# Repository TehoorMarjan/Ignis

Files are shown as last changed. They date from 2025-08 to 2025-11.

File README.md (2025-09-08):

# 🔥 Ignis Project - Ignis Lamp

An autonomous flame-shaped lamp/nightlight controlled by microcontroller with
WS2812B LED ring and **integrated Qi wireless charging**.

<p align="center">
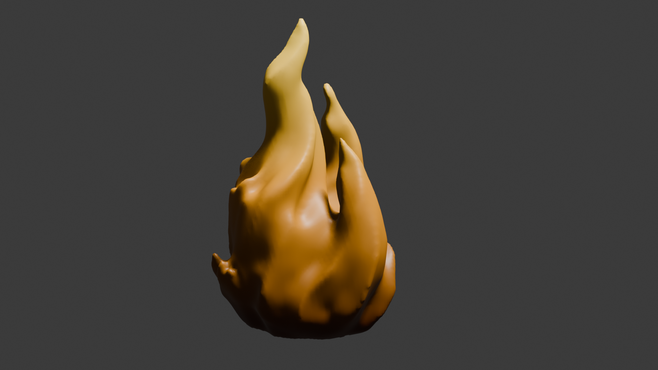
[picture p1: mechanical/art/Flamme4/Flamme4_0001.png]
Flamme4 Preview
  
</p>

**Status** : Hardware validated ✅ - Firmware development in progress  
**Last update** : September 2025

## 🎯 Objectives

- **Autonomy** : 2-3 hours on LiPo battery (320 mAh)
- **LED Patterns** : Heartbeat, chase, fade, realistic flame effects
- **Control** : SW-18030 shock detector for interaction
- **Charging** : **Qi wireless** + automatic power-path management
- **Waterproof** : No USB port, induction charging only

## ⚡ IgnisV2 Electrical Architecture

```mermaid
flowchart TD
  QiCharger["📡 BQ51013B<br/>Qi Charger"] ==> Charger["🔌 BQ24073<br/>Battery Charger"]
  Charger <==> Battery["🔋 LiPo Battery<br/>320mAh"]
  Charger ==> Boost["⚡ FP6277 Boost<br/>3.7V → 5V"]

  subgraph SYS["System"]
    MCU["🖥️ ATtiny212 @ 20MHz"]
    ShockSensor["💥 SW-18030<br/>Shock Sensor"]
    MCU -. "User Interaction" .- ShockSensor
    MCU --> WS2812B["💡 WS2812B<br/>6 LEDs"]
  end

  Boost ==> SYS
  Charger -. "Charge Status" .-> MCU
  QiCharger -. "Coil Status" .-> MCU
```

## 📚 Documentation

This repository contains comprehensive documentation for all aspects of the
Ignis project. Navigate to the relevant sections based on your interests:

### 🎯 Project Management

- [📊 PROJECT_STATUS.md](PROJECT_STATUS.md) - Current project status,
  milestones, and development progress

### 💾 Firmware Development

- [🔧 firmware/README.md](firmware/README.md) - ATtiny212 firmware
  documentation, build instructions, and current implementation

### 🔌 Hardware Design

- [⚡ docs/calculations/electrical_design.md](docs/calculations/electrical_design.md) -
  Complete electrical calculations, component sizing, and power analysis
- [🔗 docs/references/schematics_references.md](docs/references/schematics_references.md) -
  Reference schematics and design patterns
- [📋 docs/datasheets/README.md](docs/datasheets/README.md) - Component
  datasheets and technical specifications

### 🎨 Mechanical Design

- [🖼️ mechanical/art/README.md](mechanical/art/README.md) - 3D artwork and
  Blender models (Flamme4 design)
- [🏗️ mechanical/cad/README.md](mechanical/cad/README.md) - CAD models,
  assemblies, and engineering drawings
- [🖨️ mechanical/stl/README.md](mechanical/stl/README.md) - 3D printable files
  and printing guidelines
- [📏 docs/calculations/filament.md](docs/calculations/filament.md) - 3D
  printing material calculations and optimization

---

**For Contributors**: Start with [PROJECT_STATUS.md](PROJECT_STATUS.md) to
understand current progress, then refer to the relevant documentation sections
above based on your area of contribution.

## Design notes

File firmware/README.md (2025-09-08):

# Ignis Firmware - Ignis Lamp

## Current Project Status

### ✅ Implemented Features

- **WS2812B LED Control** : Implementation with tinyNeoPixel library
- **Light Patterns** : Cycling pattern with 7 colors (Red, Green, Blue, Purple,
  Yellow, Cyan, White)
- **ATtiny212 Configuration** : PlatformIO configured for ATtiny212 (IgnisV2.2)
- **Basic Structure** : Code organized with board.h for hardware abstraction

### 🚧 To Implement

- **Power Management** : Sleep mode management with interrupt wake-up
- **Shock Sensor** : SW18030 integration for shake detection
- **Charge Detection** : Using CHRG_B, PGOOD_B, IND_B pins
- **Advanced Light Patterns** : Heartbeat, fade, realistic flame effects
- **Power Optimizations** : Sleep modes for battery conservation
- **Battery Management** : Charge level monitoring

## Hardware Configuration

- **Microcontroller** : ATtiny212 @ 20MHz (IgnisV2.2 PCB)
- **WS2812B Pin** : PA6 (PIN_LED = PIN_PA6)
- **Shock Sensor Pin** : PA7 (PIN_SSW = PIN_PA7) with RC filter + Schmitt
  trigger
- **Inductor Detection Pin** : PA1 (PIN_IND_B = PIN_PA1) - Low when inductor
  active
- **Battery Charging Pin** : PA2 (PIN_CHRG_B = PIN_PA2) - Low during charging
- **Charge Complete Pin** : PA3 (PIN_PGOOD_B = PIN_PA3) - Low when charging
  complete
- **UPDI Pin** : PA0 (PIN_UPDI = PIN_PA0) for programming
- **LED Count** : 6 WS2812B-2020 LEDs

## Power Management

The firmware aims to implement an optimized power management system:

1. **Active Mode** : WS2812B LED control, sensor monitoring
2. **Inactivity Detection** : Based on SW18030 shock sensor
3. **Sleep Mode** : `SLEEP_MODE_PWR_DOWN` for maximum autonomy
4. **Wake-up** : Interrupt on motion detection or charging
5. **Charge Monitoring** : Using BQ24073 pins for battery status

Test software showed that all 6 LEDs at full brightness consume around

$$
I_{max} = \boxed{380\,\text{mA}} \implies P_{max} = 1.9\,\text{W}
$$

As this is above 1C for the 320mAh battery, power management and brightness
control will be needed to ensure good battery life.

### Power Saving Strategy

- Disable ADC, SPI, timers in sleep mode
- Intelligent PWM for LED brightness control
- Automatic charging station detection (IND_B)
- Adaptive pattern management based on battery level

## Compilation

```bash
# Via VS Code PlatformIO
Ctrl+Shift+P -> "PlatformIO: Build"

# Or via terminal (if pio installed)
cd firmware/
pio run
```

## Upload/Debug

Pymcuprog configuration in `platformio.ini`:

- Programmer : `pymcuprog` via UART
- Device : `attiny212`
- Port : `$UPLOAD_PORT` (defined by PlatformIO)
- Speed : 115200 baud
- UPDI : Programming via PA0

**⚠️ Important** : Generally, the power supplied by the USB-to-serial adapter is
not sufficient to power the board during programming. Attach an external power
supply on the board, if possible by injecting 3.7V (same as battery pack) on the
VSYS drilled pad.

### Pymcuprog Installation

The `scripts/requirements.py` script automatically installs pymcuprog if needed.

```bash
# Manual installation if required
pip install pymcuprog
```

## Next Steps

1. **Hardware Validation** : Test pins and basic functions
2. **Light Patterns** : Implement realistic flame effects
3. **Shock Sensor** : SW18030 integration with interrupts
4. **Power Management** : Sleep modes and intelligent wake-up
5. **Battery Monitoring** : Charge and autonomy management
6. **Autonomy Tests** : Validate 2-3 hour target

## Debug and Development

- Code compiled and tested on IgnisV2.2 PCB
- Using tinyNeoPixel for WS2812B control
- Incremental development for hardware validation
- Power consumption and light pattern testing

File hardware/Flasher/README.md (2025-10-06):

# UPDI Programmer

A simple UPDI programmer for ATtiny and ATmega microcontrollers using a
USB-to-TTL adapter.

<p align="center">
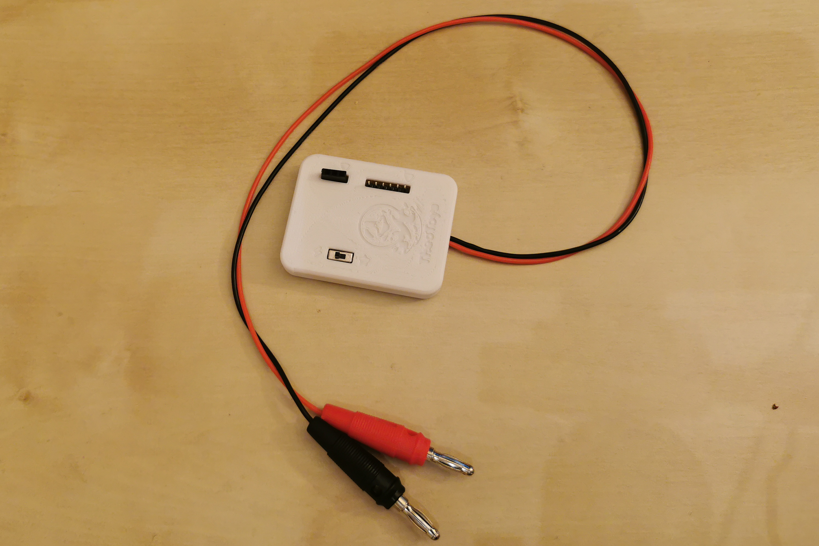
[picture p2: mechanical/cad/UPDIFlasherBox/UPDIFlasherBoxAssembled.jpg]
White 3D-printed UPDI programmer enclosure with black and red banana plug cables resting on a light wooden surface. The enclosure features a visible logo, a power selection switch, and connector ports.
  
</p>

## Overview

This project describes a minimalist UPDI (Unified Program and Debug Interface)
programmer designed for programming Microchip ATtiny and ATmega chips. UPDI is a
simple programming protocol that enables half-duplex communication on a single
wire to the bootloader, allowing reflashing of the device without requiring
complex programming hardware.

## What is UPDI?

UPDI (Unified Program and Debug Interface) is a Microchip-proprietary interface
for external programming and on-chip debugging. It is a successor to the PDI
interface and provides a single-wire, bidirectional half-duplex asynchronous
communication interface. UPDI requires only:

- **Single data wire (UPDI)** for bidirectional half-duplex communication
- **Ground connection (GND)**
- **Power supply (VCC)** - typically 5V for programming
- **Optional RESET line** for high-voltage activation on some devices

This single-wire interface makes it ideal for compact designs and simplified
programming setups compared to traditional 4-wire ISP/ICSP interfaces.

## Hardware Implementation

The implementation is remarkably simple, requiring only:

- A **USB-to-TTL adapter** (such as FTDI FT232RL or similar)
- A **single rectifier diode** between the RX and TX pins
- **Dupont connectors** for easy interfacing
- 2x wires and banana plugs for power connections
- A switch
- A protoboard (e.g., EPLZON)

### Circuit Design

The circuit uses a Schottky diode to combine the TX and RX signals from the UART
interface into a single bidirectional UPDI data line. The diode is connected
with its cathode to TX and its anode to RX, allowing this elegant solution to
enable standard UART hardware to communicate with the half-duplex UPDI protocol
at speeds up to 460800 baud (TURBO mode).

**Key Components:**

- 6-pin male Dupont connector for USB-TTL adapter (FTDI or compatible)
- 3-pin female Dupont connector for target device
- Schottky diode (e.g., CDBM1100-G or BAT85) for TX/RX signal combining
- Power source selection switch (USB-TTL or external power)

**Circuit Schematic:**

```
USB-TTL Adapter          Programmer Circuit          Target Device
                                                      __________________
    TX -------|<|-------,-------------------------- | UPDI
             diode      |                   .------ | GND
    RX -----------------'                   |       | VCC
    VCC --------------------------------------------|__________________
    GND -----------------------------------'
```

### Pinout

**6-Pin Male Connector (USB-TTL Side):** Standard FTDI TTL-232R cable pinout:

- Pin 1: GND (Black wire)
- Pin 2: CTS (Brown wire) - Not used
- Pin 3: VCC/5V (Red wire)
- Pin 4: TX (Orange wire)
- Pin 5: RX (Yellow wire)
- Pin 6: RTS (Green wire) - Not used

**3-Pin Female Connector (Target Device):**

1. **GND** - Ground
2. **Data** - UPDI signal line
3. **VCC** - Power supply (5V)

## Assembly

### Breadboard Prototype

The included Fritzing file (`Flasher.fzz`) provides a breadboard view showing
how components are wired. It is equivalent to how it should be assembled on a
protoboard.

<p align="center">
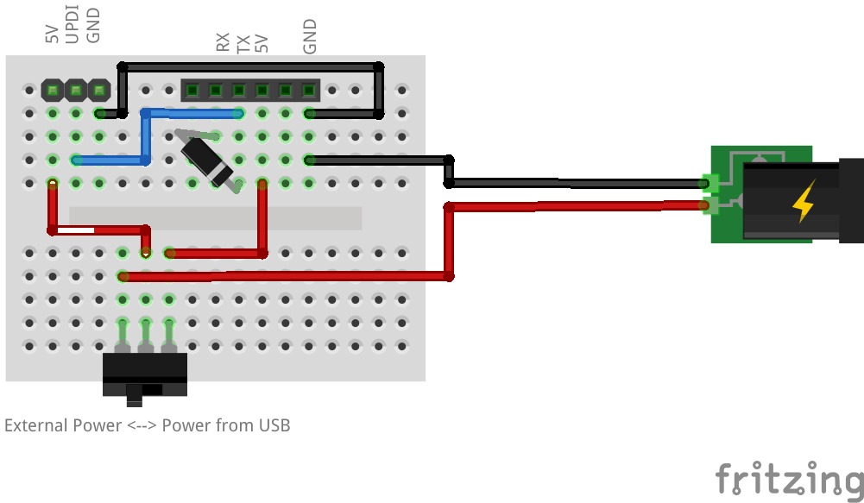
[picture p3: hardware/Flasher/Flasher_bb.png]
Breadboard Layout
  
</p>

## Enclosure

A 3D-printed enclosure is available in
[`/mechanical/cad/UPDIFlasherBox/`](../../mechanical/cad/UPDIFlasherBox/).

<p align="center">
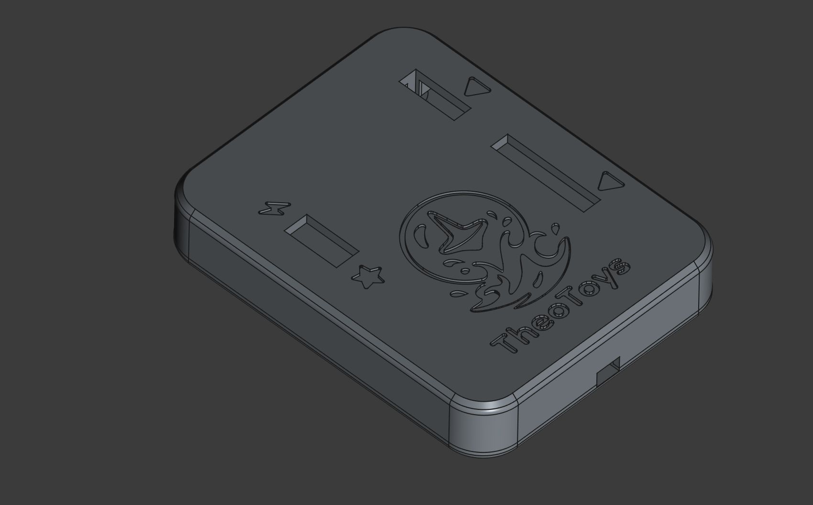
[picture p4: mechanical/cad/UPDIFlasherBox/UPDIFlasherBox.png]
3D render of a compact rectangular enclosure for a UPDI programmer, featuring rounded corners, engraved icons for power and function, a central flame logo, and the text TheoToys on the top surface. The enclosure has cutouts for switches and connectors.
  
</p>

**Features:**

- Custom-fitted for populated EPLZON protoboard
- Screw holes (M2) and slots for threaded inserts (M2xD3xL3)
- Connector access holes (6-pin and 3-pin)
- Switch cutout for power selection
- Side hole for external power cables
- Embossed markings showing:
  - GND pin position on both connectors
  - Power switch icons (USB/External)

**Files:**

- [`UPDIFlasherBox.FCStd`](../../mechanical/cad/UPDIFlasherBox/UPDIFlasherBox.FCStd) - FreeCAD source file
- [`UPDIFlasherBox-Top.stl`](../../mechanical/cad/UPDIFlasherBox/UPDIFlasherBox-Top.stl) - Top cover (ready to print)
- [`UPDIFlasherBox-Bottom.stl`](../../mechanical/cad/UPDIFlasherBox/UPDIFlasherBox-Bottom.stl) - Bottom base (ready to print)

## Additional Resources

### Official Documentation

- [Microchip UPDI Specification](https://onlinedocs.microchip.com/oxy/GUID-19DFE3E8-6314-4CFE-BA69-1357E28C8092-en-US-1/GUID-A2FD739F-A1D8-4C2F-9482-0B8AF9DCF435.html) -
  Official Microchip UPDI interface documentation
- [pymcuprog Tool](https://github.com/microchip-pic-avr-tools/pymcuprog) -
  Microchip's Python programming utility
- [megaTinyCore Library](https://github.com/SpenceKonde/megaTinyCore) - Arduino
  core for modern AVR chips
- [UPDI Protocol Overview](https://github.com/SpenceKonde/AVR-Guidance/blob/master/UPDI/UpdiProgramming.md) -
  Community documentation
- [Teddy Warner's SerialUPDI Guide](https://teddywarner.org/Projects/SerialUPDI/) -
  Excellent detailed tutorial
- [FTDI TTL-232R Cable Datasheet](https://ftdichip.com/wp-content/uploads/2023/07/DS_TTL-232R_CABLES.pdf) -
  Official cable pinout reference
- [EPLZON Protoboards](https://www.amazon.fr/EPLZON-prototypage-Breadboard-électronique-compatibles/dp/B0B4DFTTDR) -
  Recommended protoboard for assembly

## License

MIT License

Copyright (c) 2025 Ignis Project

Permission is hereby granted, free of charge, to any person obtaining a copy of
this software and associated documentation files (the "Software"), to deal in
the Software without restriction, including without limitation the rights to
use, copy, modify, merge, publish, distribute, sublicense, and/or sell copies of
the Software, and to permit persons to whom the Software is furnished to do so,
subject to the following conditions:

The above copyright notice and this permission notice shall be included in all
copies or substantial portions of the Software.

THE SOFTWARE IS PROVIDED "AS IS", WITHOUT WARRANTY OF ANY KIND, EXPRESS OR
IMPLIED, INCLUDING BUT NOT LIMITED TO THE WARRANTIES OF MERCHANTABILITY, FITNESS
FOR A PARTICULAR PURPOSE AND NONINFRINGEMENT. IN NO EVENT SHALL THE AUTHORS OR
COPYRIGHT HOLDERS BE LIABLE FOR ANY CLAIM, DAMAGES OR OTHER LIABILITY, WHETHER
IN AN ACTION OF CONTRACT, TORT OR OTHERWISE, ARISING FROM, OUT OF OR IN
CONNECTION WITH THE SOFTWARE OR THE USE OR OTHER DEALINGS IN THE SOFTWARE.

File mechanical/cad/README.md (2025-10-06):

# 🔧 Mechanical CAD - Projet Ignis

This folder contains all the CAD models and mechanical designs for the Ignis
project, created using **FreeCAD**. These models support the hardware
development, PCB visualization, and testing workflow.

## 🧩 SW18030 Shock Sensor

<p align="center">
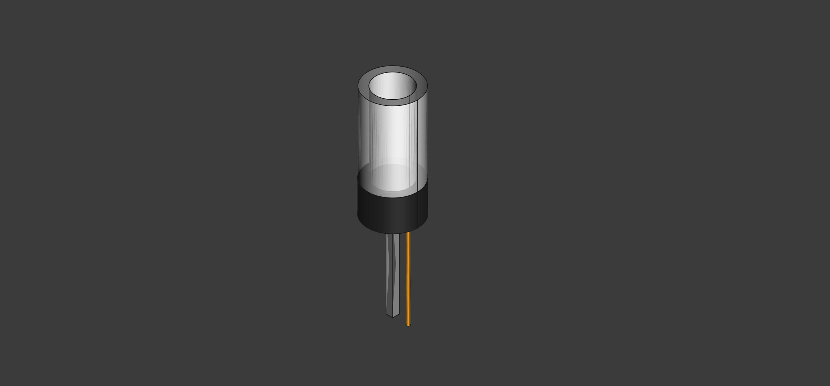
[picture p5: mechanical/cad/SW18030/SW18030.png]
SW18030 3D Model
  
</p>

Custom 3D model of the SW18030 vibration/shock sensor since it's not available
in standard CAD/footprint databases.

- Not fully detailed model - focused on mechanical envelope and mounting points
- Proper dimensions for mechanical clearance checks

## 🧩 Battery Pack Model

<p align="center">
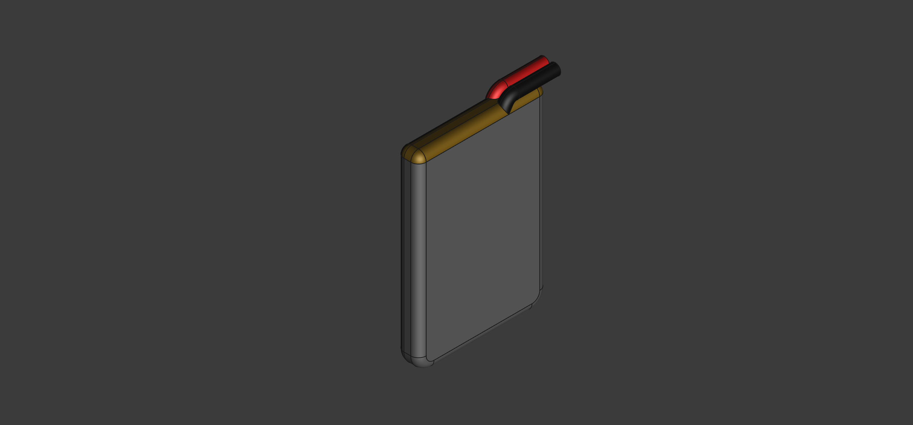
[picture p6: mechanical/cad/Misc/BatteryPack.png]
Battery Pack 3D Model
  
</p>

3D representation of the EEMB LP402535 (320mAh) LiPo battery for integration
visualization.

**Specifications**:

- Dimensions: 35×25×4mm (matches datasheet)
- Wire placement and routing visualization
- Proper dimensions for mechanical clearance checks

## 🧩 Qi Receiver Coil Model

<p align="center">
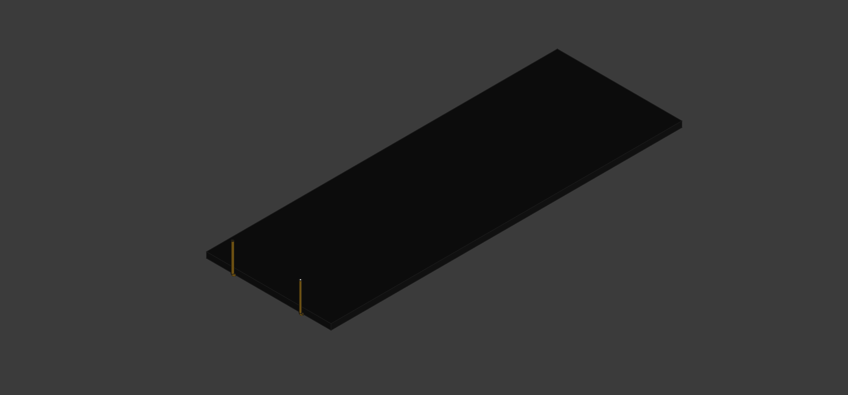
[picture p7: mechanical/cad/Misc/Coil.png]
Qi Coil 3D Model
  
</p>

Quick 3D model of the IWAS3010AZEB130KF1 Qi receiver coil for mechanical
integration.

- Dimensions: 30×10×1mm (rectangular coil)
- Wire routing and connection points
- Simplified geometry focused on mechanical envelope - actual coil winding not
  modeled in detail.

## 🧩 TestStand - PCB Test Fixture

<p align="center">
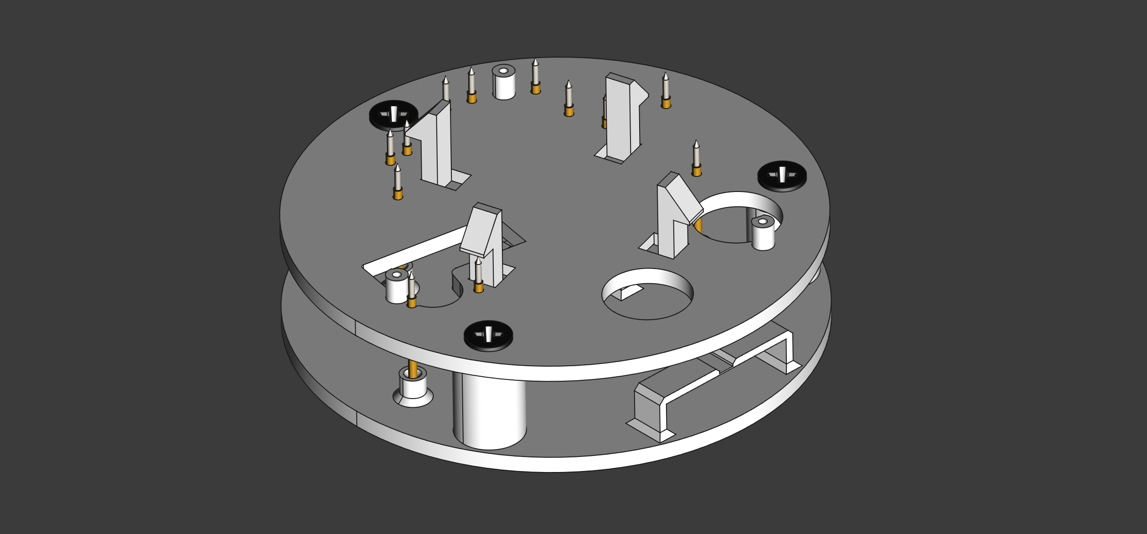
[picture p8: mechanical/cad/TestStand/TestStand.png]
TestStand 3D Model
  
</p>

<p align="center">
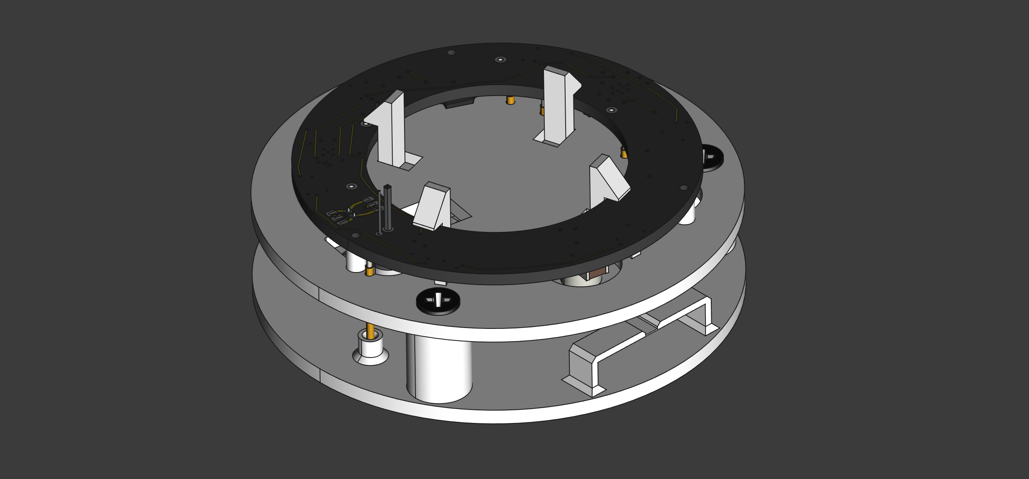
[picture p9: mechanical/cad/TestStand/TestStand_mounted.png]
TestStand Mounted View
  
</p>

<p align="center">
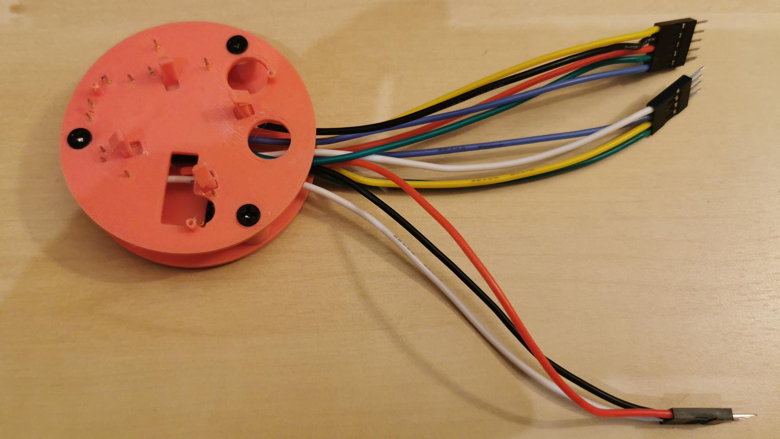
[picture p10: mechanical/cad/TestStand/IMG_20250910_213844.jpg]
TestStand Mounted View
  
</p>

Custom test fixture for IgnisV2.2 PCB programming and validation with pogo pin
connections.

**Files**:

- `TestStand.FCStd` - FreeCAD source file
- `TestStand-Top.stl` - Upper part for 3D printing
- `TestStand-Bottom.stl` - Lower part with pogo pin holders
- `TestStand-Hook.stl` - PCB retention hooks

**Features**:

- Positioned pogo pins to match IgnisV2.2 test pads
- Top and Bottom disks to hold the pogo pins securely
- Hooks hold board under test in position
- Cable management

### ⚠️ Version 1 - Known Issues

1. **Hook attachment**: Difficult to glue hooks on top part - redesign needed
2. **Cable holders**: Too fragile, already broken on printed version
3. **Pogo pins**: Missing pins for drilled pads (pins are too thin)

**Note**: It was expected that the pogo pins would not fit the drilled pads
because it was planned to hook cables. This works great, but finally it is nice
also that the testing stand can access all the pads at the same time. And I
forgot to add specific testing pads for the signals that already had drilled
pads.

**Note**: Next time, I shall pay more attention to the position of the testing
pads with respect to the other components and mounting holes. It is clear from
this test stand that some pads are difficult to reach, specially when a
component needs a clearance in the Top part because it is too tall. Also, I've
read that testing pads are better placed on the rear side of the PCB. I've read
that too late in the design process and now I understand why!

## 🧩 TestStand V2 - PCB Test Fixture

<p align="center">
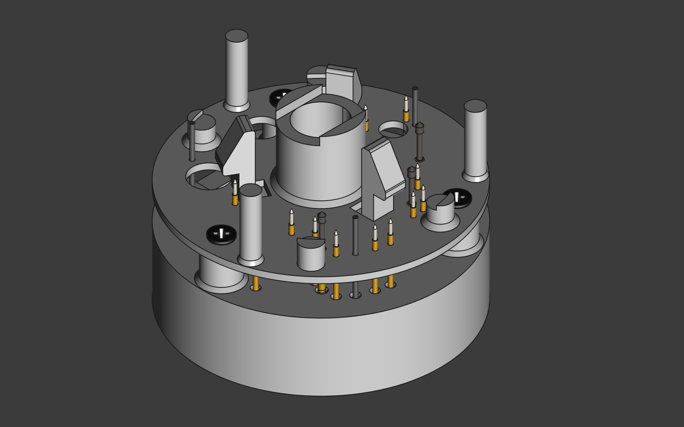
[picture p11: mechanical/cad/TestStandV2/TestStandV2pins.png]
TestStand 3D Model
  
</p>

<p align="center">
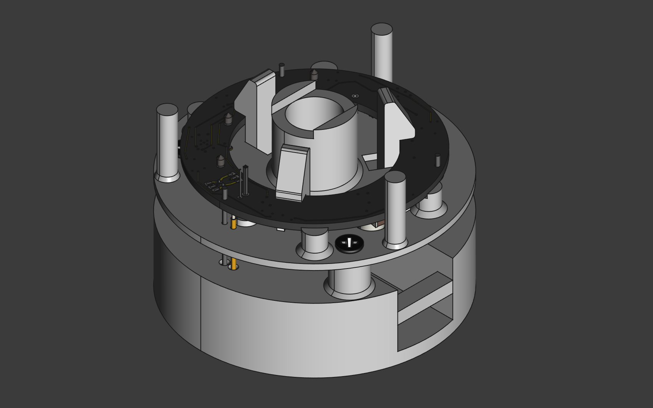
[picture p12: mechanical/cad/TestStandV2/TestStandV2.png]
TestStand Mounted View
  
</p>

<p align="center">
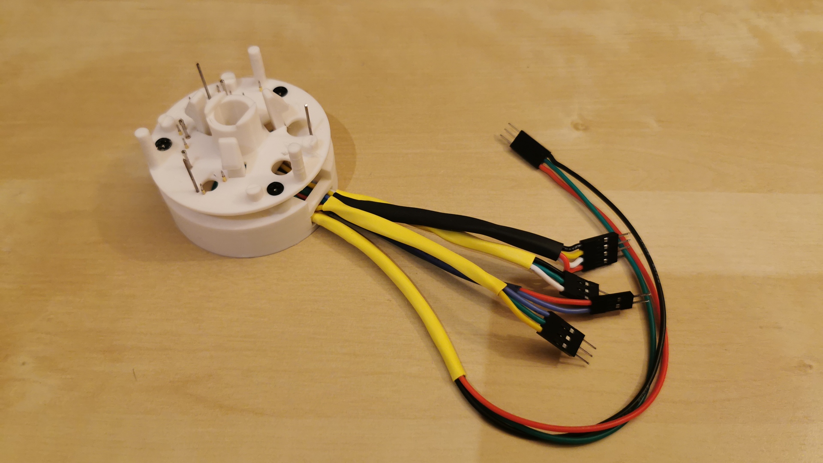
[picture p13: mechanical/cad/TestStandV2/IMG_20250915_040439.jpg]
TestStand Real View
  
</p>

<p align="center">
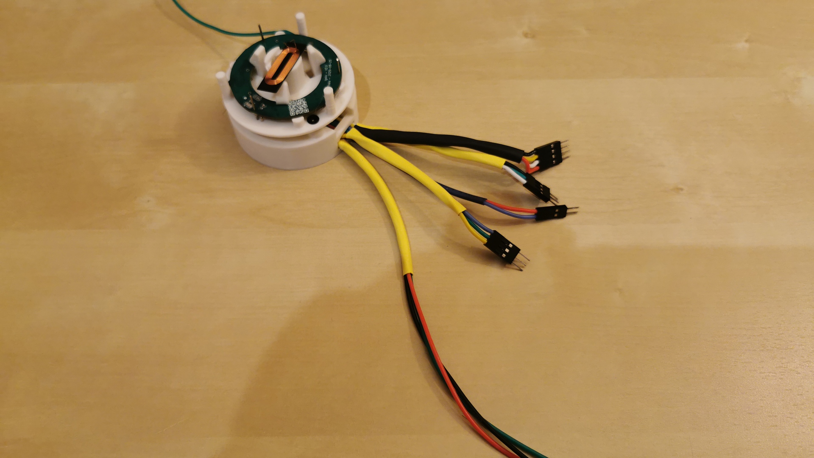
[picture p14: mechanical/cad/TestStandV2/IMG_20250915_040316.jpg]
TestStand Real Mounted View
  
</p>

Custom test fixture for IgnisV2.2 PCB programming and validation with pogo pin
connections.!

**Files**:

- `TestStandV2.FCStd` - FreeCAD source file
- `TestStandV2-Guide.stl` - Upper part for 3D printing
- `TestStandV2-Base.stl` - Lower part with pogo pin holders
- `TestStandV2-Hook.stl` - PCB retention hooks
- `TestStandV2.3mf` - 3D model file for 3D printing (OrcaSlicer)
- `IgnisV2TP.csv` - Test pad assignment to connector, position and cable colors

**Features**:

- Positioned pogo pins to match IgnisV2.2 test pads and drilled holes
- Base and Guide disks to hold the pogo pins securely
- Sticks to guide the PCB through its testing holes
- Hooks hold board under test in position
- Cable management

## 🧩 UPDI Flasher Box

<p align="center">
  UPDI Flasher Box 3D Model
</p>

<p align="center">
  UPDI Flasher Box Real Assembly
</p>

Custom enclosure for the UPDI programmer used to flash the ATtiny212 microcontroller on the Ignis board.

**Files**:

- `UPDIFlasherBox.FCStd` - FreeCAD source file
- `UPDIFlasherBox-Top.stl` - Upper part for 3D printing
- `UPDIFlasherBox-Bottom.stl` - Lower part for 3D printing

**Features**:

- Simple single-wire UPDI protocol implementation using UART (RX/TX)
- Diode-based direction selection for RX/TX communication
- Built on protoboard for easy prototyping and modifications
- Power selection switch between USB power and external PSU
- Two-wire connection for external power supply (standard PSU)
- Compact enclosure protecting the protoboard circuit
- Easy access to programming connections

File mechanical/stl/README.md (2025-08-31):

# 🧊 STL & Exports Imprimables - Projet Ignis

Ce dossier regroupe les fichiers STL prêts pour l'impression 3D, issus des
modèles artistiques du projet Lampe Ignis.

## 📚 Contexte

Les modèles originaux sont créés sous Blender (`art/<model>.blend`), puis
exportés en STL (`art/<model>.stl`). Pour garantir une impression fiable et des
unités correctes, les fichiers STL sont retravaillés sous OrcaSlicer :

- **Import STL Blender**
- **Conversion unités en mm**
- **Simplification et nettoyage du maillage**
- **Export final** : `stl/<model>.stl`

Pour plus d'informations sur le contexte artistique, voir le
[README du dossier art](../art/README.md).

## 🛠️ Workflow d'export

1. **Modélisation** : Blender (`art/<model>.blend`)
2. **Export STL** : Blender (`art/<model>.stl`)
3. **Nettoyage** : OrcaSlicer (`stl/<model>.stl`)
   - Conversion unités
   - Simplification du maillage
   - Vérification de l'intégrité

> Un remaillage avancé sous Blender serait probablement plus puissant, mais
> OrcaSlicer offre une solution rapide et efficace pour préparer les fichiers à
> l'impression.

## 📁 Organisation

- `stl/Flamme1.stl` : Export final du design Flamme1
- `stl/Flamme2.stl` : Export final du design Flamme2
- `stl/Flamme3.stl` : Export final du design Flamme3 (Flamme3_4)

---

**Pour toute information sur les modèles originaux ou le contexte artistique,
consultez le README du dossier art.**

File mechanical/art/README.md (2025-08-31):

# 🖼️ Art & Design - Lampe Ignis

Ce dossier regroupe les modèles artistiques 3D pour la Lampe Ignis, une lampe en
forme de flamme.

## 📚 Contexte

La Lampe Ignis est une veilleuse autonome en forme de flamme, pilotée par
microcontrôleur et LEDs adressables. Sa particularité : le socle contient du
sable, renfermant un élément mystérieux ou précieux, renforçant l'aspect
décoratif et symbolique du projet. Pour plus d'informations sur l'architecture,
l'électronique et le firmware, consultez les README principaux :

- [README général](../../README.md)
- [README firmware](../../firmware/README.md)
- [README datasheets](../../docs/datasheets/README.md)

## 🎨 Versions de Design

### Flamme1

- **Description** : Design simple, représentant uniquement la flamme.
- **Fichiers** :
  - [`Flamme1.blend`](Flamme1/Flamme1.blend) (modèle Blender)
  - [`Flamme1.stl`](Flamme1/Flamme1.stl) (export impression 3D)
  - [`Flamme1_0001.png`](Flamme1/Flamme1_0001.png) (screenshot)

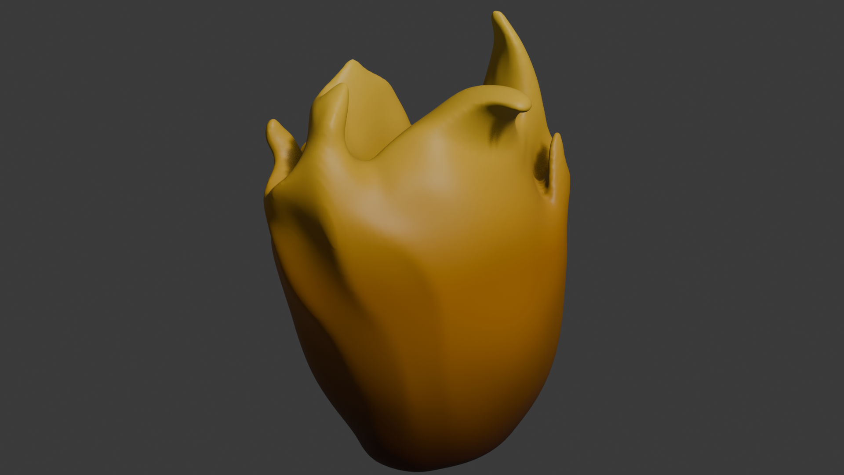
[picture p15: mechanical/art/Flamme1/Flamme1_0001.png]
Screenshot Flamme1


### Flamme2

- **Description** : Variante du design Flamme1, avec un "visage" retravaillé et
  ajout d'yeux.
- **Fichiers** :
  - [`Flamme2.blend`](Flamme2/Flamme2.blend) (modèle Blender)
  - [`Flamme2.stl`](Flamme2/Flamme2.stl) (export impression 3D)
  - [`Flamme2_0000.png`](Flamme2/Flamme2_0000.png) (screenshot)

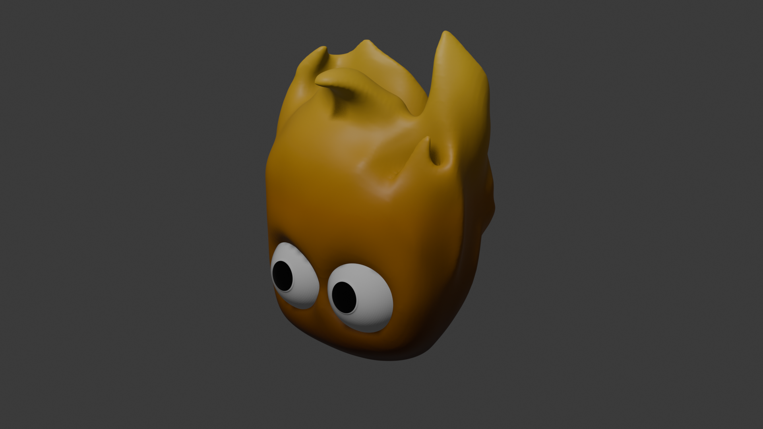
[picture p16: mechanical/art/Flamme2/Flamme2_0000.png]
Screenshot Flamme2


### Flamme1 - Low Poly

- **Description** : Version simplifiée et stylisée de Flamme1, avec un maillage
  réduit pour un rendu low poly sympa. Les dimensions ont également été
  retravaillées (objet plus petit, 75cm de large, même proportions) et le
  fichier STL a les bonnes dimensions.
- **Fichiers** :
  - [`Flamme1_lowpoly.blend`](Flamme1/Flamme1_lowpoly.blend) (modèle Blender)
  - [`Flamme1_lowpoly.stl`](Flamme1/Flamme1_lowpoly.stl) (export impression 3D)
  - [`Flamme1_lowpoly_0001.png`](Flamme1/Flamme1_lowpoly_0001.png) (screenshot)

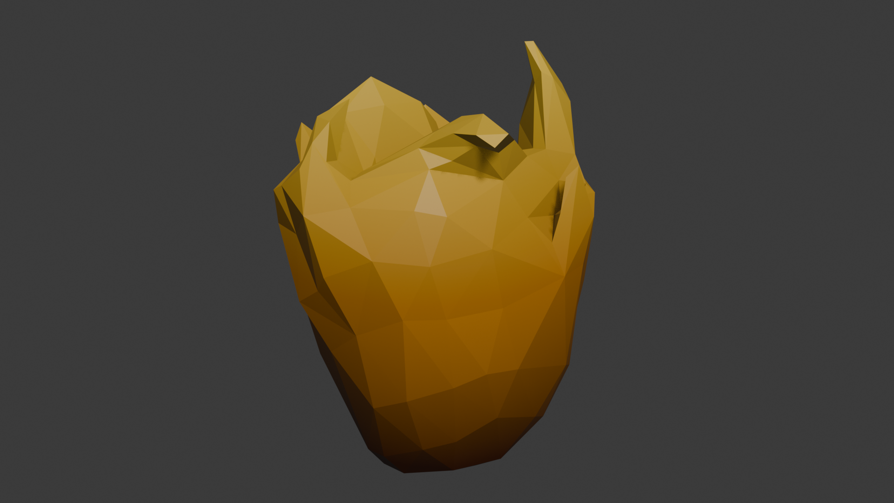
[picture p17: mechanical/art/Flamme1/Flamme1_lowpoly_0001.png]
Screenshot Flamme1 - Low Poly


### Flamme3_1

- **Description** : Premier essai pour designer une flamme à partir d'un mesh
  travaillé et des modifiers subdivision surface et deform (twist).
  **Abandonné**.
- **Fichiers** :
  - [`Flamme3_1.blend`](Flamme3/Flamme3_1.blend) (modèle Blender)
  - [`Flamme3_1_0001.png`](Flamme3/Flamme3_1_0001.png) (screenshot)

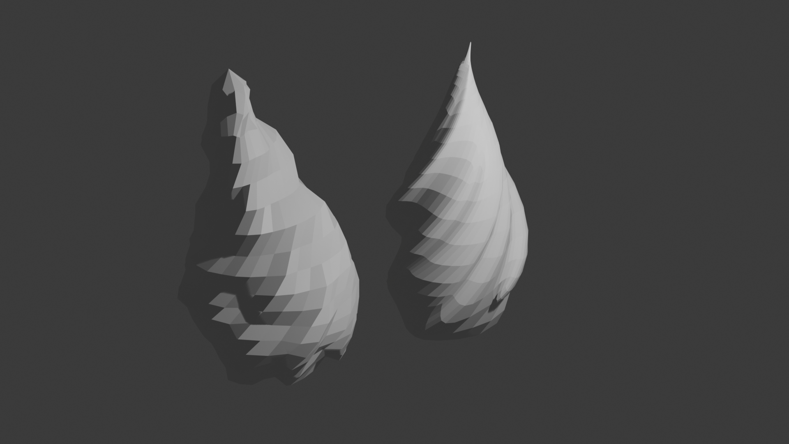
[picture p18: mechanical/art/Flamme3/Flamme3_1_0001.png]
Screenshot Flamme3_1


### Flamme3_2

- **Description** : Flamme créée à partir de meshs sphériques puis des modifiers
  Displace, Deform (Twist), Curve et autres. Sert de base aux versions
  suivantes.
- **Fichiers** :
  - [`Flamme3_2.blend`](Flamme3/Flamme3_2.blend) (modèle Blender)
  - [`Flamme3_2_0001.png`](Flamme3/Flamme3_2_0001.png) (screenshot)

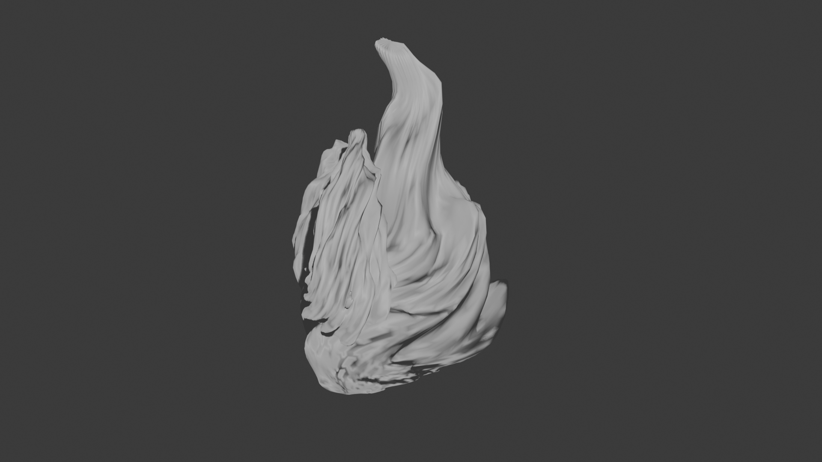
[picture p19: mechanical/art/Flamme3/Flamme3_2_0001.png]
Screenshot Flamme3_2


### Flamme3_3

- **Description** : Mesh de Flamme3_2 combiné et sculpté, mais beaucoup de
  détails perdus pendant la sculpture.
- **Fichiers** :
  - [`Flamme3_3.blend`](Flamme3/Flamme3_3.blend) (modèle Blender)
  - [`Flamme3_3_0001.png`](Flamme3/Flamme3_3_0001.png) (screenshot)

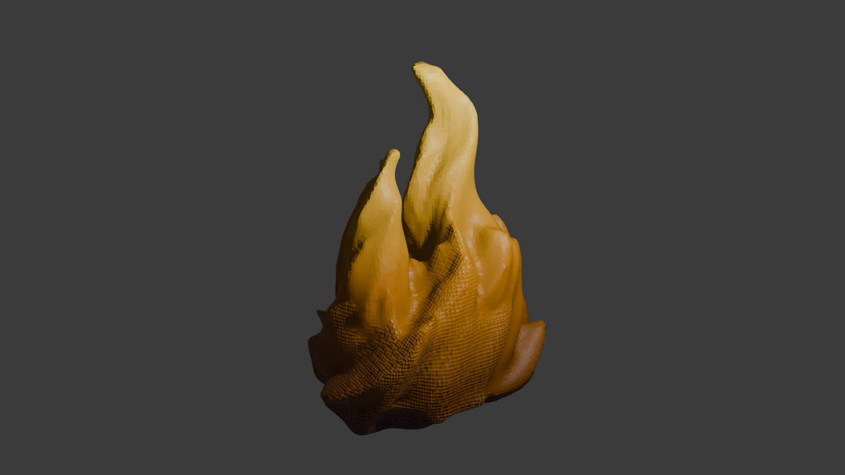
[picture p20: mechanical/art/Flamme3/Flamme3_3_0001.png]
Screenshot Flamme3_3


### Flamme3_4

- **Description** : Mesh de Flamme3_2 repris à zéro et sculpté plus doucement.
- **Fichiers** :
  - [`Flamme3_4.blend`](Flamme3/Flamme3_4.blend) (modèle Blender)
  - [`Flamme3_4.stl`](Flamme3/Flamme3_4.stl) (export impression 3D)
  - [`Flamme3_4_0001.png`](Flamme3/Flamme3_4_0001.png) (screenshot)

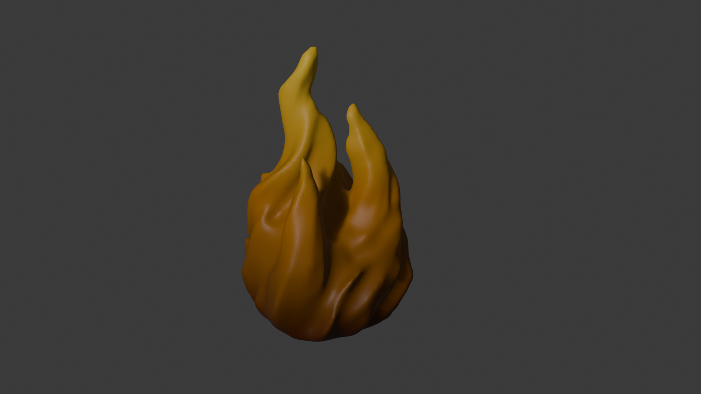
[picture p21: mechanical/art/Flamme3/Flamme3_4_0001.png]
Screenshot Flamme3_4


### Flamme4 ⭐

- **Description** : Mesh de Flamme3_4 repris pour régler les problèmes de
  surplombs et créer une épaisseur, puis sculpté de l'intérieur pour éviter les
  surplombs internes, puisque la forme est désormais creuse.
- Note : Les unités sont mieux paramétrées dans ce fichier, l'export STL est
  propre, mais uniquement si la case "Include Units" n'est _pas_ cochée.
- **Fichiers** :
  - [`Flamme4.blend`](Flamme4/Flamme4.blend) (modèle Blender)
  - [`Flamme4.stl`](Flamme4/Flamme4.stl) (export impression 3D)
  - [`Flamme4_0001.png`](Flamme4/Flamme4_0001.png) (screenshot)

Screenshot Flamme4

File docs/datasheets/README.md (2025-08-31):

# 📋 Datasheets - Projet Ignis

Index des datasheets téléchargées pour le projet Lampe Ignis.

## 🔗 Composants Principaux

| Composant | Fichier | Description |
| --- | --- | --- |
| **ATtiny212** | [`ATtiny212_datasheet.pdf`](ATtiny212_datasheet.pdf) | Microcontrôleur principal, ultra-low-power |
| **WS2812B** | [`WS2812B_datasheet.pdf`](WS2812B_datasheet.pdf) | LEDs adressables RGB, 5V |
| **TP4056** | [`TP4056_datasheet.pdf`](TP4056_datasheet.pdf) | Contrôleur de charge LiPo |
| **FP6277** | [`FP6277_datasheet.pdf`](FP6277_datasheet.pdf) | Boost converter synchrone 5V |
| **DMP1045U** | [`DMP1045U_datasheet.pdf`](DMP1045U_datasheet.pdf) | P-MOSFET pour power-path management |
| **EEMB LP402535** | [`EEMB_LP402535_datasheet.pdf`](EEMB_LP402535_datasheet.pdf) | Batterie LiPo 320mAh |

## 📊 Caractéristiques Clés

### ATtiny212

- **Architecture** : AVR 8-bit RISC
- **Flash** : 2KB
- **RAM** : 128 bytes
- **EEPROM** : 64 bytes
- **Fréquence** : jusqu'à 20 MHz
- **Alimentation** : 1.8V - 5.5V
- **Programmation** : UPDI

### WS2812B

- **Type** : LED RGB intégrée avec driver
- **Alimentation** : 5V ± 0.5V
- **Courant** : ~60mA max par LED
- **Interface** : Signal digital unique
- **Protocole** : PWM temporisé

### TP4056

- **Type** : Contrôleur de charge Li-Ion/LiPo
- **Tension charge** : 4.2V ± 1%
- **Courant** : Programmable via résistance (jusqu'à 1A)
- **Protection** : Surtension, surintensité, thermique
- **Package** : SOP-8

### FP6277

- **Type** : Boost converter synchrone
- **Tension entrée** : 0.9V - 5V
- **Tension sortie** : 5V fixe
- **Courant** : jusqu'à 1.5A
- **Efficacité** : >90%
- **Fréquence commutation** : 1.2MHz

### DMP1045U

- **Type** : P-Channel Enhancement MOSFET
- **VDS max** : -30V
- **ID max** : -4.2A
- **RDS(on)** : 45mΩ @ -4.5V
- **Package** : SOT-23

### EEMB LP402535

- **Capacité nominale** : 320mAh
- **Tension nominale** : 3.7V
- **Courant décharge max** : 2C (640mA)
- **Courant recommandé** : 1C (320mA)
- **Cycles** : >500 cycles
- **Dimensions** : 35×25×4.0mm

## 🔧 Notes de Conception

### Courant Total Estimé

- 8 LEDs × 60mA = 480mA max
- ATtiny212 = ~5mA
- **Total** : ~485mA (1.5C de la batterie)

⚠️ **Attention** : Prévoir limitation logicielle pour rester sous 1C (320mA) en
usage continu

### Efficacité Boost

- Perte boost converter ~10%
- Courant batterie estimé : 485mA / 0.9 ≈ 540mA
- **Autonomie estimée** : 320mAh / 540mA ≈ 35 minutes à pleine puissance

### Recommandations

1. Limiter brightness des LEDs (PWM ~50%)
2. Patterns optimisés (pas toutes LEDs simultanément)
3. Sleep mode agressif quand inactif

## 📁 Organisation

```
docs/datasheets/
├── ATtiny212_datasheet.pdf      # MCU principal
├── WS2812B_datasheet.pdf        # LEDs RGB
├── TP4056_datasheet.pdf         # Chargeur LiPo
├── FP6277_datasheet.pdf         # Boost 5V
├── DMP1045U_datasheet.pdf       # Power-path MOSFET
├── EEMB_LP402535_datasheet.pdf  # Batterie LiPo
└── README.md                    # Ce fichier
```

---

**Dernière mise à jour** : 15 août 2025  
**Status** : Datasheets complètes ✅

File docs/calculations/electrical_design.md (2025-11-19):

# Electrical Calculations - Ignis Project

## Battery and Consumption Calculations

### EEMB LP402535 Battery (320 mAh)

- Nominal capacity: 320 mAh
- Nominal voltage: 3.7 V
- Internal resistance: 160 mΩ
- Charging:
  - Maximum current: 320 mA (1C)
  - Maximum voltage: 4.2 V
  - End-of-charge current: 6.4 mA
- Discharge:
  - Maximum current: 2C = 640 mA
  - Minimum voltage: 2.75 V
- Operating temperature:
  - Discharge: -20 °C to +60 °C
  - Charge: 0 °C to +45 °C

### Current Consumption per Component

| Component | Current (mA) | Notes |
| --- | --- | --- |
| ATtiny212 (active) | 3–5 | @ 20 MHz, 5 V |
| ATtiny212 (sleep)  | 0.1–1 | Power-down mode |
| WS2812B (per LED)  | 0.3–60 | 0.3 mA off, 60 mA full white |
| MCP73871 (standby) | 18 µA | Very low in standby |
| BQ51013B (standby) | 30 µA | Inactive Qi receiver |
| FP6277 (standby) | 50–100 µA | Very low in standby |

### Usage Scenarios

#### Scenario 1: 6 LEDs, 50% brightness

```
LEDs: 6 × 30 mA = 180 mA
MCU: 5 mA
Boost: 2 mA (estimated losses)
TOTAL: ~187 mA

Runtime: 320 mAh / 187 mA = 1.7 hours
```

#### Scenario 2: 8 LEDs, 75% brightness

```
LEDs: 8 × 45 mA = 360 mA
MCU: 5 mA
Boost: 3 mA
TOTAL: ~368 mA

Runtime: 320 mAh / 368 mA = 0.87 hours
⚠️ Exceeds recommended 1C, OK for occasional use
```

#### Scenario 3: Standby mode (patterns off)

```
MCU (sleep): 0.5 mA
LEDs (off): 8 × 0.3 = 2.4 mA
Boost (standby): 0.1 mA
TOTAL: ~3 mA

Runtime: 320 mAh / 3 mA = 106 hours (4.4 days)
```

## Qi Receiver - BQ51013B

### General Characteristics

- **Type**: Qi receiver WPC v1.2 (BPP - Baseline Power Profile)
- **Power**: Up to 5 W
- **Output voltage**: Regulated 5 V
- **Max current**: 1 A
- **Frequency**: 100–250 kHz (WPC band)
- **Communication**: ASK/FSK with transmitter
- **FOD**: Built-in Foreign Object Detection

### Receiver Coil - IWAS3010AZEB130KF1 (Vishay)

**Specifications**:

- Dimensions: 30 mm × 10 mm (rectangular shape)
- Inductance: 12.9 µH @ 100 kHz
- Quality factor Q: 11
- DC resistance: 780 mΩ
- Max power: 3.5 W
- Max current: 800 mA
- Qi compliance: WPC v1.2

### Resonant Capacitor Calculations

The BQ51013B requires two resonant capacitors:

**C1 (series)** – Main resonant capacitor:
$$C_1 = \frac{1}{(2\pi \times f_S)^2 \times L_S^\prime}$$

With $L_S^\prime \approx 15\,\mu H$ in our case (to be confirmed) and
$f_S = 100\,\text{kHz}$ (from the BQ51013B documentation):

$$C_1 \approx 168{,}868\,\text{nF}$$

We can choose $C_1 = 150\,\text{nF}$ or
$C_1 = 150\,\text{nF} + 15\,\text{nF} = 165\,\text{nF}$. At this stage this is
an implementation detail. To some extent, the 2-capacitor version can offer
better tunability, especially since $L_S^\prime$ is not fully known at this
point. The frequency error would then be $\leq 2.7\%$.

**C2 (parallel)** – Fine-tuning capacitor:

With $L_S = 12.9\,\mu H$ (unloaded inductance, from the coil datasheet) and
$f_D = 1\,\text{MHz}$ (from the BQ51013B datasheet):

$$C_2 = \frac{1}{(2\pi \times f_D)^2 \times L_S - \frac{1}{C_1}}$$

which gives $C_2 \approx 1.987\,\text{nF} \text{ to } 1.989\,\text{nF}$
depending on whether $C_1 = 165\,\text{nF}$ or $C_1 = 150\,\text{nF}$ is chosen,
i.e. practically no difference. We can therefore choose $C_2 = 2\,\text{nF}$ or
$C_2 = 1\,\text{nF} + 1\,\text{nF}$.

### R_ILIM Calculation

The current limit of the BQ51013B is set via resistor $R_{ILIM}$ according to:

$$
R_{ILIM} = \frac{K_{ILIM}}{I_{MAX}}
$$

where $K_{ILIM}$ is given in the datasheet ($614\,\Omega\text{A}$), and
$I_{MAX}$ is the desired maximum current.

The datasheet specifies that the actual limit current is:

$$
I_{ILIM} = 1.2 \times I_{MAX} = \frac{K_{ILIM}}{R_{ILIM}}
$$

$R_{ILIM}$ is the sum of two resistors:

$$
R_{ILIM} = R_1 + R_{FOD}
$$

with $R_{FOD}$ by default at $196\,\Omega$.

For $I_{MAX} \geq 600\,\text{mA}$, $I_{ILIM} = 720\,\text{mA}$

$$
R_{ILIM} = \frac{614}{0.72} \approx 436\,\Omega \implies R_1 = 240\,\Omega
$$

In practice, with $R_{FOD} = 196\,\Omega$, we choose $R_1 = 220\,\Omega$
(standard value):

$$
R_{ILIM} = 220 + 196 = 416\,\Omega \implies I_{ILIM} \approx 754\,\text{mA} \implies I_{MAX} \approx 629\,\text{mA}
$$

### BQ51013B Components

- C1a (series): 150 nF, 25 V, X7R
- C1b (series): 15 nF, 25 V, X7R
- C2a (parallel): 1 nF, 25 V, X7R
- C2b (parallel): 1 nF, 25 V, X7R
- C3 (RECT): 10 µF + 10 µF + 0.1 µF, 16 V
- C4 (OUT): 10 µF + 0.1 µF, 16 V
- C5 (BOOT): 10 nF, 25 V
- C6 (CLAMP): 470 nF, 25 V
- C7 (COMM): 47 nF, 25 V
- R1 (ILIM): 220 Ω
- Rfod (FOD): 196 Ω
- Ros (RECT): 20 kΩ

### Pin Configuration

- **AC1/AC2**: Receiver coil connection
- **RECT**: Rectified voltage (~8–10 V)
- **OUT**: Regulated 5 V output
- **AD**: Tied to GND via 1 µF (no dual-power management)
- **EN**: Enable, 10 kΩ pull-up to OUT
- **TS/CTRL**: Configuration, see datasheet

## Battery Charger - BQ24073

The BQ24073 from Texas Instruments is a switching Li-ion/Li-Po charger with
integrated power-path management:

- High-efficiency switching charger (vs linear)
- Automatic power-path management
- Compatible with Qi receiver BQ51013B (same manufacturer)
- Built-in thermal and electrical protection
- Status indication via CHG and PGOOD pins
- Input current management via EN1/EN2

### Charge Programming

The charge current is set via resistor $R_{ISET}$ connected from the ISET pin to
VSS: $$R_{ISET} = \frac{K_{ISET}}{I_{CHARGE}}$$

$$
K_{ISET} = 890\,\Omega\text{A} \implies R_{ISET} = \frac{890}{0.32} \approx 2781\,\Omega \approx \boxed{2.7\,k\Omega}
$$

$$
R_{TMR} = \frac{t_{MAXCHG}}{10 \times K_{TMR}}\,\text{with}\, K_{TMR} = 48 \text{s}/\text{k}\Omega
$$

For a 1 C charge (320 mA), the theoretical duration is 1 h. In practice, the
charge proceeds in two phases:

- **CC phase (constant current)**: 320 mA up to around 4.2 V, i.e. 40 to 50 min
  to reach 70 to 80% of the capacity.
- **CV phase (constant voltage)**: voltage remains at 4.2 V, current gradually
  decreases down to the termination threshold (typically 0.1 C to 0.05 C),
  adding 20 to 50 min.

As a rule of thumb:

- Termination at 0.1 C (32 mA): total duration 1.2 to 1.4 h.
- Termination at 0.05 C (16 mA): total duration 1.4 to 1.8 h.

A pre-charge at low current (0.05–0.1 C) can add 10 to 20 min if the cell is
very discharged.

We therefore take a typical charge time between 1.2 and 1.6 h at 1 C, depending
on termination threshold, temperature, and initial state of the battery.

We choose $t_{MAXCHG}$ as twice the expected duration to cover cases of reduced
current:

$$
t_{MAXCHG} = 2 \times 1.6\,\text{h} = 3.2\,\text{h} = 11\,520\,\text{s} \\
\implies R_{TMR} = \frac{11 520}{10 \times 48} = \boxed{24\,\text{k}\Omega}
$$

### Input Current Limitation

For this project, we use the programmable mode (EN2=1, EN1=0) to adjust the
input limit according to the Qi receiver capability. Compute $R_{ILIM}$ to set
the maximum current to ≤ 629 mA.

$$R_{ILIM} = \frac{K_{ILIM}}{I_{IN\_MAX}}$$

$$
K_{ILIM} = 1550\,\Omega\text{A} \implies R_{ILIM} = \frac{1550}{0.629} \approx 2.46\,k\Omega \approx \boxed{2.4\,k\Omega}
$$

### BQ24073 Components (to be used)

- C_IN: 1 µF, 16 V, X7R
- C_BAT: 4.7 µF, 16 V, X7R
- C_OUT: 4.7 µF, 16 V, X7R
- R_TS: 10 kΩ (fixed, replaces thermistor)
- R_ILIM: 2.4 kΩ
- R_ISET: 2.7 kΩ
- R_TMR: 24 kΩ

## FP6277 Boost Configuration

### Output Voltage Setting (5 V)

The output voltage is defined by the feedback divider:

$$
V_{out} = 0.6\,\text{V} \times \left(1 + \frac{R_1}{R_2}\right)
$$

For $V_{out} = 5\,\text{V}$:

$$
5 = 0.6 \times \left(1 + \frac{R_1}{R_2}\right) \\
\frac{R_1}{R_2} = \frac{5}{0.6} - 1 = 7.33
$$

If $R_2 = 10\,\text{k}\Omega$ then
$R_1 = 73.3\,\text{k}\Omega \approx 75\,\text{k}\Omega$

### Optimal Inductance Calculation

The optimal inductance for the FP6277 is given by:

$$
L = \frac{V_{in(max)} \times (V_{out} - V_{in(max)})}{V_{out} \times (\Delta I_L) \times f_{sw}}
$$

With:

- $V_{in(max)} = 4.2\,V$ (full battery)
- $V_{out} = 5.0\,V$
- $\Delta I_L = 500\,\text{mA} \times 30\% = 0.15\,A$ (30% ripple of average
  current)
- $f_{sw} = 1.4\,\text{MHz}$ (FP6277 frequency)

$$
L = \frac{4.2 \times (5.0 - 4.2)}{5.0 \times 0.15 \times 1.4 \times 10^6} = 3.2\,\mu H
$$

**Recommended inductance**: 3.3 µH (matches the reference design)

### Overcurrent Protection

The current limit of the FP6277 is set via a resistor between the OC pin and
ground:

$$
I_{OCP} = \frac{180\,000}{R_{OC}} + 0.2
$$

To set $I_{OCP} = 0.64\,\text{A}$ (640 mA, battery max):

$$
R_{OC} = \frac{180\,000}{0.44} = 409\,\text{k}\Omega \approx 390\,\text{k}\Omega
$$

**FP6277 Components**:

- L1: 3.3 µH inductor, saturation current > 1 A
- C1 (Vin): 22 µF, 16 V
- C2 (Vout): 22 µF, 16 V
- C3 (Vout): 100 µF, 16 V
- R1: 75 kΩ (feedback high)
- R2: 10 kΩ (feedback low)
- R3: 390 kΩ (OC)

## SW18030 Filter Calculation

The SW18030 is a shock sensor using a spring wound around a metal rod. On impact
or acceleration, the spring briefly touches the rod, generating a very short
contact. To stretch this signal and make it usable, an RC circuit is added to
extend the pulse width. To obtain a clean square signal, compatible with waking
up the ATtiny from sleep mode, a non-inverting Schmitt trigger buffer is placed
after the RC filter.

On impact, the SW18030 closes the contact for ~1 ms. To obtain a usable pulse,
the time constant of the RC filter must be much shorter than this duration.

**RC filter (fast charge):**

- Series resistor: $R_s$
- Capacitance: $C$
- Time constant: $\tau = R_s \times C$

For this project:

- $R_s = 470\,\Omega$
- $C = 22\,\text{nF}$
- $\tau = 470\,\Omega \times 22\,\text{nF} = 10{,}3\,\mu\text{s} \ll 1\,\text{ms}$

The capacitor charges almost instantly, allowing the signal to quickly reach the
upper Schmitt threshold ($V_T^+$).

**Discharge (pulse stretching):**

- Discharge resistor: $R_d$
- Pulse duration: $t = R_d \cdot C \cdot \ln\left(\frac{V_{CC}}{V_T^-}\right)$

For this project:

- Target $t \approx 15\,\text{ms}$
- $R_d = 680\,\text{k}\Omega$ (calculation gives
  $R_d \approx 667\,\text{k}\Omega$)
- $V_{CC} = 5\,\text{V}$
- $V_T^- = 1.8\,\text{V}$ (from datasheet)
- $t = 680\,\text{k}\Omega \times 22\,\text{nF} \times \ln\left(\frac{5}{1.8}\right) \approx 15.3\,\text{ms}$
  => OK

This time guarantees a pulse long enough to wake up the ATtiny in sleep mode,
without bounce-induced glitches.

**SW18030 Components**:

- Rs: 470 Ω
- Cs: 22 nF
- Rd: 680 kΩ
- 74LVC1G17: Schmitt trigger buffer (non-inverting).

## Thermal Budget

### Boost Converter Losses

```
Losses ≈ (Vout - Vin) × Iout / η

Worst case: Vin = 3.0 V, Vout = 5 V, Iout = 400 mA, η = 85%
Losses = (5 - 3) × 0.4 / 0.85 = 0.94 W
```

**Thermal management**:

- Thermal vias under FP6277
- Large ground plane
- Copper area for heat spreading

### BQ24073 Heating

Because the BQ24073 is a switching charger (vs linear), losses are reduced:

```
Losses ≈ 0.1 W @ 320 mA charge (efficiency ~90%)
ΔT ≈ 0.1 W / 8 mW/°C ≈ 12 °C temperature rise
```

### Battery Heating

LiPo internal resistance ≈ 100–200 mΩ

```
Battery losses = I² × Ri = 0.4² × 0.15 = 24 mW
ΔT ≈ 24 mW / 5 mW/°C = 5 °C temperature rise
```

## Protection and Safety

### Protection Thresholds

- **Minimum battery voltage**: 3.0 V (boost cutoff)
- **Max current**: 500 mA (software limit)
- **Max temperature**: 70 °C (monitoring if a sensor is added)
- **Qi FOD**: Automatic foreign object detection

## Brainstorming - Design Decision History

### Initial Issue: Wireless Charger

**Motivations for Qi**:

- Watertight enclosure (no USB port)
- Premium user experience
- Compatibility with commercial chargers

**Identified challenges**:

- Off-the-shelf modules too expensive (> €11)
- Excessive power (15 W vs 1.5–3 W needed)
- Coil footprint/size
- PCB integration complexity

### Receiver IC Choice

**Options evaluated**:

- **BQ51003**: 2.5 W, simpler but limited power
- **BQ51013B**: 5 W, more margin, excellent TI documentation
- **P9025AC (Renesas)**: Less public documentation

**Decision**: BQ51013B for the documentation and availability at LCSC (JLCPCB)

### Power System Evolution

**Version 1 (obsolete)**: TP4056 + DMP1045U

- Pros: Well-known components, many reference schematics
- Cons: DIY power-path, two separate ICs

**Version 2 (obsolete)**: MCP73871

- Pros: Integrated power-path, cleaner, better thermally
- Cons: Availability, cost

**Version 3 (current)**: BQ24073

- Pros: Same manufacturer as BQ51013B (TI), switching efficiency, integrated
  power-path
- Cons: More complex initial configuration

### Coil Choice

**Criteria**:

- Qi WPC v1.2 compliance
- Suitable dimensions (≤ 35 mm)
- Sufficient power rating (3 W+)
- Distributor availability

**Chosen IWAS3010AZEB130KF1**:

- 30 × 10 mm: compact for the flame enclosure
- 3.5 W: margin for consumption peaks
- Q = 11: compromise between efficiency and bandwidth
- Vishay: reliable brand, stock at Mouser/Digikey

### Power-Path Philosophy

**Two levels identified**:

1. **Upstream of the battery**: Source selection (USB/Qi/AC)
   - Not applicable here (single Qi source)
   - BQ51013B AD pin to GND
2. **Downstream of the battery**: System vs battery
   - Critical to avoid discharging the battery during charge
   - MCP73871 handles this automatically

### Trade-offs and Final Decisions

**Backfeed protection**: Not required because there are no multiple charge
sources (Qi only)

**Safety**: Prefer ICs with integrated protections (FOD, thermal shutdown)
versus external discrete circuits

**BOM**: Prefer integration vs cost (MCP73871 vs TP4056+DMP1045)

---

## Obsolete Components (Previous Design)

### MCP73871 - Charger with Integrated Power-Path

**Replaced by BQ24073**

Advantages of MCP73871:

- Li-ion/Li-Po charger with power-path management
- Automatic source selection (VIN/USB)
- Overcharge/overdischarge protection
- Status indication (LEDs)
- Thermal regulation

Power-path configuration:

- **VIN**: Main supply (BQ51013B output, 5 V)
- **VBAT**: Li-Po battery connection
- **VOUT**: System output (to FP6277 boost)
- **Power-path**: Automatic priority VIN > battery

Charge current programming: $$I_{CHARGE} = \frac{1000\text{V}}{R_{PROG}}$$

For 320 mA (optimal 1C): $R_{PROG} = 3.3\,\text{k}\Omega$

USB current limit: $$I_{USB} = \frac{515\text{V}}{R_{USB}}$$

For 500 mA max: $R_{USB} = 1\,\text{k}\Omega$

**MCP73871 Components**:

- RPROG: 3.3 kΩ (303 mA charge)
- RUSB: 1 kΩ (515 mA USB limit)
- C1 (VIN): 4.7 µF, 16 V
- C2 (VBAT): 4.7 µF, 16 V
- C3 (VOUT): 4.7 µF, 16 V

**Reasons for change**: Simpler BQ24073, better integration with Qi receiver
BQ51013B (same manufacturer)

### TP4056 - Linear Li-ion Charger

**Replaced by BQ24073**

Charge current programming via Rprog:
$$R_{PROG} = \frac{1100\,\text{V}}{I_{BAT}}$$

For 320 mA: $R_{PROG} = 3.9\,\text{k}\Omega$

**Drawbacks**:

- Linear charger → thermal dissipation
- No integrated power-path
- Requires external circuit for power switching

### DMP1045U - P-MOSFET Power-Path

**Replaced by BQ24073**

Automatic switchover circuit between USB and battery:

- Gate connected to USB via resistor divider
- Source on battery, drain to boost
- Logic: USB present = MOSFET OFF, absent = MOSFET ON

**Drawbacks**:

- Complex discrete circuit
- Critical tuning
- No integrated protections

---

**Last update**: August 2025  
**Validation status**: 🔧 Final design - Prototyping required

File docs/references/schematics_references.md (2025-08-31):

# Références Schémas - Projet Ignis

## Schémas de Référence

### 1. FP6277 Boost Converter

**Source** :
[LiPo Power Board FP6277 - wagiminator](https://github.com/wagiminator/Power-Boards/blob/master/LiPo_Power_Board_FP6277/LiPo_Power_Board_FP6277_schematic.pdf)

**Modifications pour Ignis** :

- **R6** : Changer de 27kΩ à 225kΩ pour limiter courant à 1A
- **Suppression DW01** : Pas de protection batterie intégrée (gérée par TP4056)
- **Sortie 5V** : R1=75kΩ, R2=10kΩ pour Vout=5V

### 2. TP4056 avec Load Sharing

**Source** :
[LiPo Charger LS TP4056 - wagiminator](https://github.com/wagiminator/Power-Boards/blob/master/LiPo_Charger_LS_TP4056/LiPo_Charger_LS_TP4056_schematic.pdf)

**Adaptations** :

- **Rprog** : 3.9kΩ pour 308mA de charge
- **Power-path** : Via DMP1045U au lieu de circuit intégré
- **Connecteur USB** : USB-C pour charge moderne

## Architecture Power-Path Ignis

```
     USB-C 5V
         │
         ├─── TP4056 (Charge) ─── VBAT (3.7V)
         │                          │
         │                          │
    DMP1045U ──────────────────────┘
      │
      └─── FP6277 (Boost) ─── VSYS (5V)
                                 │
                                 ├─── ATtiny212
                                 └─── WS2812B LEDs
```

## Pinout ATtiny212

```
                    ATtiny212
                  ┌─────────────┐
    VCC (5V) ──── │1  ●    8│ ──── GND
    PA6/UPDI ──── │2       7│ ──── PA3
    PA7      ──── │3       6│ ──── PA2
    PA1      ──── │4       5│ ──── PA0 (LED_DATA)
                  └─────────────┘
```

**Affectation pins** :

- **PA0 (Pin 5)** : DATA WS2812B
- **PA1 (Pin 4)** : BUTTON (avec pull-up)
- **PA2 (Pin 6)** : Réservé (expansion)
- **PA3 (Pin 7)** : Réservé (ADC batterie ?)
- **PA6 (Pin 2)** : UPDI (programmation)
- **PA7 (Pin 3)** : Réservé

## Connecteur Socle

### Pogo Pins (recommandé)

```
Socle → Bloc
[1] GND     ─── GND
[2] VSYS    ─── Alimentation 5V
[3] BUTTON  ─── PA1 (ATtiny212)
[4] UPDI    ─── PA6 (prog optionnelle)
```

### Alternative : Connecteur magnétique

- Utiliser connecteurs magnétiques 4 pins
- Polarité assurée par aimants
- Plus robuste que pogo pins

## Circuit de Détection Socle

```cpp
// Détection présence sur socle
bool isOnDock() {
  // Méthode 1 : Pull-up sur pin bouton
  // Si flottant (pas sur socle) → HIGH permanent
  // Si sur socle → possibilité LOW (bouton pressé)

  pinMode(BUTTON_PIN, INPUT);  // Pas de pull-up
  delay(1);
  bool floating = digitalRead(BUTTON_PIN);
  pinMode(BUTTON_PIN, INPUT_PULLUP);  // Remettre pull-up

  return !floating;  // Si pas flottant = sur socle
}
```

## Schéma Bloc Complet

```
    USB-C           TP4056          DMP1045U         FP6277
 ┌─────────┐    ┌────────────┐   ┌────────────┐   ┌──────────┐
 │  VBUS   ├────┤ VCC    BAT ├───┤ S      D   ├───┤ VIN  OUT ├─── VSYS (5V)
 │  D+     │    │            │   │  \    /    │   │          │
 │  D-     │    │        OUT ├─┐ │   ┘  ┌     │   │          │
 │  GND    ├────┤ GND    GND ├─┼─┤ GND  G     │   │ GND      ├─── GND
 └─────────┘    └────────────┘ │ └─────┬──────┘   └──────────┘
                                │       │ 10kΩ                    │
                           LiPo │       └──────                   │
                      320mAh ──┘              │                   │
                                              GND                 │
                                                                  │
                      ATtiny212                                   │
                 ┌────────────────┐                               │
          PA0 ───┤ LED_DATA   VCC ├───────────────────────────────┘
          PA1 ───┤ BUTTON     GND ├─── GND
          PA6 ───┤ UPDI           │
                 └────────────────┘
                        │
                        │ LED_DATA
                 ┌──────▼──────┐
                 │  WS2812B    │
                 │  Ring 8LEDs │
                 └─────────────┘
```

## Liste des Composants (BOM)

### Actifs

| Ref | Composant | Package | Valeur | Fournisseur | Prix (€) |
| --- | --- | --- | --- | --- | --- |
| U1 | ATtiny212 | SOIC-8  | - | Mouser | 1.20 |
| U2 | TP4056 | SOP-8 | - | LCSC | 0.30 |
| U3 | FP6277 | SOP-8 | - | LCSC | 0.80 |
| Q1 | DMP1045U  | SOT-23  | - | Mouser | 0.60 |
| LED1-8 | WS2812B | 5050 | - | AliExpress  | 1.00 |

### Passifs

| Ref | Composant | Package | Valeur | Notes |
| ----- | --- | --- | --- | --- |
| R1 | Résistance | 0805 | 75kΩ | Feedback boost |
| R2 | Résistance | 0805 | 10kΩ | Feedback boost |
| R3 | Résistance | 0805 | 3.9kΩ  | Rprog TP4056 |
| R4,R5 | Résistance | 0805 | 10kΩ | Diviseur gate  |
| C1 | Condensateur | 0805 | 22µF | Input boost |
| C2 | Condensateur | 0805 | 47µF | Output boost |
| C3,C4 | Condensateur | 0603 | 100nF  | Découplage |
| L1 | Inductance | 4040 | 10µH | Boost, Isat>1A |

### Connectiques

- USB-C femelle pour charge
- Connecteur batterie JST-PH 2 pins
- Pogo pins 4 contacts (socle)

**Coût total estimé** : ~15€ en composants

---

**Prochaines étapes** :

1. Dessiner schéma complet sous KiCad
2. Routage PCB compact (≤ 40x40mm)
3. Génération Gerber et commande PCB
4. Tests de validation électrique

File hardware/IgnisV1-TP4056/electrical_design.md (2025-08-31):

# Calculs Électriques - Projet Ignis

## Calculs Batterie et Consommation

### Batterie EEMB LP402535 (320 mAh)

- Capacité nominale : 320 mAh
- Tension nominale : 3.7V
- Impédance interne : 160 mΩ
- Charge :
  - Courant maximum : 320 mA (1C)
  - Tension maximum : 4.2 V
  - Courant en fin de charge : 6.4 mA
- Décharge :
  - Courant maximum : 2C = 640 mA
  - Tension minimum : 2.75 V
- Température de fonctionnement :
  - En décharge : -20°C à +60°C
  - En charge : 0°C à +45°C

### Consommations par composant

| Composant | Courant (mA) | Notes |
| --- | --- | --- |
| ATtiny212 (actif) | 3-5 | @ 20 MHz, 5V |
| ATtiny212 (sleep) | 0.1-1 | Power-down mode |
| WS2812B (par LED) | 0.3-60 | 0.3mA off, 60mA full white |
| TP4056 (standby)  | 2-3 | Mode veille |
| FP6277 (standby)  | 50-100 µA | Très faible en veille |

### Scénarios d'utilisation

#### Scénario 1 : 6 LEDs, luminosité 50%

```
LEDs : 6 × 30 mA = 180 mA
MCU : 5 mA
Boost : 2 mA (pertes estimation)
TOTAL : ~187 mA

Autonomie : 320 mAh / 187 mA = 1.7 heures
```

#### Scénario 2 : 8 LEDs, luminosité 75%

```
LEDs : 8 × 45 mA = 360 mA
MCU : 5 mA
Boost : 3 mA
TOTAL : ~368 mA

Autonomie : 320 mAh / 368 mA = 0.87 heures
⚠️ Dépasse 1C recommandé, OK pour usage ponctuel
```

#### Scénario 3 : Mode veille (patterns off)

```
MCU (sleep) : 0.5 mA
LEDs (off) : 8 × 0.3 = 2.4 mA
Boost (standby) : 0.1 mA
TOTAL : ~3 mA

Autonomie : 320 mAh / 3 mA = 106 heures (4.4 jours)
```

## Récepteur Qi - BQ51013B

### Caractéristiques générales

- **Type** : Récepteur Qi WPC v1.2 (BPP - Baseline Power Profile)
- **Puissance** : Jusqu'à 5W
- **Tension de sortie** : 5V régulé
- **Courant max** : 1A
- **Fréquence** : 100-250 kHz (bande WPC)
- **Communication** : ASK/FSK avec transmetteur
- **FOD** : Foreign Object Detection intégré

### Bobine réceptrice - IWAS3010AZEB130KF1 (Vishay)

**Spécifications** :

- Dimensions : 30mm × 10mm (forme rectangulaire)
- Inductance : 12.9 µH @ 100 kHz
- Facteur de qualité Q : 11
- Résistance DC : 780 mΩ
- Puissance max : 3.5W
- Courant max : 800 mA
- Compliance Qi : WPC v1.2

### Calcul des condensateurs de résonance

Le BQ51013B nécessite deux condensateurs de résonance :

**C1 (série)** - Condensateur de résonance principale :
$$C_1 = \frac{1}{(2\pi \times f_S)^2 \times L_S^\prime}$$

Avec $L_S^\prime \approx 15\,\mu H$ dans notre cas (à confirmer) et
$f_S = 100\,\text{kHz}$ (donné par la documentation du BQ51013B) :

$$C_1 \approx 168,868\,\text{nF}$$

On peut choisir $C_1 = 150\,\text{nF}$ ou
$C_1 = 150\,\text{nF} + 15\,\text{nF} = 165\,\text{nF}$, à ce stade c'est une
question d'implémentation. Dans une certaine mesure, la version à 2
condensateurs peut offrir une meilleure adaptabilité, surtout que $L_S^\prime$
n'est pas entièrement connue à ce stade. L'erreur en fréquence serait à ce
moment $\leq 2.7\%$.

**C2 (parallèle)** - Condensateur de mise au point :

Avec $L_S = 12.9\,\mu H$ (inductance libre, donné par la datasheet de
l'inductance) et $f_D = 1\,\text{MHz}$ (donné par la datasheet du BQ51013B) :

$$C_2 = \frac{1}{(2\pi \times f_D)^2 \times L_S - \frac{1}{C_1}}$$

soit $C_2 \approx 1,987\,\text{nF} \text{ à } 1,989\,\text{nF}$ selon que l'on
choisisse $C_1 = 165\,\text{nF}$ ou $C_1 = 150\,\text{nF}$, autant dire qu'il
n'y a aucune différence et on peut choisir $C_2 = 2\,\text{nF}$ ou
$C_2 = 1\,\text{nF} + 1\,\text{nF}$.

### Calcul R_ILIM

La limitation de courant du BQ51013B se règle via la résistance $R_{ILIM}$ selon
:

$$
R_{ILIM} = \frac{K_{ILIM}}{I_{MAX}}
$$

où $K_{ILIM}$ est donné par la datasheet ($614\,\Omega\cdot A$), et $I_{MAX}$
est le courant maximal souhaité.

La datasheet précise que le courant de limitation réel est :

$$
I_{ILIM} = 1.2 \times I_{MAX} = \frac{K_{ILIM}}{R_{ILIM}}
$$

$R_{ILIM}$ est la somme de deux résistances :

$$
R_{ILIM} = R_1 + R_{FOD}
$$

avec $R_{FOD}$ par défaut à $196\,\Omega$.

Pour $I_{MAX} \geq 600\,\text{mA}$, $I_{ILIM} = 720\,\text{mA}$

$$
R_{ILIM} = \frac{614}{0.72} \approx 436\,\Omega \implies R_1 = 240\,\Omega
$$

En pratique, avec $R_{FOD} = 196\,\Omega$, on choisit $R_1 = 220\,\Omega$
(valeur standard) :

$$
R_{ILIM} = 220 + 196 = 416\,\Omega \implies I_{ILIM} \approx 754\,\text{mA} \implies I_{MAX} \approx 629\,\text{mA}
$$

### Composants BQ51013B

- C1a (série) : 150 nF, 25V, X7R
- C1b (série) : 15 nF, 25V, X7R
- C2a (parallèle) : 1 nF, 25V, X7R
- C2b (parallèle) : 1 nF, 25V, X7R
- C3 (RECT) : 10 µF + 10µF + 0.1µF, 16V
- C4 (OUT) : 10 µF + 0.1µF, 16V
- C5 (BOOT) : 10 nF, 25V
- C6 (CLAMP) : 470 nF, 25V
- C7 (COMM) : 47 nF, 25V
- R1 (ILIM) : 220 Ω
- Rfod (FOD) : 196 Ω
- Ros (RECT) : 20 kΩ

### Configuration des broches

- **AC1/AC2** : Connexion bobine réceptrice
- **RECT** : Tension rectifiée (~8-10V)
- **OUT** : Sortie régulée 5V
- **AD** : Lié à GND via 1µF (pas de gestion dual-power)
- **EN** : Enable, pullup 10kΩ vers OUT
- **TS/CTRL** : Configuration, voir datasheet

## Chargeur de batterie - TP4056

Le courant de charge se programme via résistance RPROG :
$$I_{CHARGE} = \frac{1000\text{V}}{R_{PROG}}$$

Pour 320 mA (1C optimal) :

$$R_{PROG} = \frac{1100\,\text{V}}{320\,\text{mA}} = 3.4375\,\text{k}\Omega \approx 3.9\,\text{k}\Omega$$

**Composants TP4056** :

- Rprog : 3.9 kΩ (0805, 1%)
- C1 (VBUS) : 100 nF (tant ou céram X7R)
- C2 (BAT) : 10 µF
- LEDs charge : Rouge/Verte avec résistances 1.5 kΩ -> Seront peut-être plutôt
  remplacées par des entrées sur le uC pour utiliser les WS2812B

## Configuration FP6277 Boost

### Réglage tension sortie (5V)

La tension de sortie est définie par le pont diviseur selon :

$$
V_{out} = 0.6\,\text{V} \times \left(1 + \frac{R_1}{R_2}\right)
$$

Pour $V_{out} = 5\,\text{V}$ :

$$
5 = 0.6 \times \left(1 + \frac{R_1}{R_2}\right) \\
\frac{R_1}{R_2} = \frac{5}{0.6} - 1 = 7.33
$$

Si $R_2 = 10\,\text{k}\Omega$ alors
$R_1 = 73.3\,\text{k}\Omega \approx 75\,\text{k}\Omega$

### Calcul inductance optimale

L'inductance optimale pour le FP6277 se calcule avec :

$$
L = \frac{V_{in(max)} \times (V_{out} - V_{in(max)})}{V_{out} \times (\Delta I_L) \times f_{sw}}
$$

Avec :

- $V_{in(max)} = 4.2\,V$ (batterie pleine)
- $V_{out} = 5.0\,V$
- $\Delta I_L = 500\,\text{mA} \times 30\% = 0.15\,A$ (ripple 30% du courant
  moyen)
- $f_{sw} = 1.4\,\text{MHz}$ (fréquence FP6277)

$$
L = \frac{4.2 \times (5.0 - 4.2)}{5.0 \times 0.15 \times 1.4 \times 10^6} = 3.2\,\mu H
$$

**Inductance recommandée** : 3.3 µH (permet de rejoindre le design de référence)

### Protection contre surintensité

La limitation de courant du FP6277 se règle via une résistance entre la broche
OC et la masse :

$$
I_{OCP} = \frac{180\,000}{R_{OC}} + 0.2
$$

Pour programmer $I_{OCP} = 0.64\,\text{A}$ (640 mA, max batterie) :

$$
R_{OC} = \frac{180\,000}{0.44} = 409\,\text{k}\Omega \approx 390\,\text{k}\Omega
$$

**Composants FP6277** :

- L1 : Inductance 3.3 µH, courant sat > 1A
- C1 (Vin) : 22 µF, 16V
- C2 (Vout) : 22 µF, 16V
- C3 (Vout) : 100 µF, 16V
- R1 : 75 kΩ (feedback high)
- R2 : 10 kΩ (feedback low)
- R3 : 390 kΩ (OC)

## Calcul du filtre pour le SW18030

Le SW18030 est un capteur de choc utilisant un ressort enroulé autour d'une tige
métallique. Lors d'un choc ou d'une accélération, le ressort vient brièvement
toucher la tige, générant un contact très court. Pour prolonger ce signal et le
rendre exploitable, on ajoute un circuit RC qui étire la durée de l'impulsion.
Afin d'obtenir un signal carré propre, compatible avec le réveil de l'ATtiny en
mode sommeil, on place ensuite un Bascule de Schmitt non-inverseur à la sortie
du filtre RC.

Lors d'un choc, le SW18030 ferme le contact pendant ~1 ms. Pour obtenir une
impulsion exploitable, la constante de temps du filtre RC doit être bien
inférieure à cette durée.

**Filtre RC (charge rapide) :**

- Résistance série : $R_s$
- Capacité : $C$
- Constante de temps : $\tau = R_s \times C$

Pour ce projet :

- $R_s = 470\,\Omega$
- $C = 22\,\text{nF}$
- $\tau = 470\,\Omega \times 22\,\text{nF} = 10{,}3\,\mu\text{s} \ll 1\,\text{ms}$

Le condensateur se charge quasi-instantanément, permettant au signal d’atteindre
rapidement le seuil haut du Schmitt ($V_T^+$).

**Décharge (étirement du signal) :**

- Résistance de décharge : $R_d$
- Durée d'impulsion :
  $t = R_d \cdot C \cdot \ln\left(\frac{V_{CC}}{V_T^-}\right)$

Pour ce projet :

- On souhaite $t \approx 15\,\text{ms}$
- $R_d = 680\,\text{k}\Omega$ (le calcul donne
  $R_d \approx 667\,\text{k}\Omega$)
- $V_{CC} = 5\,\text{V}$
- $V_T^- = 1.8\,\text{V}$ (donné par la datasheet)
- $t = 680\,\text{k}\Omega \times 22\,\text{nF} \times \ln\left(\frac{5}{1.8}\right) \approx 15.3\,\text{ms}$
  => OK

Ce temps garantit une impulsion suffisamment longue pour réveiller l’ATtiny en
mode sommeil, sans rebonds parasites.

**Composants SW18030** :

- Rs : 470 Ω
- Cs : 22 nF
- R_d : 680 kΩ
- 74LVC1G17 : Bascule de Schmitt avec tampon (non-inverseur).

## Power-Path avec DMP1045U

### Circuit de commutation automatique

Le P-MOSFET DMP1045U permet le basculement automatique entre USB et batterie.

**Principe** :

- Gate relié à USB via diviseur résistif
- Source sur batterie
- Drain vers boost converter
- Quand USB présent : MOSFET OFF, alimentation directe USB
- Quand USB absent : MOSFET ON, alimentation batterie

**Composants** :

- R3, R4 : Diviseur 10kΩ/10kΩ sur gate
- R5 : Pull-up 100kΩ sur gate vers batterie
- C3 : 100nF filtrage gate

## Bilan thermique

### Pertes boost converter

```
Pertes ≈ (Vout - Vin) × Iout / η

Cas critique : Vin = 3.0V, Vout = 5V, Iout = 400mA, η = 85%
Pertes = (5 - 3) × 0.4 / 0.85 = 0.94W
```

**Gestion thermique** :

- Via thermique sous FP6277
- Plan de masse étendu
- Copper pour dissipation

### Échauffement batterie

Résistance interne LiPo ≈ 100-200 mΩ

```
Pertes batterie = I² × Ri = 0.4² × 0.15 = 24mW
ΔT ≈ 24mW / 5mW/°C = 5°C élévation
```

## Protection et sécurité

### Seuils de protection

- **Tension batterie min** : 3.0V (coupure boost)
- **Courant max** : 500mA (limite software)
- **Température max** : 70°C (monitoring si capteur ajouté)
- **FOD Qi** : Détection objets étrangers automatique

## Brainstorming - Historique des choix de design

### Problématique initiale : Chargeur sans fil

**Motivations pour le Qi** :

- Étanchéité du boîtier (pas de port USB)
- Expérience utilisateur premium
- Compatibilité avec chargeurs commerciaux

**Défis identifiés** :

- Modules commerciaux trop chers (>11€)
- Puissance excessive (15W vs besoin 1.5-3W)
- Encombrement des bobines
- Complexité d'intégration PCB

### Choix de l'IC récepteur

**Options évaluées** :

- **BQ51003** : 2.5W, plus simple mais limite de puissance
- **BQ51013B** : 5W, plus de marge, documentation TI excellente
- **P9025AC (Renesas)** : Moins de documentation publique

**Décision** : BQ51013B pour la documentation et la dispo LCSC (JLCPCB)

### Choix de la bobine

**Critères** :

- Compliance Qi WPC v1.2
- Dimensions compatibles (≤35mm)
- Puissance suffisante (3W+)
- Disponibilité distribueurs

**IWAS3010AZEB130KF1 retenue** :

- 30×10mm : compact pour le boîtier flamme
- 3.5W : marge pour pics de consommation
- Q=11 : compromis efficacité/bande passante
- Vishay : marque fiable, stock Mouser/Digikey

### Philosophie power-path

**Deux niveaux identifiés** :

1. **Amont batterie** : Sélection sources (USB/Qi/AC)
   - Non applicable ici (une seule source Qi)
   - AD pin du BQ51013B à GND
2. **Aval batterie** : Système vs batterie
   - Critique pour éviter décharge batterie pendant charge
   - Utilisation du DMP1045U pour la commutation

---

**Dernière mise à jour** : Août 2025  
**Statut validation** : 🔧 Design finalisé - Prototypage requis

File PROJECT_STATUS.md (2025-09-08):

# 🔥 Ignis Project Status

**Last Updated** : September 8, 2025  
**Current Phase** : Hardware Validation ✅ - Firmware Development Phase

## ✅ Completed

### 📚 Project Foundation

- [x] **Workplace Setup**: VS Code, PlatformIO, KiCAD, FreeCAD, Copilot
- [x] **Technical Documentation**: Component datasheets, electrical calculations
- [x] **Mechanical Design**: 3D models, test fixtures, printable STL files
- [x] **Branding Complete**: TheoToys logo system and project identity

### 🔢 Calculations and Design

- [x] **Component Selection**: MCU, LEDs, Qi charger, battery charger, boost converter
- [x] **Electronics Calculations**: Dimensioning of passive components
- [x] **BQ51013B**: Inductive charge
- [x] **BQ24073**: LiPo battery charger with power-path management
- [x] **FP6277**: 3.7V to 5V boost converter
- [x] **SW-18030**: Shock sensor with RC filtering and Schmitt trigger

### 🎨 Artwork and 3D Models

- [x] **3D Modeling**: Enclosure design and prototyping
- [x] **3D Printing Calibration**: Tests and calibration to characterize the PLA filament, determine repetition pattern
- [x] **Missing Components**: Modelled SW18030, battery pack, coil

### 🔌 Hardware

- [x] **IgnisV1**: _Scrubbed_, only schematics, planned to use TP4056 and DMP1045U for battery charging
- [x] **New Battery Management**: Migration TP4056 ⇨ MCP73871 ⇨ BQ24073
- [x] **IgnisV2 Schematics**: Integration of all the components, passives, test points, etc.
- [x] **IgnisV2 PCB Design**: Finalized PCB layout manufacturable by JLCPCB
- [x] **Sourcing**: Sourced all components from LCSC catalog for JLCPCB PCBA
- [x] **Fixes**: Correction of too small vias (IgnisV2.1) and bad WS2812B footprint (IgnisV2.2)

### 🏭 Manufacturing

- [x] **PCB Production**: JLCPCB fabrication
- [x] **PCB Assembly**: JLCPCB assembly service

### 📋 Validation

- [x] **3D Printing tests**: 3D printed some lamp shell without electronics inside for a side project, validated that the design is printable and nice
- [x] **MCU Programming** : ATtiny212 UPDI programming functional with pymcuprog
- [x] **First Light Achievement** : 6x WS2812B LEDs working (380mA max consumption)
- [x] **Power System Validated** : Boost converter (3.7V→5V) working correctly

### 💾 Firmware

- [x] **Hardware Abstraction** : Clean board.h with proper IgnisV2.2 pin mappings
- [x] **Programming Toolchain** : UPDI via pymcuprog working on real hardware
- [x] **Board Testing Framework** : Validation firmware for hardware testing

## 🚧 Next Milestones

### 📋 Validation

- [ ] **Wireless charging system** : Test BQ51013B + IWAS3010 coil integration
- [ ] **Battery integration** : LiPo connection and charge management
- [ ] **Shock sensor integration** : SW-18030 with wake-up interrupts
- [ ] **Indicators**: Inductor, charge, charge complete signals over pull-ups

### 💾 Firmware

- [ ] **Indicators** : Wake on IND_B, CHRG_B, PGOOD_B pins and light pattern for status
- [ ] **User interaction** : Shake-to-wake and charging dock detection
- [ ] **Power management** : Sleep modes and battery monitoring
- [ ] **Flame effect patterns** : Realistic LED and fun animations for flame simulation

### 🎨 Artwork and 3D Models

- [ ] **PCB Support**: Integrate mounting of PCB, coil and battery in the enclosure

### 🏭 Manufacturing

- [ ] **Production**: Print enclosure and mount PCB, coil and battery inside

## 📋 Technical Architecture (IgnisV2.2)

```mermaid
flowchart TD
  QiCharger["BQ51013B<br/>Qi Charger<br/>🔍"] ==> Charger["BQ24073<br/>Battery Charger<br/>🔍"]
  Charger <==> Battery["LiPo Battery<br/>320mAh<br/>🔍"]
  Charger ==> Boost["FP6277 Boost<br/>3.7V → 5V<br/>✅"]
  
  subgraph SYS["System"]
    MCU["ATtiny212 @ 20MHz<br/>✅"]
    ShockSensor["SW-18030<br/>Shock Sensor<br/>🔍"]
    MCU -. "User Interaction" .- ShockSensor
    MCU --> WS2812B["WS2812B<br/>6 LEDs<br/>✅"]
  end

  Boost ==> SYS
  Charger -. "Charge Status" .-> MCU
  QiCharger -. "Coil Status" .-> MCU
```

### 🔧 Key Specifications

- **MCU** : ATtiny212-SSN (UPDI programming working)
- **LEDs** : 6x WS2812B-2020 (validated, 380mA max consumption)
- **Power** : FP6277 boost 3.7V→5V (working with external supply)
- **Charging** : BQ24073 + BQ51013B Qi wireless charging (untested)
- **Battery** : EEMB LP402535 (320mAh, not yet integrated)
- **Sensor** : SW-18030 shock detector (not yet integrated)

## 🔧 Current Development Setup

- **MCU** : ATtiny212 @ 20MHz, Arduino framework
- **Programming** : UPDI via pymcuprog (working on real hardware)
- **LEDs** : 6x WS2812B controlled via tinyNeoPixel library
- **Testing** : Board validation firmware with color cycling patterns
- **Power** : External 3.7V supply for boost converter testing

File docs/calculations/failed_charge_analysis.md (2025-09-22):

# Analysis of failing inductive charging on IgnisV2.2 PCB

## Resonnance Frequency Adjustments: Step 1

Upon receiving the IgnisV2.2 PCB, the inductive charging did not function as
expected. One possible explanation is that the original documentation assumed
the coil inductance would increase to $16\,\mu\text{H}$ when installed
(including PCB, battery, etc.), but this may not be the case. For
troubleshooting, calculations are performed using the datasheet value:
$L_S = L_S' = 12\,\mu\text{H}$. All subsequent capacitance calculations are
based on this adjusted inductance.

### Series Capacitance

The equation:

$$
C_1 = \frac{1}{(2\pi f_S)^2 L_S'}
$$

where:

- $f_S = 100\,\text{kHz} +5/-10\%$
- $L_S' = 12\,\mu\text{H}$

Calculation:

$$
C_1 = \frac{1}{(2\pi \times 100\,000)^2 \times 12 \times 10^{-6}}
$$

Result:

$$
C_1 \approx 211.09\,\text{nF}
$$

### Parallel Capacitance

The equation:

$$
C_2 = \frac{1}{(2\pi f_D)^2 L_S' - 1/C_1}
$$

where:

- $f_D = 1\,\text{MHz} \pm 10\%$
- $L_S = 12\,\mu\text{H}$

Calculation:

$$
C_2 = \frac{1}{(2\pi \times 1\,000\,000)^2 \times 12 \times 10^{-6} - \frac{1}{200 \times 10^{-9}}}
$$

Result:

$$
C_2 \approx 2.13\,\text{nF}
$$

### COMM1/COMM2 Capacitors

It seems that some designs are successful with $22\,\text{nF}$ capacitors on
COMM1 and COMM2 rather than $47\,\text{nF}$.

### New Capacitor Values Summary

| Capacitor | Original Value | New Value | Adaption Action |
| --- | --- | --- | --- |
| C_1 | $165\,\text{nF}$ | $211\,\text{nF}$ | Solder 47nF capacitor on placeholder => $165 + 47 = 212\,\text{nF}$ |
| C_2 | $2\,\text{nF}$ | $2\,\text{nF}$ | _No changes required_ |

### Results

These modifications did not resolve the issue. Oscilloscope analysis shows that
coil voltage actually decreased. The `RECT` capacitor voltage remains around 3V,
while at least 5V (ideally 7V) is expected. It’s possible that soldering the
capacitor affected resonance, as a THT ceramic capacitor was used instead of an
0805 SMD. The coil frequency measured is 140kHz, not the expected 100kHz, and no
modulation occurs (COMM capacitors are not yet involved, so changing them is
unnecessary at this stage). The problem appears to be earlier in the circuit.

## Resonnance Frequency Adjustments: Step 2

The coil frequency is 140kHz instead of the expected 100kHz. To adjust, the
series capacitor $C_1$ needs to be recalculated for the new frequency.

$$
C_1 = \frac{1}{(2\pi \times 140\,\text{kHz})^2 \times 12\,\mu\text{H}} \approx 107\,\text{nF}
$$

| Adaption Action | New Value of $C_1$ | Result |
| --- | --- | --- |
| Remove original 15nF capacitor | $165 - 15 = 150\,\text{nF}$ | Not much better |
| Remove both 150nf and 15nF capacitors and add 87nF capacitor on placeholder | $87\,\text{nF}$ | Vpp on coil is higher (5V) but still not sufficient to start charging. It seems that communication is tried but fails. |
| Try more values on the 0402 footprint with 87nF still on the placeholder | _Several values_ | Best result with a total of ~130nF with highest Vpp on coil, but still not sufficient to start charging. |

## Modification of Transmitter

To better understand the IKEA Livboj transmitter, the unit was disassembled and
tested with the receiver coil placed directly on top of the transmitter coil.
When powered, charging was initiated only if the coils were precisely aligned.
Notably, varying the receiver-side capacitance (using either 130 nF or 212 nF)
did not affect charging performance. This suggests that the receiver circuit
design is fundamentally sound, but the coupling between the transmitter and
receiver coils is insufficient.

Further research indicates that geometry and size should match between the
receiver and transmitter coil. If this is true, the Vishay receiver coil,
constrained to 30 × 10 mm and featuring a rounded rectangular shape, could
feature an inefficient coupling with the IKEA Livboj’s 43 mm diameter circular
transmitter coil.

**Solution to try:** larger coil, possibly round.

<div align="center">

Test of inductive charge without casing (https://youtu.be/-Y1U7MM0c8Y)

</div>

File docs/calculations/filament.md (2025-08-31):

# Calculs Filament iSANMATE Mat PLA+ Gradient Sunset pour Lampe Ignis

## Objectif

Documenter les mesures et calculs liés à l'utilisation du filament iSANMATE Mat
PLA+ Gradient Sunset pour la fabrication de la lampe Ignis, notamment la
longueur de filament nécessaire pour obtenir un motif de gradient orange/brun à
jaune.

## Calibration

- **Type de filament** : PLA+ (couleurs : orange/brun à jaune, gradient sunset)
- **Marque** : iSANMATE
- **Finition** : Matte
- **Densité** : 1.24 g/cm³
- **Diamètre** : 1.75 mm

### Temperature

- **Méthode** : Temperature Tower
- **Résultat** : 190°C optimum (test "temperature tower" montre de très bons
  résultats entre 210°C et 180°C, choix difficile entre 200°C et 180°C)

### Débit

- **Méthode** : Flowrate YOLO
- **Résultat** : +0.02 (à rajouter au rapport de débit de base de 1.00)
  difficile d'identifier de sérieuses différences entre +0.00 et +0.03

### Débit (perfectionnist)

- **Méthode** : Flowrate YOLO (perfectionnist)
- **Résultat 1** : Surface difficile à interpréter, filament très stable, choix
  final : -0.04 (meilleure surface observée)
- **Remarque** : Correction de débit passant de 1.00 à 1.02 puis à 0.98, à
  l'inverse du test précédent.

### Débit (perfectionnist) 2

- **Méthode** : Flowrate YOLO (perfectionnist)
- **Résultat 2** : Plus facile à voir avec la spirale d'Archimède. Sélectionné
  -0.010, pour un total de 0.970.

### Pressure Advance

- **Méthode** : Tower
- **Paramètres**:
  - Type d'extrudeur: Bowden
  - Début : 0
  - Fin : 1
  - Pas : 0.02
- **Résultat** : Pas tellement de différence, prise à 1cm => 0.2

### Retraction

- **Méthode** : Dual Tower
- **Paramètres**:
  - Début : 2
  - Fin : 6
  - Pas : 0.1
- **Résultat** : Non concluant (mais excellente qualité)

### Retraction 2

- **Méthode** : Dual Tower
- **Paramètres**:
  - Début : 0
  - Fin : 3
  - Pas : 0.1
- **Résultat** : 20mm mesuré => 2mm de rétractation

## Mesures à effectuer

1. **Longueur totale du filament inséré avant impression**
2. **Longueur de filament consommée jusqu'à la première répétition du motif**
3. **Poids du filament utilisé (optionnel, pour vérification croisée)**

## Données d'utilisation du filament

- **Temperature Tower** :
  - Longueur de filament utilisée : 4.71m
  - Poids du filament utilisé : 14.04g
  - Couleur: 🟧 (apparemment le plus foncé, à vérifier)
- **Flowrate YOLO** :
  - Longueur de filament utilisée : 5.00m
  - Poids de filament utilisé : 14.91g
- **Flowrate YOLO (perfectionnist) 1** :
  - Longueur de filament utilisée : 7.30m
  - Poids de filament utilisé : 21.76g
- **Flowrate YOLO (perfectionnist) 2** :
  - Longueur de filament utilisée : 7.01m
  - Poids de filament utilisé : 20.91g
  - **Note** : La couleur jaune la plus claire a été atteinte durant ce test, à
    environ 3/4 de l'impression.
  - Couleur: 🟨 (le plus clair)
  - Pré-calcul :
    $1/2\,\text{motif} = 4.71,\text{m} + 5.00,\text{m} + 7.30,\text{m} + 7.01,\text{m} \times 75\,\% = 22,26\,\text{m}$
    soit $\text{motif} \approx 45\,\text{m}$
- **Pressure Advance** :
  - Longueur de filament utilisée : 3.80m
  - Poids de filament utilisé : 11.32g
- **Retraction**
  - Longueur de filament utilisée : 0.56m
  - Poids de filament utilisé : 1.66g
- **Retraction 2**
  - Longueur de filament utilisée : 0.46m
  - Poids de filament utilisé : 1.36g
- **Octopus v6**
  - Longueur de filament utilisée : 11.96m
  - Poids de filament utilisé : 35.66g
- **Flamme 4 x2**
  - Longueur de filament utilisée : 24.33m
  - Poids de filament utilisé : 72.57g
  - **Note** : Durant cette impression, la couleur la plus rouge a été atteinte,
    mais pas de retour au jaune. Le calcul prédictif n'était pas bon. Il est
    possible que la distance du rouge au jaune puis du jaune au rouge ne soit
    pas identique.
  - Couleur: 🟧
  - Distance totale : 65.13m
- **Cylindre Test**
  - Longueur de filament utilisée : 1.01m
  - Poids de filament utilisé : 3.02g
  - **Note** : Il semble que le cylindre ait la même couleur que l'item 2/7 de
    la Temperature Tower. On pourrait donc calculer la distance du reste: 5/7 de
    la Temperature Tower.
  - Pré-calcul :
    $\left(\frac{4}{7} \times 4.71\,\text{m}\right) + 5\,\text{m} + 7.30\,\text{m} + 7.01\,\text{m} + 3.80\,\text{m} + 0.56\,\text{m} + 0.46\,\text{m} + 11.96\,\text{m} + 24.33\,\text{m} + 1.01\,\text{m} = 64.121\,\text{m}$
  - Hypothèse : Le motif se répète tous les $65\,\text{m}$
  - Note : Quantité de filament utilisée jusqu'ici = 197.21g
- **Flamme 4 x4**
  - Longueur de filament utilisée : 48.79m
  - Poids de filament utilisé : 145.51g

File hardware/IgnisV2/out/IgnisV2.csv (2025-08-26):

RéférenceValeurEmpreinteDescriptionQtéDesignatorLCSCMFMFNTemperature CoefficientVoltage Rating
C1150nCapacitor_SMD:C_0402_1005MetricUnpolarized capacitor1CapacitorC5448879CCTCTCC0402X7R154K250ATX7R25V
C215nCapacitor_SMD:C_0402_1005MetricUnpolarized capacitor1CapacitorC285020FH (Guangdong Fenghua Advanced Tech)0402B153K250NTX7R25V
C31nCapacitor_SMD:C_0402_1005MetricUnpolarized capacitor1CapacitorC541372YAGEOCC0402KRX7R8BB10225V
C41nCapacitor_SMD:C_0402_1005MetricUnpolarized capacitor1CapacitorC541372YAGEOCC0402KRX7R8BB10225V
C50Capacitor_SMD:C_0805_2012Metric_Pad1.18x1.45mm_HandSolderUnpolarized capacitor1Capacitor25V
C610nCapacitor_SMD:C_0402_1005MetricUnpolarized capacitor1CapacitorC284987FH (Guangdong Fenghua Advanced Tech)0402B103K250NT25V
C710nCapacitor_SMD:C_0402_1005MetricUnpolarized capacitor1CapacitorC284987FH (Guangdong Fenghua Advanced Tech)0402B103K250NT25V
C8470nCapacitor_SMD:C_0603_1608MetricUnpolarized capacitor1CapacitorC7503496HRECGA0603X7R474K250JT25V
C9470nCapacitor_SMD:C_0603_1608MetricUnpolarized capacitor1CapacitorC7503496HRECGA0603X7R474K250JT25V
C1047nCapacitor_SMD:C_0402_1005MetricUnpolarized capacitor1CapacitorC5142571CCTCTCC0402X7R473M250AT25V
C1147nCapacitor_SMD:C_0402_1005MetricUnpolarized capacitor1CapacitorC5142571CCTCTCC0402X7R473M250AT25V
C1210uCapacitor_SMD:C_0402_1005MetricUnpolarized capacitor1CapacitorC7393849CCTCTCC0402X5R104Z160AT16V
C1310uCapacitor_SMD:C_0402_1005MetricUnpolarized capacitor1CapacitorC7393849CCTCTCC0402X5R104Z160AT16V
C14100nCapacitor_SMD:C_0402_1005MetricUnpolarized capacitor1CapacitorC328914PSA(Prosperity Dielectrics)FN15X104K160PNG16V
C1510uCapacitor_SMD:C_0402_1005MetricUnpolarized capacitor1CapacitorC7393849CCTCTCC0402X5R104Z160AT16V
C16100nCapacitor_SMD:C_0402_1005MetricUnpolarized capacitor1CapacitorC328914PSA(Prosperity Dielectrics)FN15X104K160PNG16V
C171uCapacitor_SMD:C_0603_1608MetricUnpolarized capacitor1CapacitorC76617TDKC1608X7R1C105KT000NX7R16V
C184.7uCapacitor_SMD:C_0603_1608MetricUnpolarized capacitor1CapacitorC22399629HRECGA0603X7R475K160JTX7R16V
C194.7uCapacitor_SMD:C_0603_1608MetricUnpolarized capacitor1CapacitorC22399629HRECGA0603X7R475K160JTX7R16V
C2022uCapacitor_SMD:C_1206_3216MetricUnpolarized capacitor1CapacitorC6119995HRECGA1206X7R226K160NTX7R16V
C2122uCapacitor_SMD:C_1206_3216MetricUnpolarized capacitor1CapacitorC6119995HRECGA1206X7R226K160NTX7R16V
C22100uCapacitor_SMD:CP_Elec_5x5.4Polarized capacitor1CapacitorC7461241126RV011016V
C23470uCapacitor_SMD:CP_Elec_6.3x7.7Polarized capacitor1CapacitorC5246516HV1A477M0607PZ10V
C24100nCapacitor_SMD:C_0402_1005MetricUnpolarized capacitor1CapacitorC328914PSA(Prosperity Dielectrics)FN15X104K160PNG
C25100nCapacitor_SMD:C_0402_1005MetricUnpolarized capacitor1CapacitorC328914PSA(Prosperity Dielectrics)FN15X104K160PNG
C26100nCapacitor_SMD:C_0402_1005MetricUnpolarized capacitor1CapacitorC328914PSA(Prosperity Dielectrics)FN15X104K160PNG
C27100nCapacitor_SMD:C_0402_1005MetricUnpolarized capacitor1CapacitorC328914PSA(Prosperity Dielectrics)FN15X104K160PNG
C28100nCapacitor_SMD:C_0402_1005MetricUnpolarized capacitor1CapacitorC328914PSA(Prosperity Dielectrics)FN15X104K160PNG
C29100nCapacitor_SMD:C_0402_1005MetricUnpolarized capacitor1CapacitorC328914PSA(Prosperity Dielectrics)FN15X104K160PNG
C3022nCapacitor_SMD:C_0402_1005MetricUnpolarized capacitor1CapacitorC6266887CCTCTCC0402X7R223M500AT
D2WS2812BIgnis:LED_WS2812B2020RGB LED with integrated controller1WS2812B-2020C965555WorldsemiWS2812B-2020
D3WS2812BIgnis:LED_WS2812B2020RGB LED with integrated controller1WS2812B-2020C965555WorldsemiWS2812B-2020
D4WS2812BIgnis:LED_WS2812B2020RGB LED with integrated controller1WS2812B-2020C965555WorldsemiWS2812B-2020
D5WS2812BIgnis:LED_WS2812B2020RGB LED with integrated controller1WS2812B-2020C965555WorldsemiWS2812B-2020
D6WS2812BIgnis:LED_WS2812B2020RGB LED with integrated controller1WS2812B-2020C965555WorldsemiWS2812B-2020
D7WS2812BIgnis:LED_WS2812B2020RGB LED with integrated controller1WS2812B-2020C965555WorldsemiWS2812B-2020
L13.3uInductor_SMD:L_1008_2520MetricInductor1InductorC2049754TDKMLP2520S3R3MT0S1
R1220Resistor_SMD:R_0402_1005MetricResistor1ResistorC25091UNI-ROYAL(Uniroyal Elec)0402WGF2200TCE
R2220Resistor_SMD:R_0805_2012MetricResistor1ResistorC17557UNI-ROYAL(Uniroyal Elec)0805W8F2200T5E
R310kResistor_SMD:R_0402_1005MetricResistor1ResistorC25531UNI-ROYAL(Uniroyal Elec)0402WGJ0103TCE
R420kResistor_SMD:R_0402_1005MetricResistor1ResistorC25545UNI-ROYAL(Uniroyal Elec)0402WGJ0203TCE
R5196Resistor_SMD:R_0805_2012MetricResistor1ResistorC407413UNI-ROYAL(Uniroyal Elec)0805W8F1960T5E
R62.4kResistor_SMD:R_0402_1005MetricResistor1ResistorC25882UNI-ROYAL(Uniroyal Elec)0402WGF2401TCE
R710kResistor_SMD:R_0402_1005MetricResistor1ResistorC25531UNI-ROYAL(Uniroyal Elec)0402WGJ0103TCE
R8220Resistor_SMD:R_0402_1005MetricResistor1ResistorC25091UNI-ROYAL(Uniroyal Elec)0402WGF2200TCE
R9220Resistor_SMD:R_0402_1005MetricResistor1ResistorC25091UNI-ROYAL(Uniroyal Elec)0402WGF2200TCE
R1024kResistor_SMD:R_0402_1005MetricResistor1ResistorC25549UNI-ROYAL(Uniroyal Elec)0402WGJ0243TCE
R112.7kResistor_SMD:R_0402_1005MetricResistor1ResistorC25885UNI-ROYAL(Uniroyal Elec)0402WGF2701TCE
R12390kResistor_SMD:R_0402_1005MetricResistor1ResistorC25557UNI-ROYAL(Uniroyal Elec)0402WGJ0394TCE
R1375kResistor_SMD:R_0402_1005MetricResistor1ResistorC25570UNI-ROYAL(Uniroyal Elec)0402WGJ0753TCE
R1410kResistor_SMD:R_0402_1005MetricResistor1ResistorC25531UNI-ROYAL(Uniroyal Elec)0402WGJ0103TCE
R16330Resistor_SMD:R_0402_1005MetricResistor1ResistorC12246UNI-ROYAL(Uniroyal Elec)0402WGJ0331TCE
R17470Resistor_SMD:R_0402_1005MetricResistor1ResistorC25167UNI-ROYAL(Uniroyal Elec)0402WGJ0471TCE
R181MResistor_SMD:R_0402_1005MetricResistor1ResistorC26087UNI-ROYAL(Uniroyal Elec)0402WGJ0105TCE
R1910kResistor_SMD:R_0402_1005MetricResistor1ResistorC25531UNI-ROYAL(Uniroyal Elec)0402WGJ0103TCE
R2010kResistor_SMD:R_0402_1005MetricResistor1ResistorC25531UNI-ROYAL(Uniroyal Elec)0402WGJ0103TCE
R2110kResistor_SMD:R_0402_1005MetricResistor1ResistorC25531UNI-ROYAL(Uniroyal Elec)0402WGJ0103TCE
U1BQ51013BRHLTIgnis:BQ51013BRHLTQ51013B Highly Integrated Wireless Receiver Qi - Power Management1BQ51013BRHLTC2650154Texas InstrumentsBQ51013BRHLT
U2BQ24073RGTRIgnis:IC_BQ24073RGTRBQ2407x Standalone 1-Cell 1.5-A Linear Battery Chargers with Power Path1BQ24073RGTRC15220Texas InstrumentsBQ24073RGTR
U3FP6277XR-G1Ignis:SOIC127P599X175-9N500kHz 7A High Efficiency Synchronous PWM Boost Converter1FP6277XR-G1C88312Feeling TechnologyFP6277XR-G1
U474LVC1G17Ignis:IC_74LVC1G17GW_125Single Schmitt Buffer Gate, Low-Voltage CMOS174LVC1G17GWC426705Nexperia74LVC1G17GW,125
U5ATtiny212-SSPackage_SO:SOIC-8_3.9x4.9mm_P1.27mm20MHz, 2kB Flash, 128B SRAM, 64B EEPROM, SOIC-81ATTINY212-SSNC615533Microchip TechATTINY212-SSN

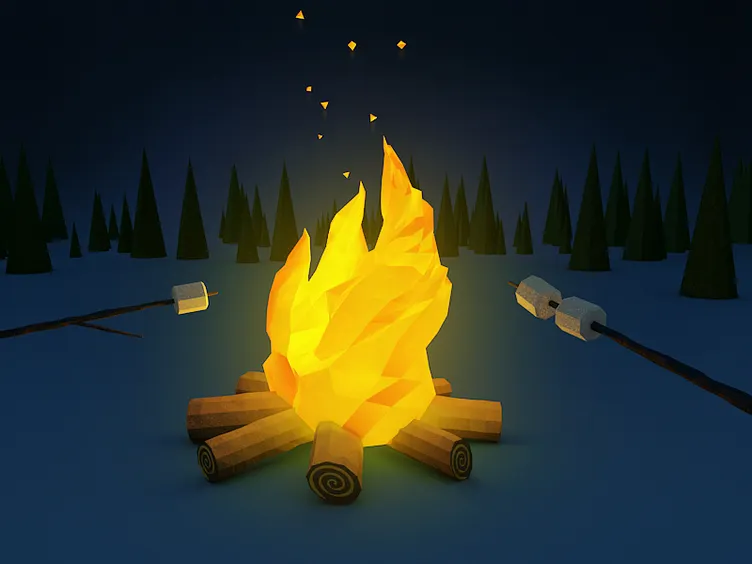
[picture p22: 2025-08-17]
mechanical/art/Inspirations/lowpolycampfire.webp

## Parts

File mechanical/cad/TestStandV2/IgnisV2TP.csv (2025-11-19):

Reference | Value | Footprint | Populate | Color | Connector | Position
TP1 | COIL_A | TestPoint:TestPoint_Pad_D1.0mm | PogoPin:P75B1 | 🟥 Red | 1C2 | 1
TP2 | COIL_B | TestPoint:TestPoint_Pad_D1.0mm | PogoPin:P75B1 | 🟦 Blue | 1C2 | 2
TP6 | GND | TestPoint:TestPoint_Pad_D1.0mm | PogoPin:P75B1 | ⬛ Black | 2C4 | 1
TP3 | VBUS | TestPoint:TestPoint_Pad_D1.0mm | PogoPin:P75B1 | 🟨 Yellow | 2C4 | 2
TP5 | VBAT | TestPoint:TestPoint_Pad_D1.0mm | PogoPin:P75B1 | ⬜ White | 2C4 | 3
TP7 | VSYS | TestPoint:TestPoint_Pad_D1.0mm | PogoPin:P75B1 | 🟥 Red | 2C4 | 4
TP12 | LED_DIN | TestPoint:TestPoint_Pad_D1.0mm | PogoPin:P75B1 | ⬛ Black | 3C3 | 1
TP13 | SSW_RAW | TestPoint:TestPoint_Pad_D1.0mm | PogoPin:P75B1 | 🟩 Green | 3C3 | 2
TP14 | SSW | TestPoint:TestPoint_Pad_D1.0mm | PogoPin:P75B1 | ⬜ White | 3C3 | 3
TP4 | ~{IND} | TestPoint:TestPoint_Pad_D1.0mm | PogoPin:P75B1 | 🟦 Blue | 4C3 | 1
TP8 | ~{CHRG} | TestPoint:TestPoint_Pad_D1.0mm | PogoPin:P75B1 | 🟩 Green | 4C3 | 2
TP9 | ~{PGOOD} | TestPoint:TestPoint_Pad_D1.0mm | PogoPin:P75B1 | 🟨 Yellow | 4C3 | 3
J4 | UPDI | TestPoint:TestPoint_THTPad_D1.5mm_Drill0.7mm | PogoPin:P75E2 | 🟩 Green | 5C3 | 1
J6 | GND | TestPoint:TestPoint_THTPad_D1.5mm_Drill0.7mm | PogoPin:P75E2 | ⬛ Black | 5C3 | 2
J5 | VSYS | TestPoint:TestPoint_THTPad_D1.5mm_Drill0.7mm | PogoPin:P75E2 | 🟥 Red | 5C3 | 3
J1 | COIL_A | TestPoint:TestPoint_THTPad_D1.5mm_Drill0.7mm | None
J2 | COIL_B | TestPoint:TestPoint_THTPad_D1.5mm_Drill0.7mm | None

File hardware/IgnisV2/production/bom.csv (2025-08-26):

Designator | Footprint | Quantity | Value | LCSC Part #
C1 | 0402 | 1 | 150n | C5448879
C10, C11 | 0402 | 2 | 47n | C5142571
C12, C13, C15 | 0402 | 3 | 10u | C7393849
C14, C16, C24, C25, C26, C27, C28, C29 | 0402 | 8 | 100n | C328914
C17 | 0603 | 1 | 1u | C76617
C18, C19 | 0603 | 2 | 4.7u | C22399629
C2 | 0402 | 1 | 15n | C285020
C20, C21 | 1206 | 2 | 22u | C6119995
C22 | CP_Elec_5x5.4 | 1 | 100u | C7461241
C23 | CP_Elec_6.3x7.7 | 1 | 470u | C5246516
C3, C4 | 0402 | 2 | 1n | C541372
C30 | 0402 | 1 | 22n | C6266887
C5 | 0805 | 1 | 0
C6, C7 | 0402 | 2 | 10n | C284987
C8, C9 | 0603 | 2 | 470n | C7503496
D2, D3, D4, D5, D6, D7 | LED_WS2812B2020 | 6 | WS2812B | C965555
L1 | 1008 | 1 | 3.3u | C2049754
R1, R8, R9 | 0402 | 3 | 220 | C25091
R10 | 0402 | 1 | 24k | C25549
R11 | 0402 | 1 | 2.7k | C25885
R12 | 0402 | 1 | 390k | C25557
R13 | 0402 | 1 | 75k | C25570
R14, R19, R20, R21, R3, R7 | 0402 | 6 | 10k | C25531
R16 | 0402 | 1 | 330 | C12246
R17 | 0402 | 1 | 470 | C25167
R18 | 0402 | 1 | 1M | C26087
R2 | 0805 | 1 | 220 | C17557
R4 | 0402 | 1 | 20k | C25545
R5 | 0805 | 1 | 196 | C407413
R6 | 0402 | 1 | 2.4k | C25882
U1 | BQ51013BRHLT | 1 | BQ51013BRHLT | C2650154
U2 | IC_BQ24073RGTR | 1 | BQ24073RGTR | C15220
U3 | SOIC127P599X175-9N | 1 | FP6277XR-G1 | C88312
U4 | IC_74LVC1G17GW_125 | 1 | 74LVC1G17 | C426705
U5 | SOIC-8_3.9x4.9mm_P1.27mm | 1 | ATtiny212-SS | C615533

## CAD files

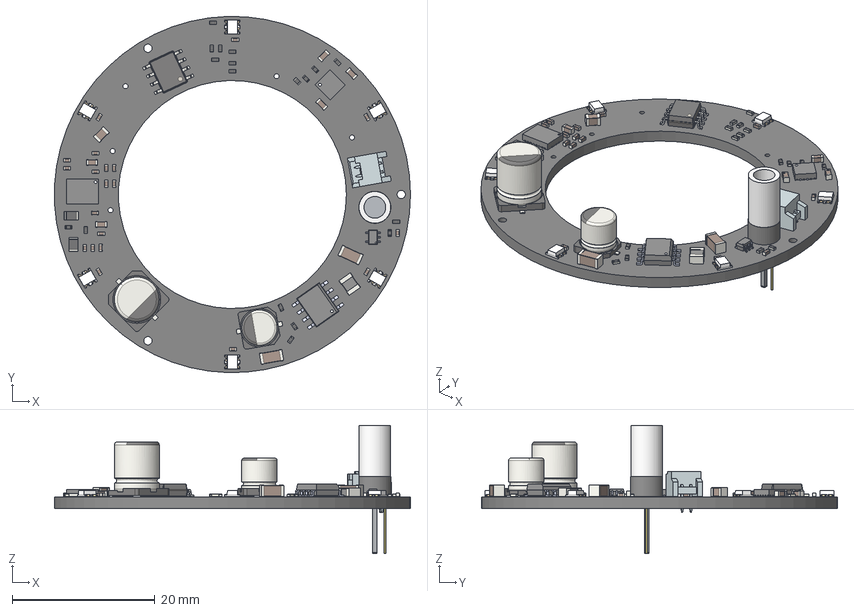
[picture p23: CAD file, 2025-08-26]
hardware/IgnisV2/out/IgnisV2.step
50.0 x 50.0 x 18.0 mm
kicad_embedded_C5BDA16027A1B475F3AD32E60BB433C9
kicad_embedded_6F80DB4FE83919FEBE120546BF9211BB
R_0402_1005Metric x 18
C_0402_1005Metric x 20
kicad_embedded_3DF7FEB12B62EBF7ED4E8B8A585F0BB0 x 6
C_1206_3216Metric x 2
C_0603_1608Metric x 5
CP_Elec_5x5.4
R_0805_2012Metric x 2
C_0805_2012Metric
SOIC-8_3.9x4.9mm_P1.27mm
L_1008_2520Metric
kicad_embedded_0680C8B83FBA55E80A733352AE275C2E
CP_Elec_6.3x7.7
kicad_embedded_8216DF7AE056EBAD5229E926A603A1A5
kicad_embedded_095F239EC677C2CCD90D417FCAFE1F93
IgnisV2_PCB

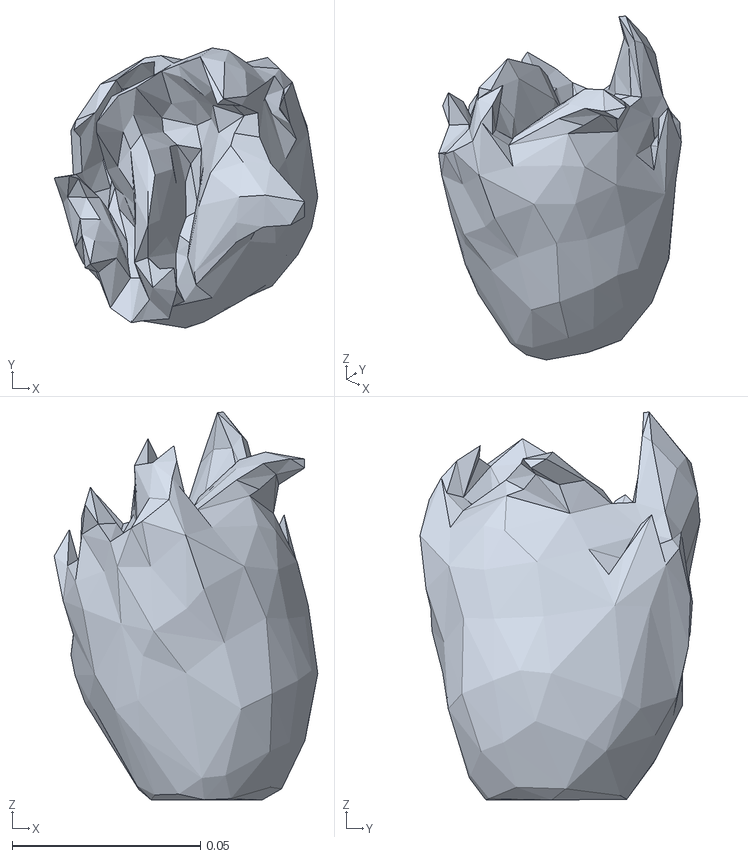
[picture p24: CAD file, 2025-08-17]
mechanical/art/Flamme1/Flamme1_lowpoly.stl
0.07 x 0.0743 x 0.103

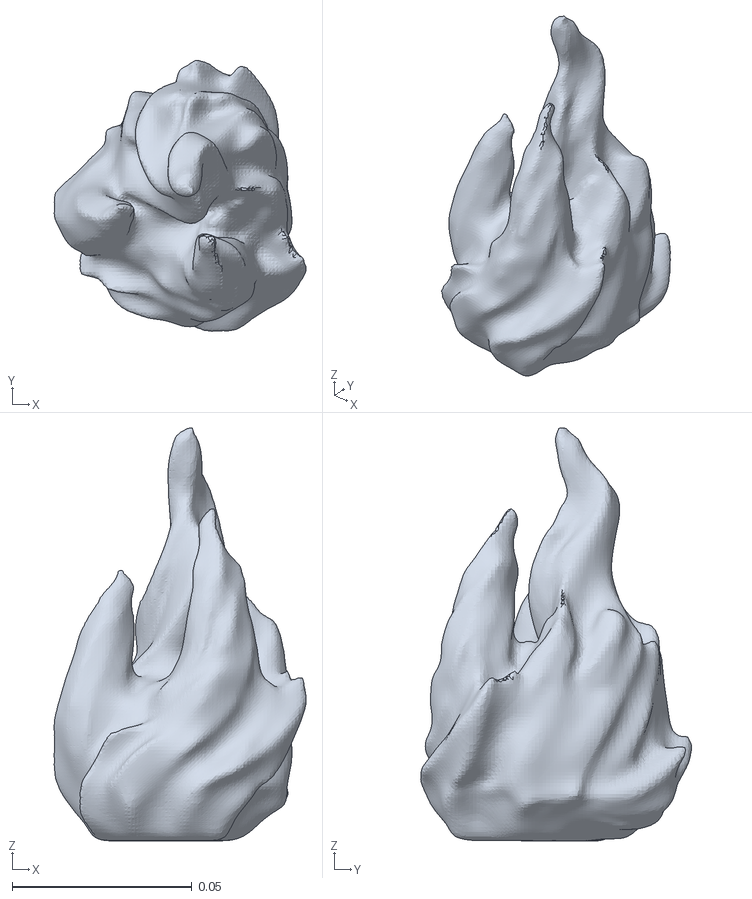
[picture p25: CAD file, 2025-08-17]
mechanical/art/Flamme3/Flamme3_4.stl
0.07 x 0.0752 x 0.115

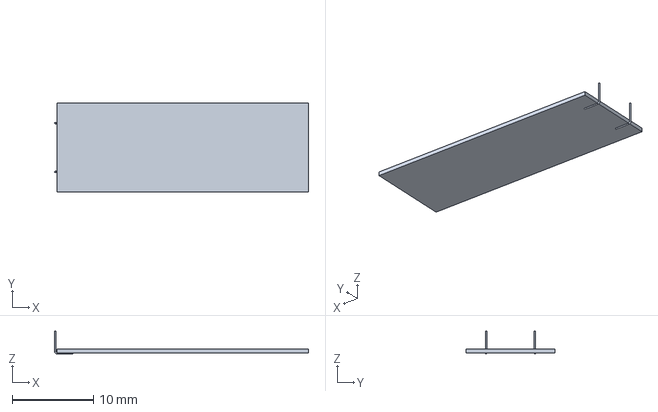
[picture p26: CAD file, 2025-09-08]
mechanical/cad/Misc/Coil.FCStd
31.3 x 11.0 x 2.80 mm

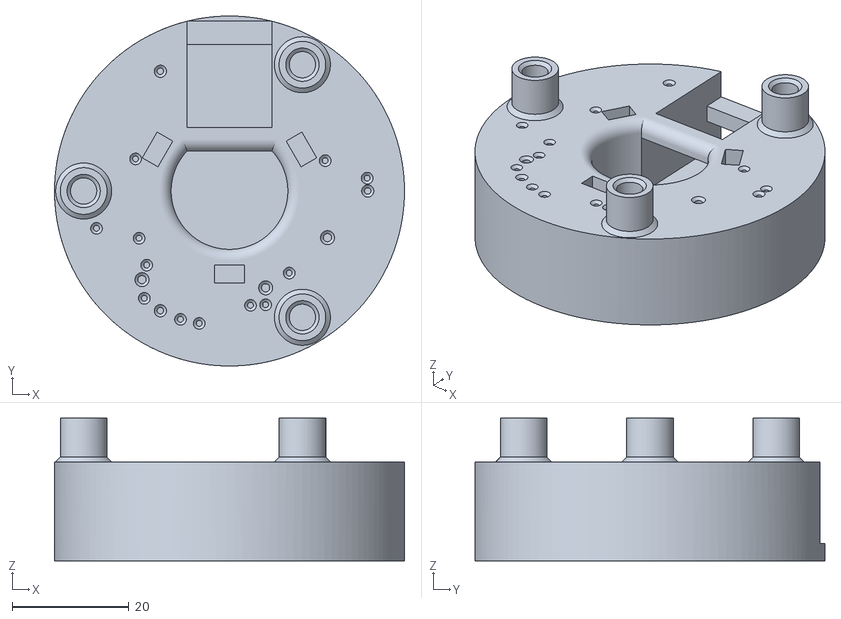
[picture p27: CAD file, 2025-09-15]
mechanical/cad/TestStandV2/TestStandV2-Base.stl
60.0 x 60.0 x 24.5

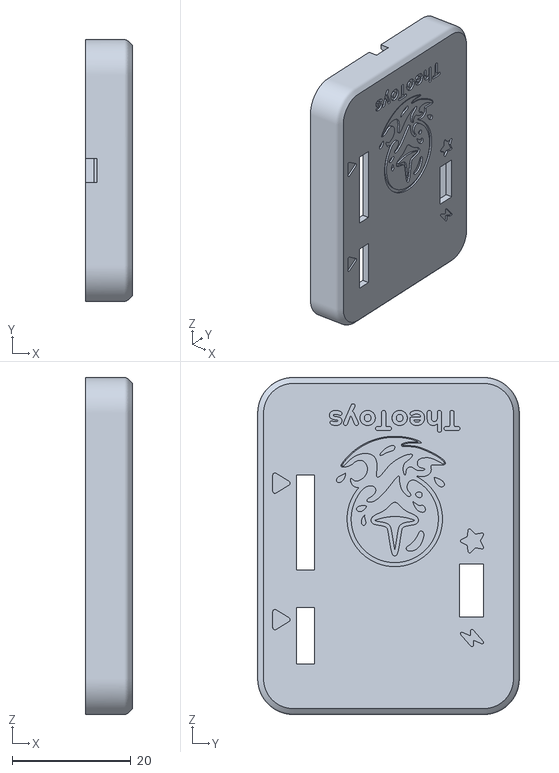
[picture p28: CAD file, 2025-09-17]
mechanical/cad/UPDIFlasherBox/UPDIFlasherBox-Top.stl
8.00 x 44.1 x 56.8

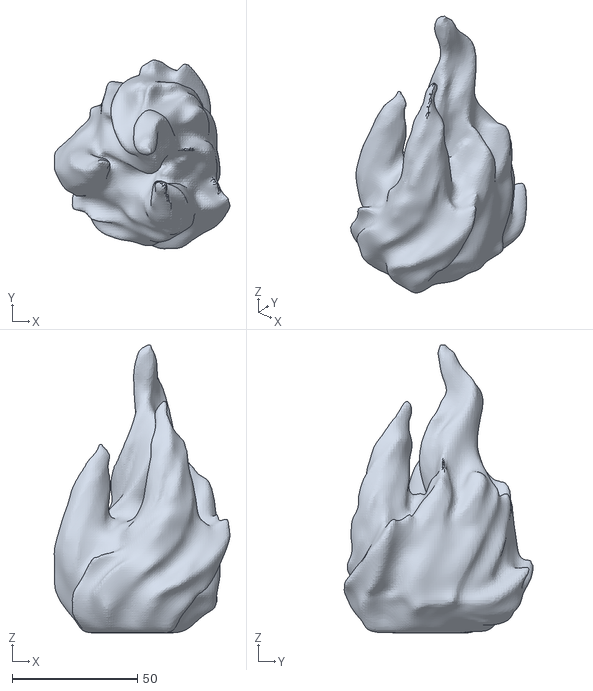
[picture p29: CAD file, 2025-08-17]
mechanical/stl/Flamme3.stl
70.0 x 75.2 x 114.8

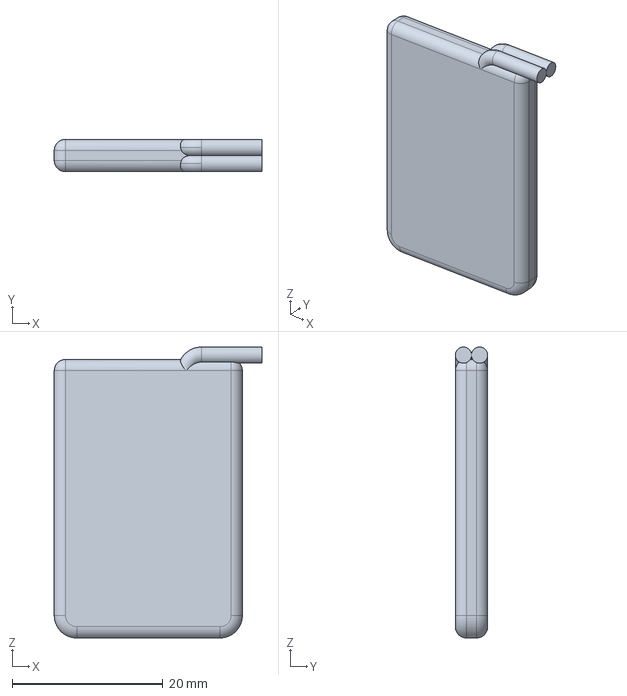
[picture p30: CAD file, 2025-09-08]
mechanical/cad/Misc/BatteryPack.FCStd
27.6 x 4.30 x 38.7 mm

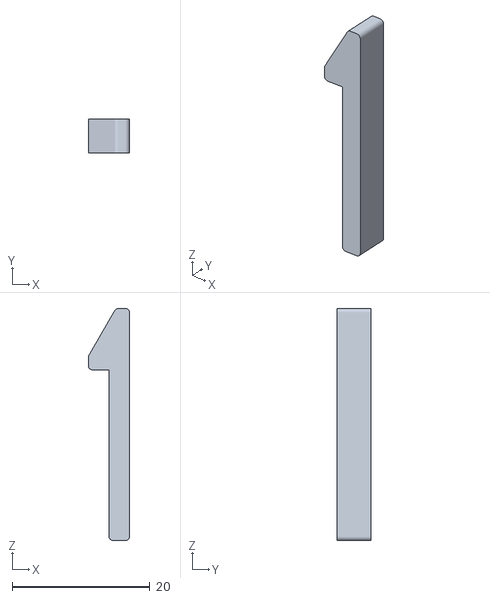
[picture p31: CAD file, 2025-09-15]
mechanical/cad/TestStandV2/TestStandV2-Hook.stl
6.00 x 5.00 x 33.7

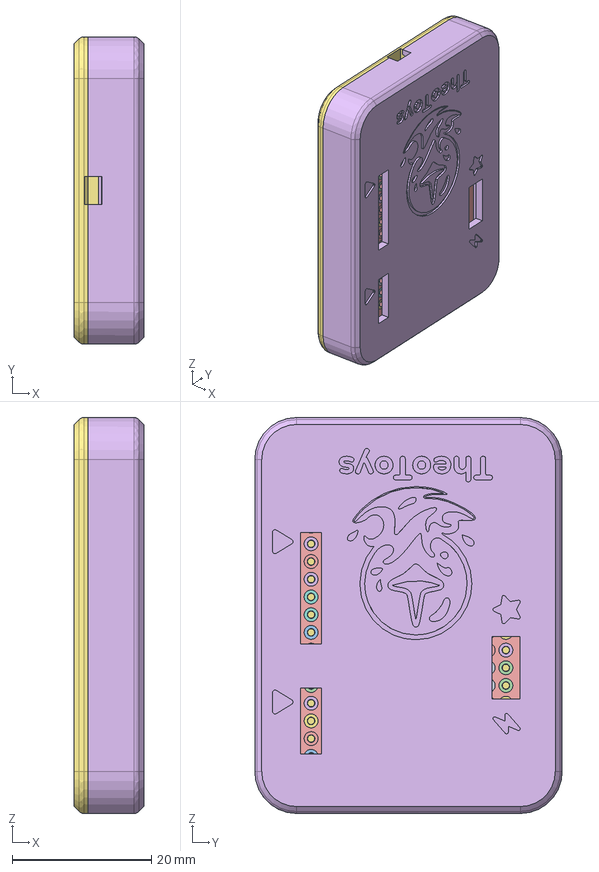
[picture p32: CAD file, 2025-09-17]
mechanical/cad/UPDIFlasherBox/UPDIFlasherBox.FCStd
10.0 x 44.1 x 56.8 mm
text
text001
text002
text003
text004
text005
text006
text007
text008
text009
text010
text011
text012
text013
text014
text015
text016
text017
text018
text019
contacts
contacts001
contacts002
contacts003
contacts004
contacts005
contacts006
contacts007
contacts008
contacts009
contacts010
contacts011
contacts012
contacts013
contacts014
contacts015
contacts016
contacts017
contacts018
contacts019
contacts020
contacts021
contacts022
contacts023
contacts024
contacts025
contacts026
contacts027
contacts028
contacts029
contacts030
contacts031
contacts032
contacts033
contacts034
contacts035
contacts036
contacts037
contacts038
contacts039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

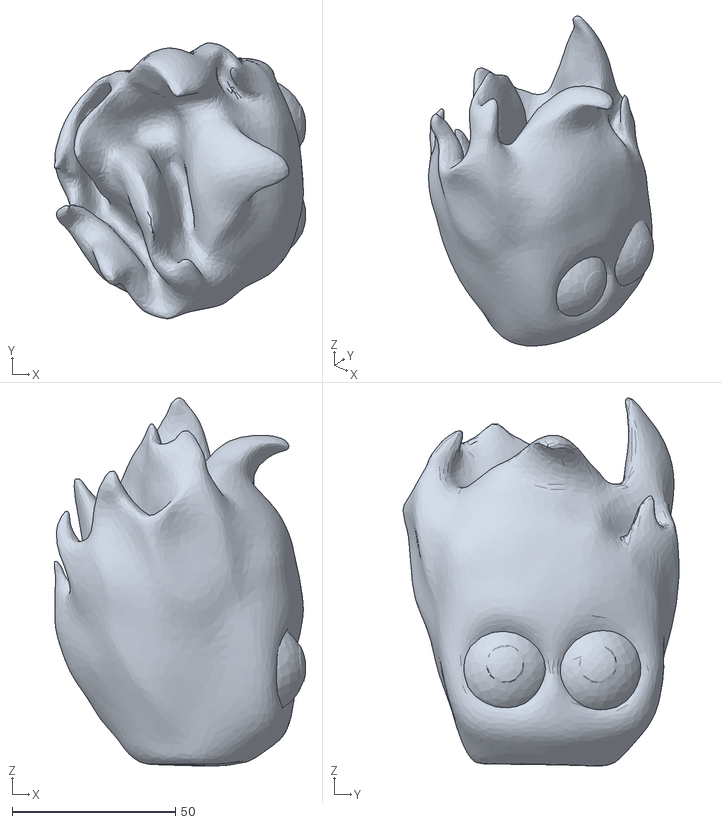
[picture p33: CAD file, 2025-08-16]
mechanical/stl/Flamme2.stl
77.0 x 84.5 x 112.7

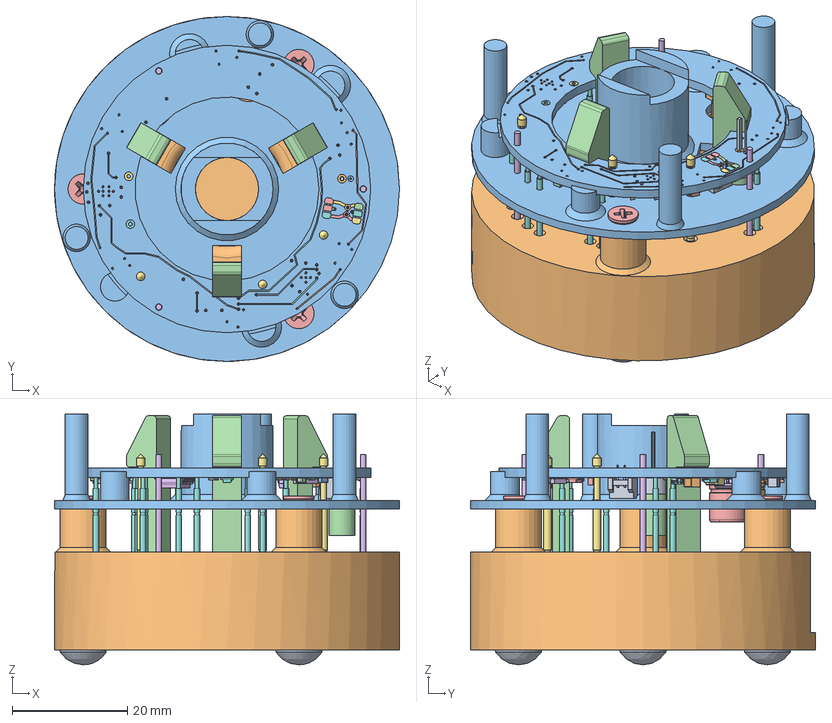
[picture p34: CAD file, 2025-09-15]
mechanical/cad/TestStandV2/TestStandV2.FCStd
60.0 x 60.0 x 43.6 mm
RubberPad x 3
Base
Guide
kicad_embedded_C5BDA16027A1B475F3AD32E60BB433C9
kicad_embedded_C5BDA16027A1B475F3AD32E60BB433C010
kicad_embedded_C5BDA16027A1B475F3AD32E60BB433C011
kicad_embedded_C5BDA16027A1B475F3AD32E60BB433C012
kicad_embedded_C5BDA16027A1B475F3AD32E60BB433C013
kicad_embedded_C5BDA16027A1B475F3AD32E60BB433C014
kicad_embedded_C5BDA16027A1B475F3AD32E60BB433C015
kicad_embedded_C5BDA16027A1B475F3AD32E60BB433C016
kicad_embedded_C5BDA16027A1B475F3AD32E60BB433C017
kicad_embedded_C5BDA16027A1B475F3AD32E60BB433C018
kicad_embedded_C5BDA16027A1B475F3AD32E60BB433C019
kicad_embedded_C5BDA16027A1B475F3AD32E60BB433C020
kicad_embedded_C5BDA16027A1B475F3AD32E60BB433C021
kicad_embedded_C5BDA16027A1B475F3AD32E60BB433C022
kicad_embedded_C5BDA16027A1B475F3AD32E60BB433C023
kicad_embedded_C5BDA16027A1B475F3AD32E60BB433C024
kicad_embedded_C5BDA16027A1B475F3AD32E60BB433C025
kicad_embedded_C5BDA16027A1B475F3AD32E60BB433C026
kicad_embedded_C5BDA16027A1B475F3AD32E60BB433C027
kicad_embedded_C5BDA16027A1B475F3AD32E60BB433C028
kicad_embedded_C5BDA16027A1B475F3AD32E60BB433C029
kicad_embedded_C5BDA16027A1B475F3AD32E60BB433C030
kicad_embedded_C5BDA16027A1B475F3AD32E60BB433C031
kicad_embedded_6F80DB4FE83919FEBE120546BF9211BB
kicad_embedded_6F80DB4FE83919FEBE120546BF9211BB001
kicad_embedded_6F80DB4FE83919FEBE120546BF9211BB002
kicad_embedded_6F80DB4FE83919FEBE120546BF9211BB003
kicad_embedded_6F80DB4FE83919FEBE120546BF9211BB004
kicad_embedded_6F80DB4FE83919FEBE120546BF9211BB005
kicad_embedded_6F80DB4FE83919FEBE120546BF9211BB006
kicad_embedded_6F80DB4FE83919FEBE120546BF9211BB007
kicad_embedded_6F80DB4FE83919FEBE120546BF9211BB008
kicad_embedded_6F80DB4FE83919FEBE120546BF9211BB009
kicad_embedded_6F80DB4FE83919FEBE120546BF9211BB010
kicad_embedded_6F80DB4FE83919FEBE120546BF9211BB011
kicad_embedded_6F80DB4FE83919FEBE120546BF9211BB012
kicad_embedded_6F80DB4FE83919FEBE120546BF9211BB013
kicad_embedded_6F80DB4FE83919FEBE120546BF9211BB014
kicad_embedded_6F80DB4FE83919FEBE120546BF9211BB015
kicad_embedded_6F80DB4FE83919FEBE120546BF9211BB016
kicad_embedded_6F80DB4FE83919FEBE120546BF9211BB017
kicad_embedded_6F80DB4FE83919FEBE120546BF9211BB018
kicad_embedded_6F80DB4FE83919FEBE120546BF9211BB019
kicad_embedded_6F80DB4FE83919FEBE120546BF9211BB020
kicad_embedded_6F80DB4FE83919FEBE120546BF9211BB021
kicad_embedded_6F80DB4FE83919FEBE120546BF9211BB022
R_0402_1005Metric
R_0402_1005Metric001
R_0402_1005Metric002
C_0402_1005Metric
R_0402_1005Metric003
C_0402_1005Metric001
R_0402_1005Metric004
R_0402_1005Metric005
kicad_embedded_3DF7FEB12B62EBF7ED4E8B8A585F0BB0
kicad_embedded_3DF7FEB12B62EBF7ED4E8B8A585F0BB001
kicad_embedded_3DF7FEB12B62EBF7ED4E8B8A585F0BB002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

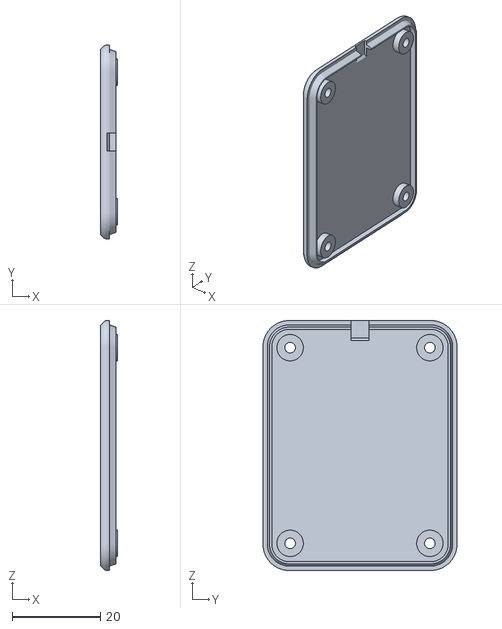
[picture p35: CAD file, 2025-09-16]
mechanical/cad/UPDIFlasherBox/UPDIFlasherBox-Bottom.stl
3.80 x 44.1 x 56.8

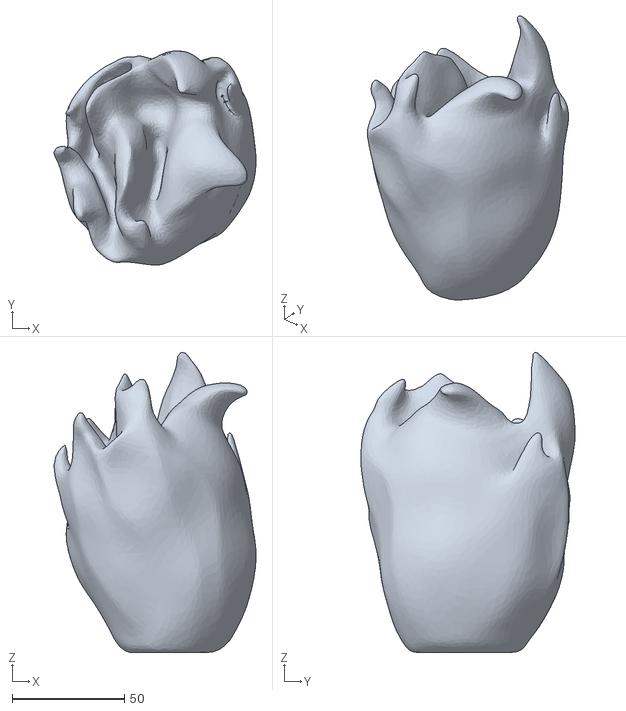
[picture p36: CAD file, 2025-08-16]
mechanical/stl/Flamme1.stl
89.9 x 95.4 x 133.6

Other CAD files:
mechanical/cad/TestStandV2/TestStandV2-Guide.stl
mechanical/cad/SW18030/SW18030.FCStd
mechanical/cad/TestStand/TestStand-Hook.stl
mechanical/cad/TestStand/TestStand-Top.stl
mechanical/art/Flamme2/Flamme2.blend
mechanical/art/Flamme3/Flamme3_1.blend
mechanical/art/Flamme3/Flamme3_2.blend
mechanical/art/Flamme3/Flamme3_3.blend
mechanical/art/Flamme3/Flamme3_4.blend
mechanical/cad/TestStand/TestStand-Bottom.stl
mechanical/cad/TestStand/TestStand.FCStd
mechanical/cad/TestStandV2/TestStandV2.3mf

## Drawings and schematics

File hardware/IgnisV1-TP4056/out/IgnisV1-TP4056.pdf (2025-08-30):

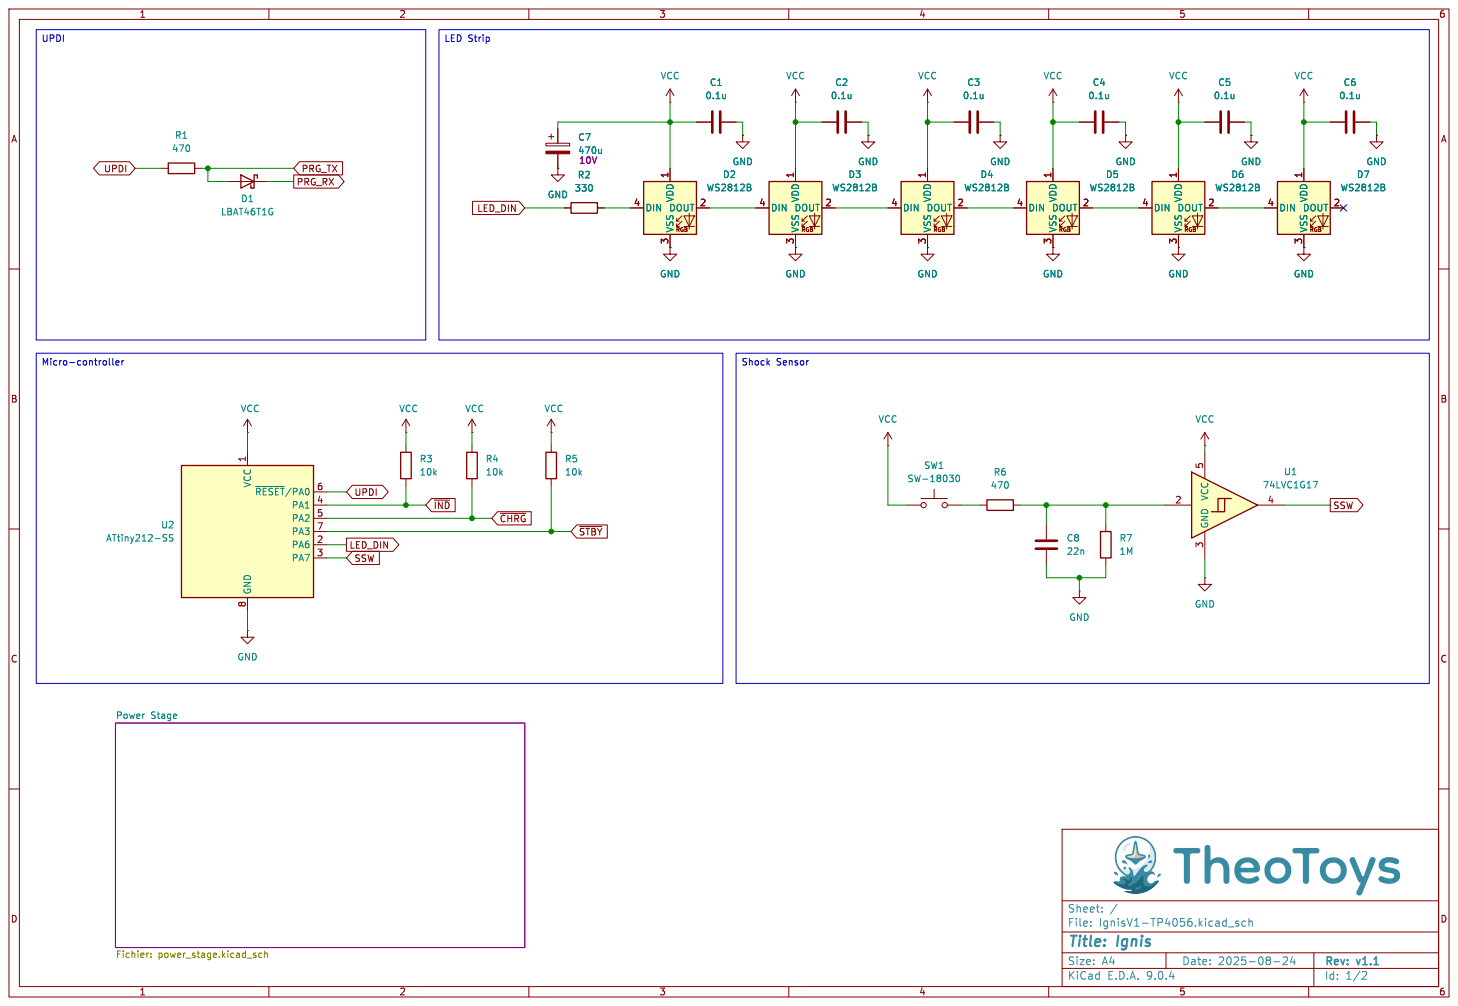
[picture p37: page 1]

8 ~{RESET}/PA06 PA1 4 PA2 5 PA3 7 PA6 2 PA7 3 U2 ATtiny212-SS GND GND GND

3 DOUT 2 GND GND GND

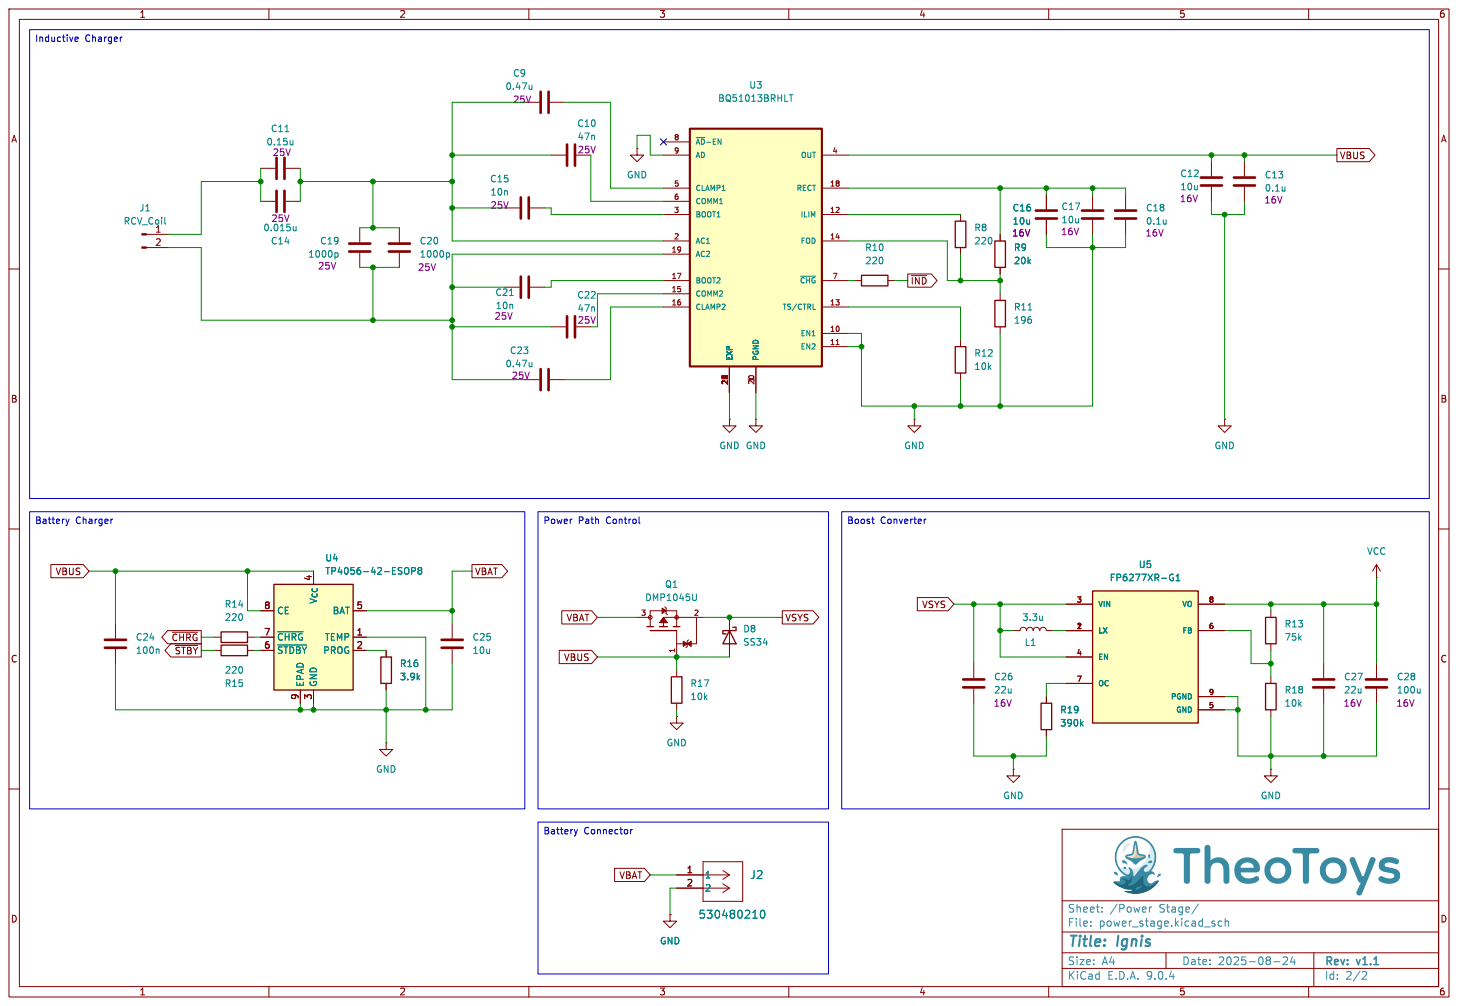
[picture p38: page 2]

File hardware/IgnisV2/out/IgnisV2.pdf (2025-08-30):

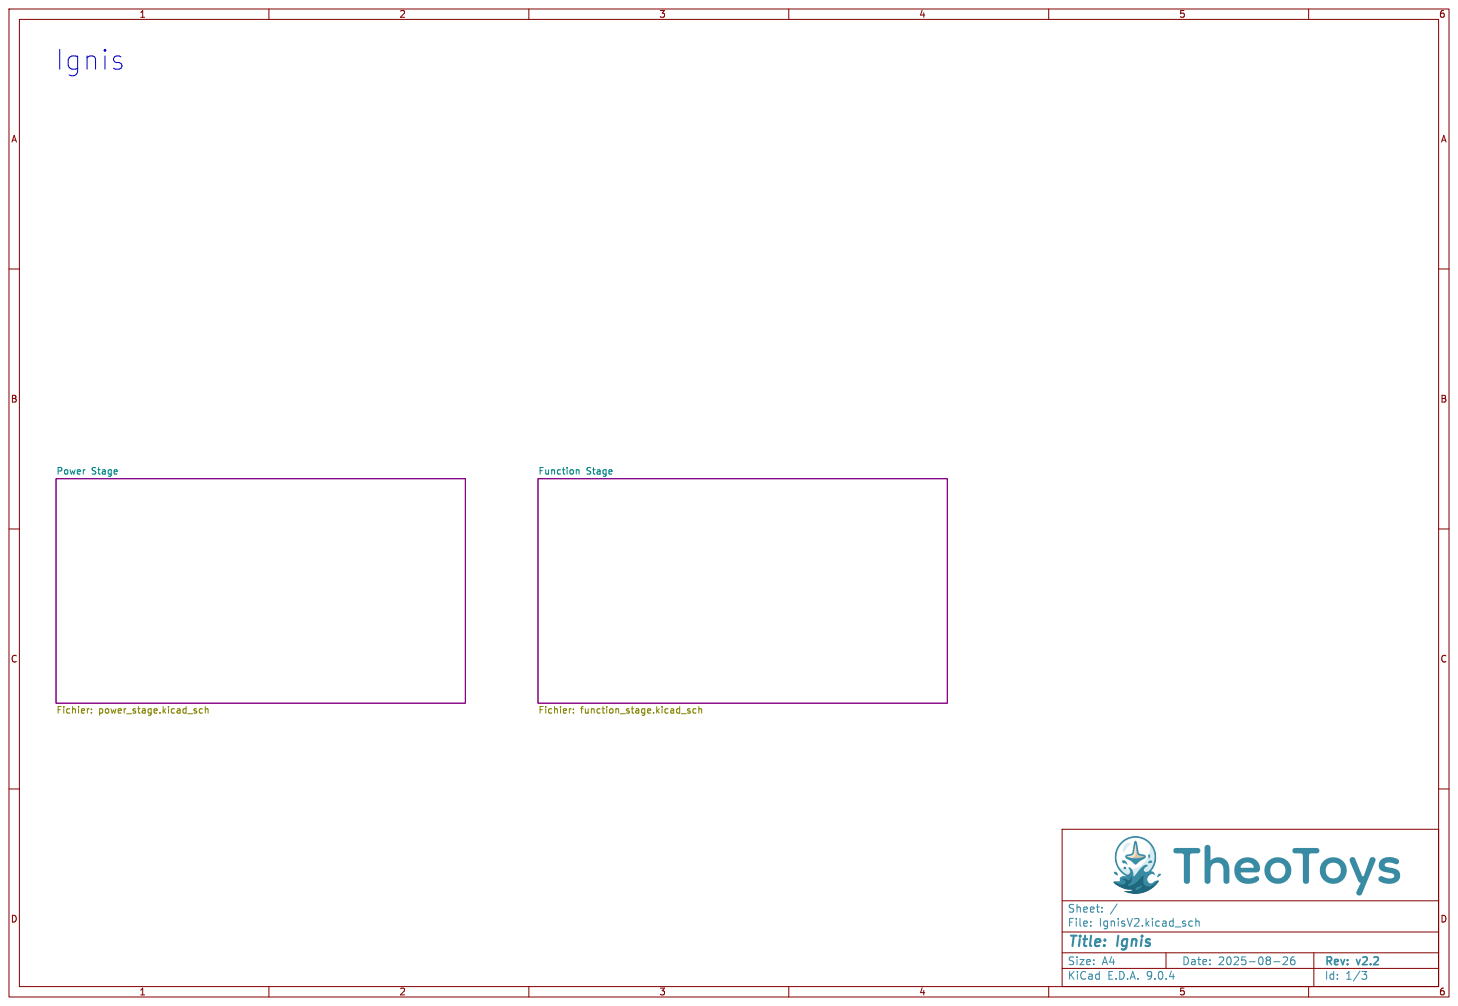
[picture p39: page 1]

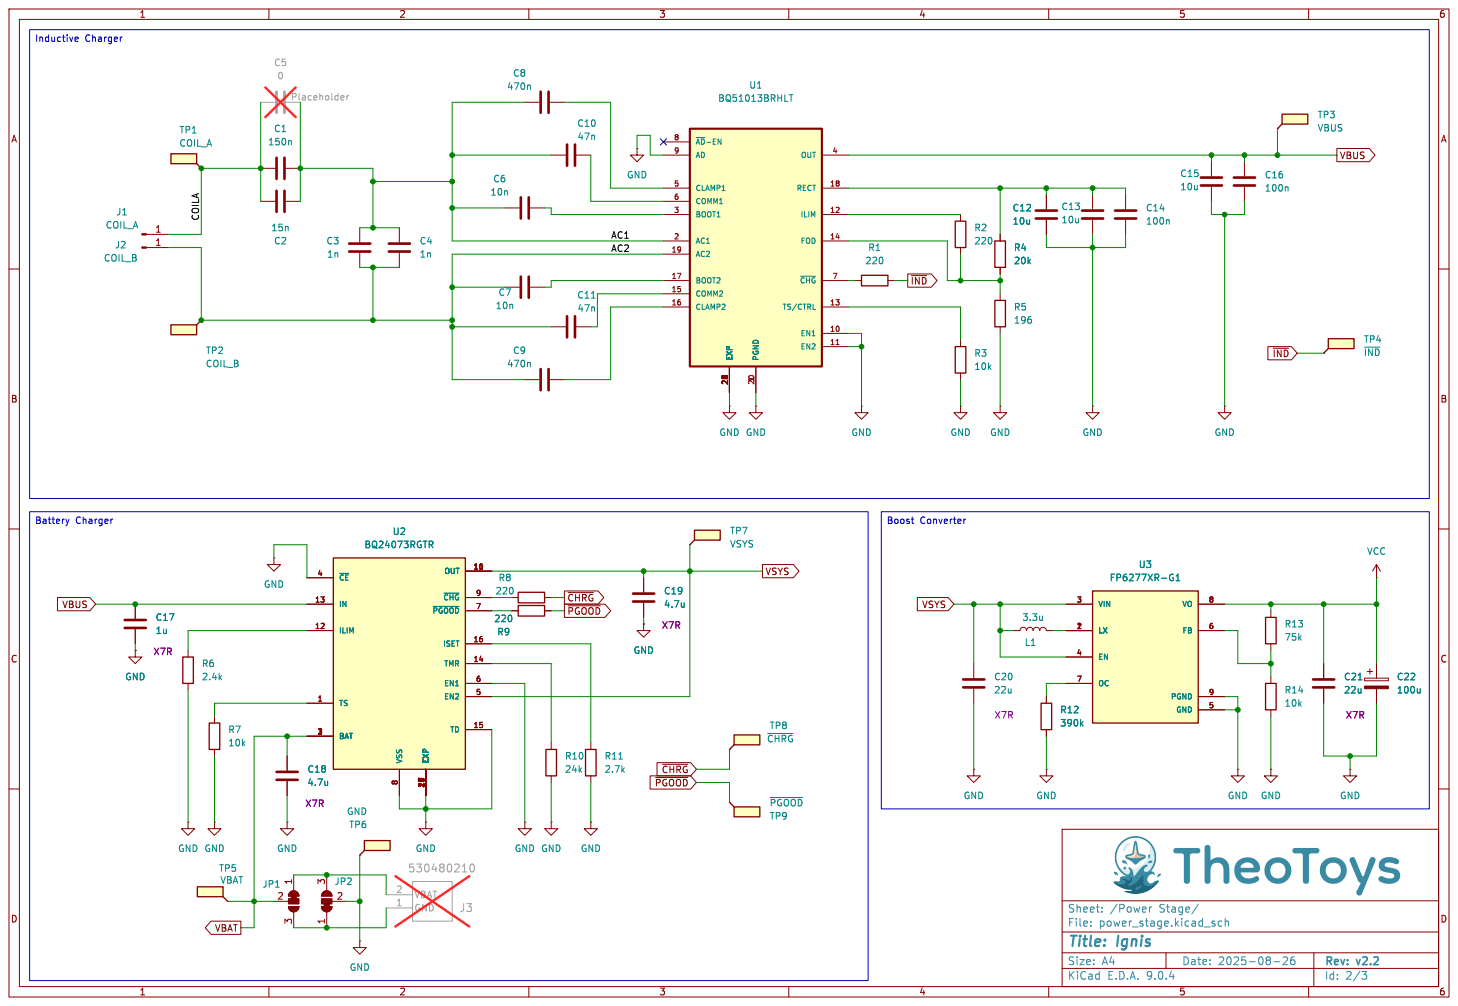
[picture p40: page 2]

8 EXP 17892012 OUT 101 ~{CHG} 9 ~{PGOOD} 7

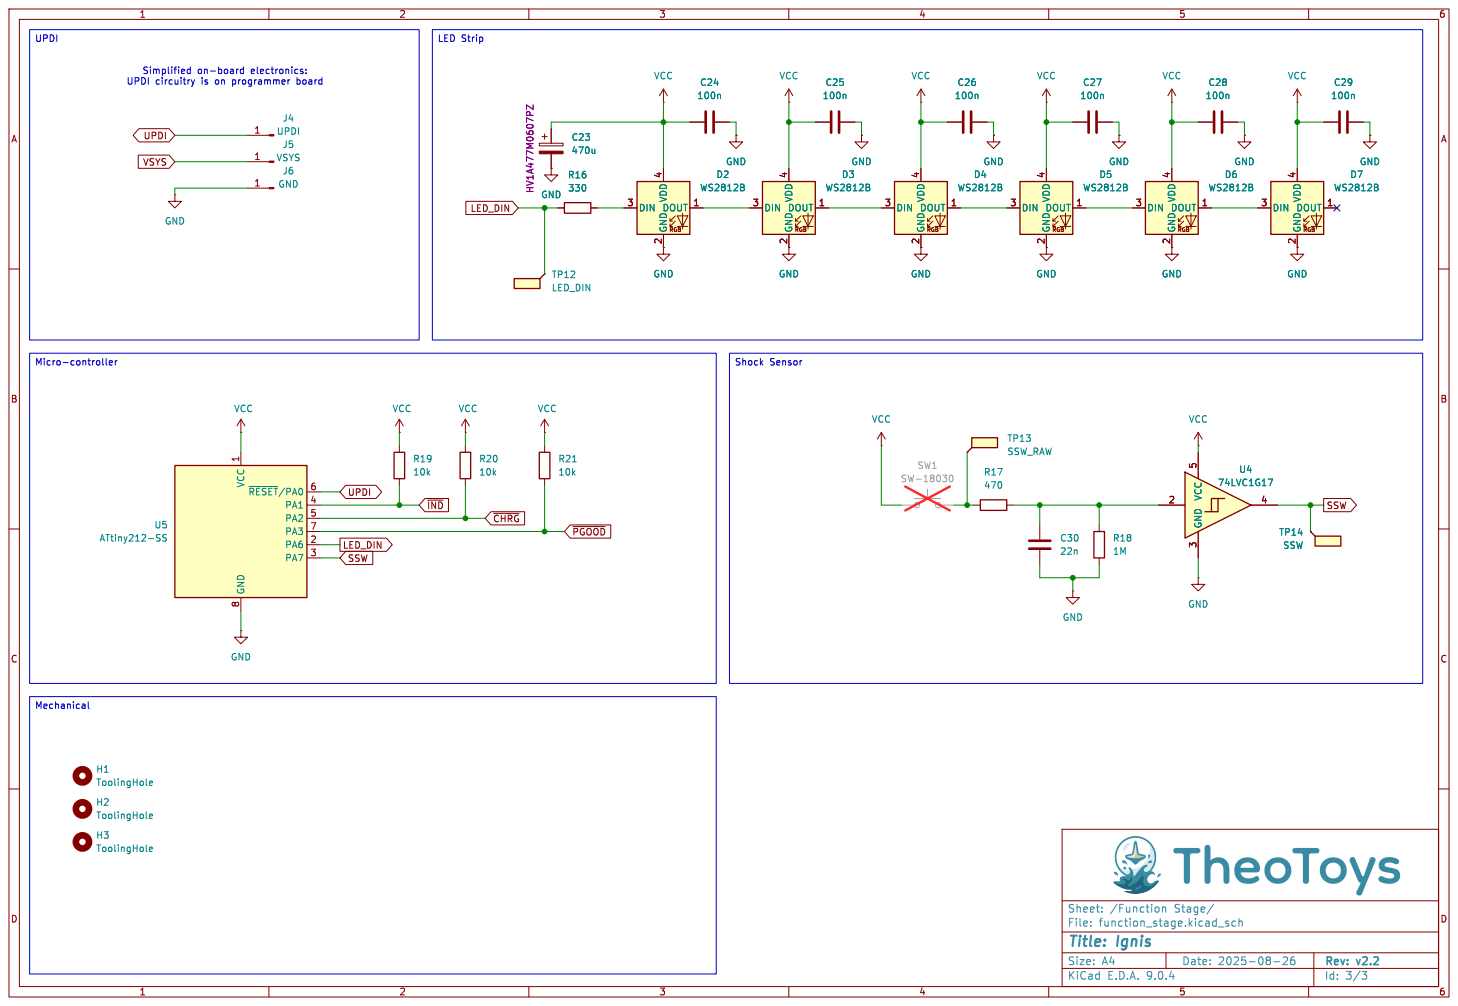
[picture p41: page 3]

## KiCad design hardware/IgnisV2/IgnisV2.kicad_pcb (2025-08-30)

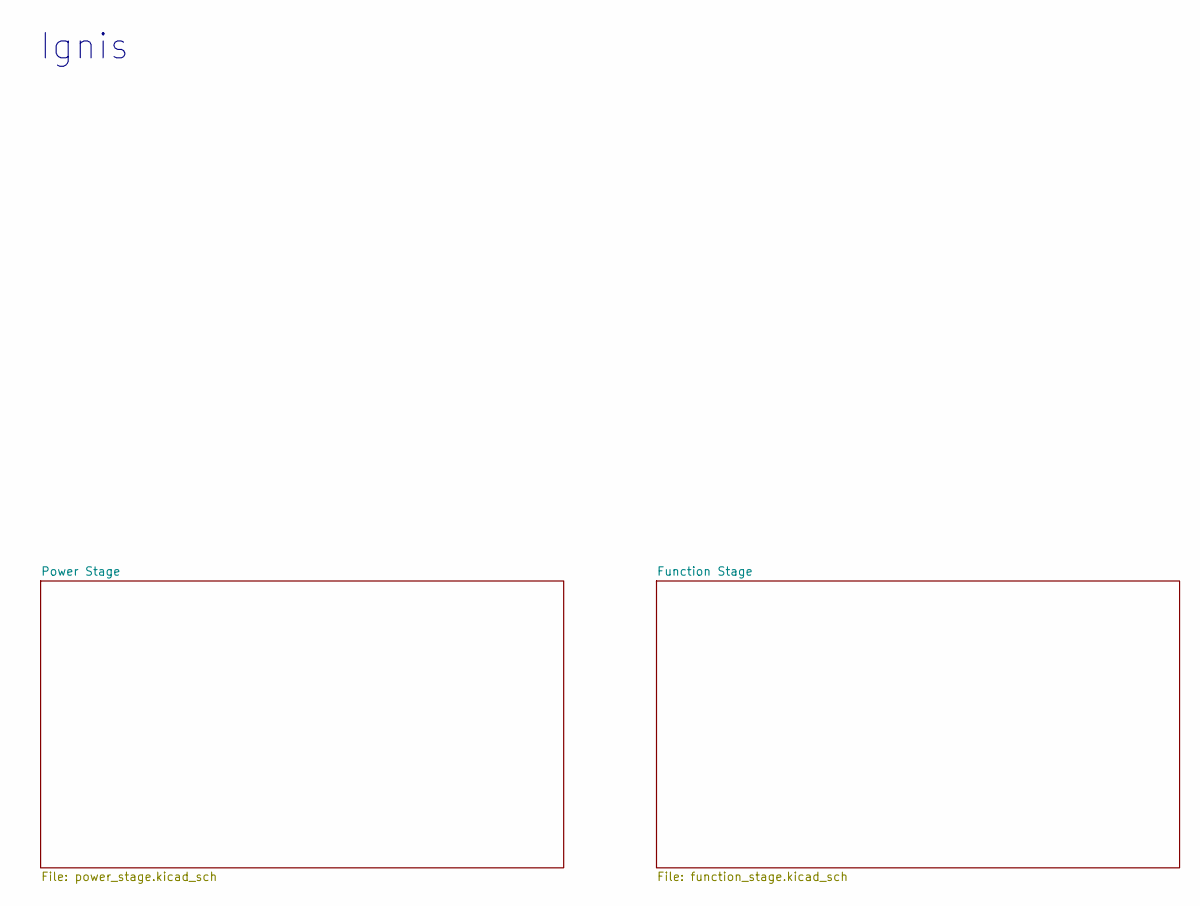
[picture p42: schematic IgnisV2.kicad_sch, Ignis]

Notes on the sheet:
Ignis

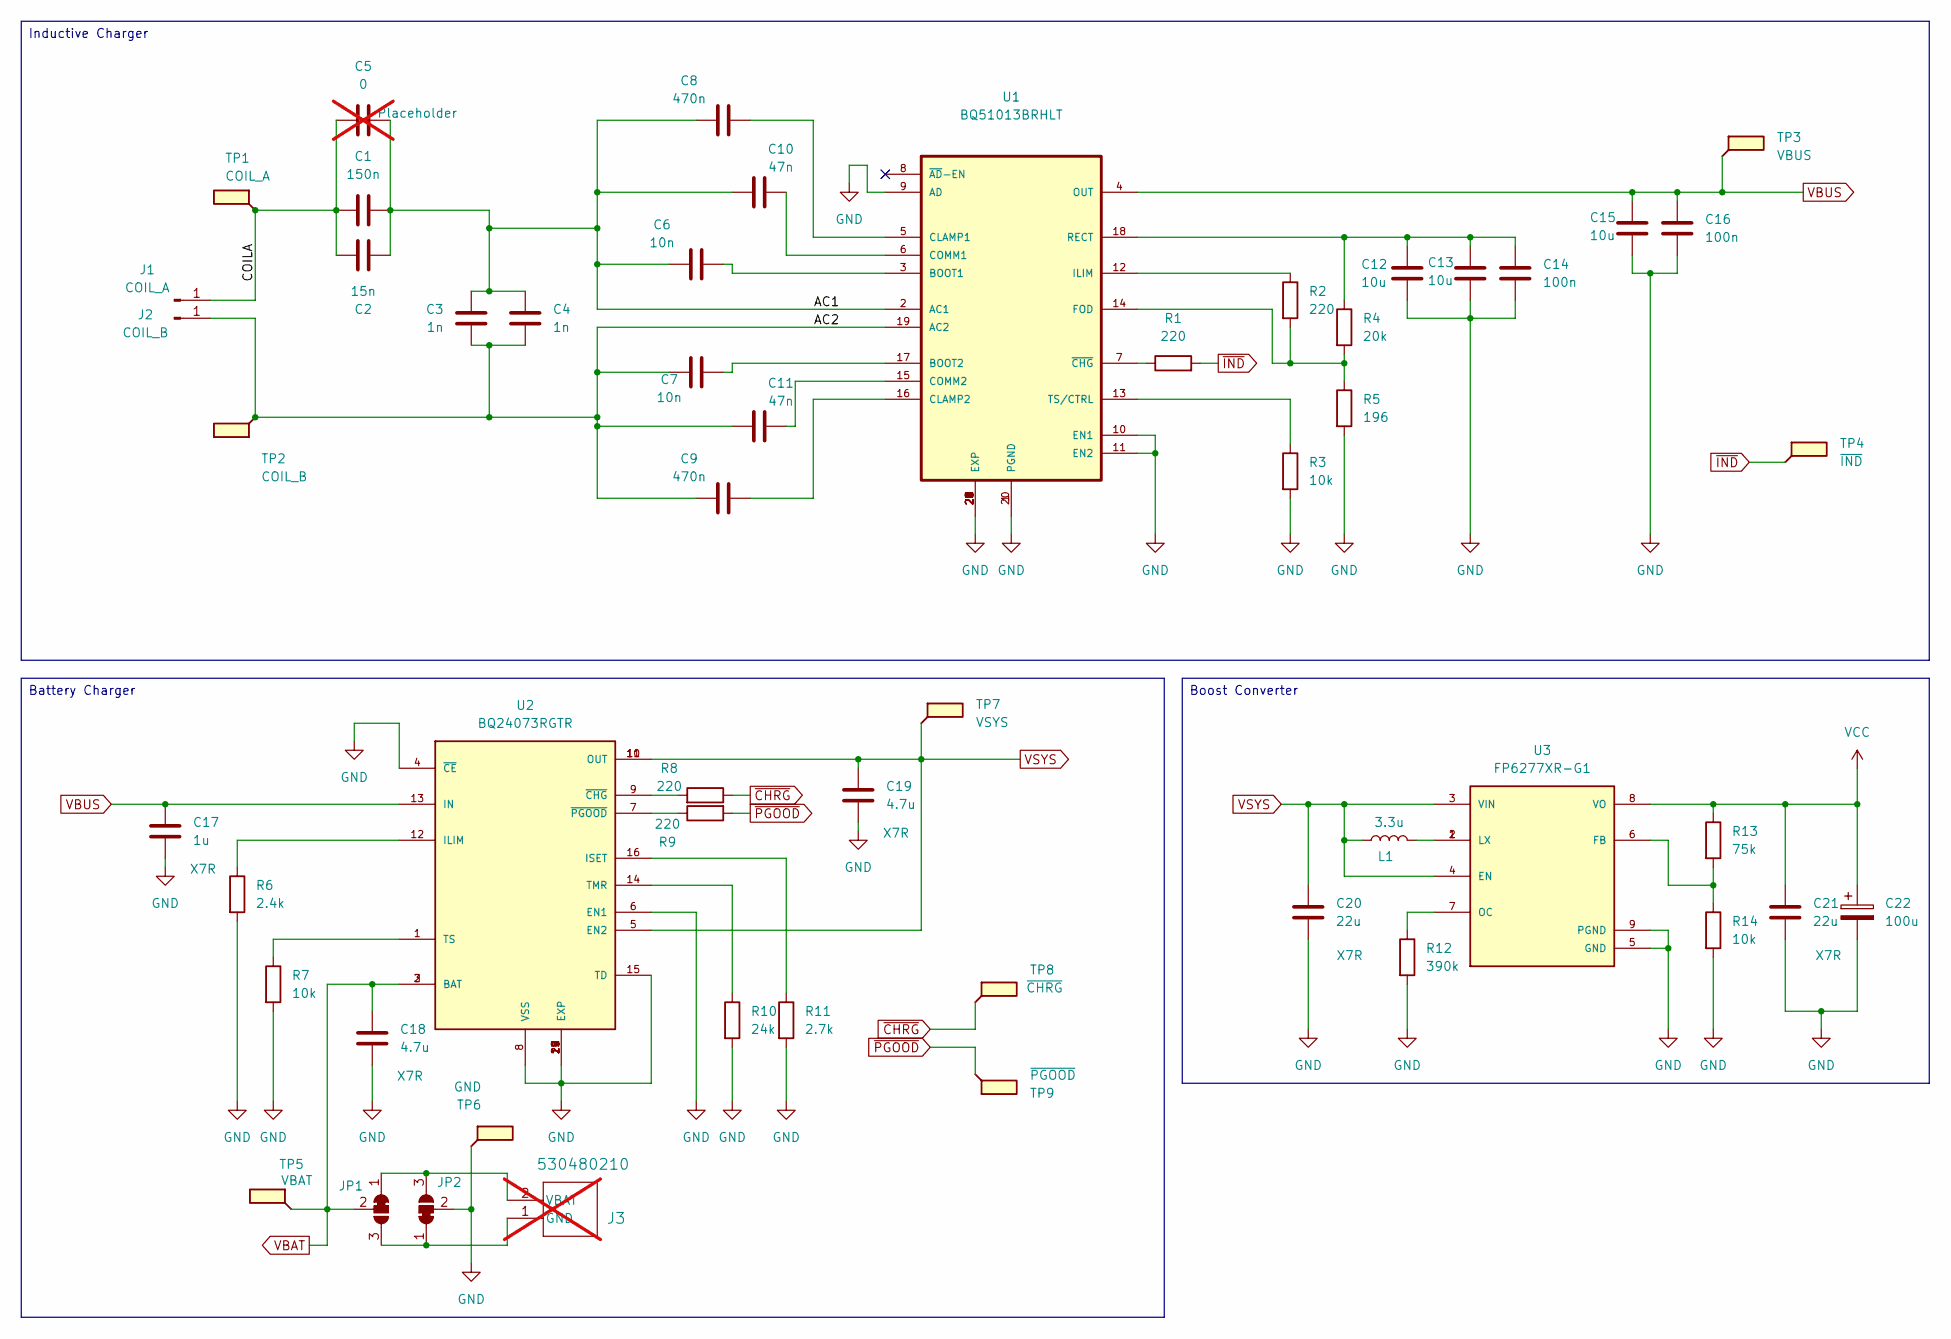
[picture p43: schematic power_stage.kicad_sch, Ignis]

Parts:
C1: 150n; C_0402_1005Metric; Voltage Rating 25V; LCSC C5448879
C2: 15n; C_0402_1005Metric; Voltage Rating 25V; LCSC C285020
C3, C4: 1n; C_0402_1005Metric; Voltage Rating 25V; LCSC C541372
C5: 0; C_0805_2012Metric_Pad1.18x1.45mm_HandSolder; Voltage Rating 25V; not fitted
C6, C7: 10n; C_0402_1005Metric; Voltage Rating 25V; LCSC C284987
C8, C9: 470n; C_0603_1608Metric; Voltage Rating 25V; LCSC C7503496
C10, C11: 47n; C_0402_1005Metric; Voltage Rating 25V; LCSC C5142571
C12, C13, C15: 10u; C_0402_1005Metric; Voltage Rating 16V; LCSC C7393849
C14, C16: 100n; C_0402_1005Metric; Voltage Rating 16V; LCSC C328914
C17: 1u; C_0603_1608Metric; Voltage Rating 16V; LCSC C76617
C18, C19: 4.7u; C_0603_1608Metric; Voltage Rating 16V; LCSC C22399629
C20, C21: 22u; C_1206_3216Metric; Voltage Rating 16V; LCSC C6119995
C22: 100u; CP_Elec_5x5.4; Voltage Rating 16V; LCSC C7461241
J1: COIL_A; TestPoint_THTPad_D1.5mm_Drill0.7mm
J2: COIL_B; TestPoint_THTPad_D1.5mm_Drill0.7mm
J3: 530480210; CONN02_530480210_MOL; not fitted
JP1: VBATS; SolderJumper-3_P1.3mm_Bridged12_RoundedPad1.0x1.5mm
JP2: VGNDS; SolderJumper-3_P1.3mm_Bridged12_RoundedPad1.0x1.5mm
L1: 3.3u; L_1008_2520Metric; LCSC C2049754
R1, R8, R9: 220; R_0402_1005Metric; LCSC C25091
R2: 220; R_0805_2012Metric; LCSC C17557
R3, R7, R14: 10k; R_0402_1005Metric; LCSC C25531
R4: 20k; R_0402_1005Metric; LCSC C25545
R5: 196; R_0805_2012Metric; LCSC C407413
R6: 2.4k; R_0402_1005Metric; LCSC C25882
R10: 24k; R_0402_1005Metric; LCSC C25549
R11: 2.7k; R_0402_1005Metric; LCSC C25885
R12: 390k; R_0402_1005Metric; LCSC C25557
R13: 75k; R_0402_1005Metric; LCSC C25570
TP1: COIL_A; TestPoint_Pad_D1.0mm
TP2: COIL_B; TestPoint_Pad_D1.0mm
TP3: VBUS; TestPoint_Pad_D1.0mm
TP4: ~{IND}; TestPoint_Pad_D1.0mm
TP5: VBAT; TestPoint_Pad_D1.0mm
TP6: GND; TestPoint_Pad_D1.0mm
TP7: VSYS; TestPoint_Pad_D1.0mm
TP8: ~{CHRG}; TestPoint_Pad_D1.0mm
TP9: ~{PGOOD}; TestPoint_Pad_D1.0mm
U1: BQ51013BRHLT; LCSC C2650154
U2: BQ24073RGTR; IC_BQ24073RGTR; LCSC C15220
U3: FP6277XR-G1; SOIC127P599X175-9N; PARTREV 0.65; LCSC C88312

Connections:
/Power Stage/AC1: C1.2, C2.2, C3.2, C4.2, C5.2, C6.1, C8.1, C10.1, U1.2 (AC1)
/Power Stage/AC2: C3.1, C4.1, C7.1, C9.1, C11.1, J2.1, TP2.1, U1.19 (AC2)
/Power Stage/COILA: C1.1, C2.1, C5.1, J1.1, TP1.1
GND: C12.2, C13.2, C14.2, C15.2, C16.2, C17.2, C18.2, C19.2, C20.2, C21.2, C22.2, JP2.2 (C), R3.2, R5.2, R6.2, R7.2, R10.2, R11.2, R12.2, R14.2, TP6.1, U1.1 (PGND), U1.9 (AD), U1.10 (EN1), U1.11 (EN2), U1.20 (PGND), U1.21 (EXP), U1.22 (EXP), U1.23 (EXP), U1.24 (EXP), U1.25 (EXP), U1.26 (EXP), U1.27 (EXP), U1.28 (EXP), U1.29 (EXP), U2.4 (~CE), U2.6 (EN1), U2.8 (VSS), U2.15 (TD), U2.17 (EXP), U2.18 (EXP), U2.19 (EXP), U2.20 (EXP), U2.21 (EXP), U2.22 (EXP), U3.5 (GND), U3.9 (PGND); also elsewhere on the board
unnamed: J3.1 (GND), JP1.3 (B), JP2.1 (A)
unnamed: J3.2 (VBAT), JP1.1 (A), JP2.3 (B)
unnamed: L1.2, U3.1 (LX), U3.2 (LX)
unnamed: C6.2, U1.3 (BOOT1)
unnamed: C7.2, U1.17 (BOOT2)
unnamed: C8.2, U1.5 (CLAMP1)
unnamed: C9.2, U1.16 (CLAMP2)
unnamed: C10.2, U1.6 (COMM1)
unnamed: C11.2, U1.15 (COMM2)
unnamed: R2.2, R4.2, R5.1, U1.14 (FOD)
unnamed: R2.1, U1.12 (ILIM)
unnamed: C12.1, C13.1, C14.1, R4.1, U1.18 (RECT)
unnamed: R3.1, U1.13 (TS/CTRL)
unnamed: R1.1, U1.7 (~CHG)
unnamed: R6.1, U2.12 (ILIM)
unnamed: R11.1, U2.16 (ISET)
unnamed: R10.1, U2.14 (TMR)
unnamed: R7.1, U2.1 (TS)
unnamed: R8.2, U2.9 (~CHG)
unnamed: R9.1, U2.7 (~PGOOD)
unnamed: R13.2, R14.1, U3.6 (FB)
unnamed: R12.1, U3.7 (OC)
VBAT: C18.1, JP1.2 (C), TP5.1, U2.2 (BAT), U2.3 (BAT)
VBUS: C15.1, C16.1, C17.1, TP3.1, U1.4 (OUT), U2.13 (IN)
VCC: C21.1, C22.1, R13.1, U3.8 (VO); also elsewhere on the board
VSYS: C19.1, C20.1, L1.1, TP7.1, U2.5 (EN2), U2.10 (OUT), U2.11 (OUT), U3.3 (VIN), U3.4 (EN); also elsewhere on the board
~CHRG: R8.1, TP8.1; also elsewhere on the board
~IND: R1.2, TP4.1; also elsewhere on the board
~PGOOD: R9.2, TP9.1; also elsewhere on the board

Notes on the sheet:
Inductive Charger
Battery Charger
Boost Converter

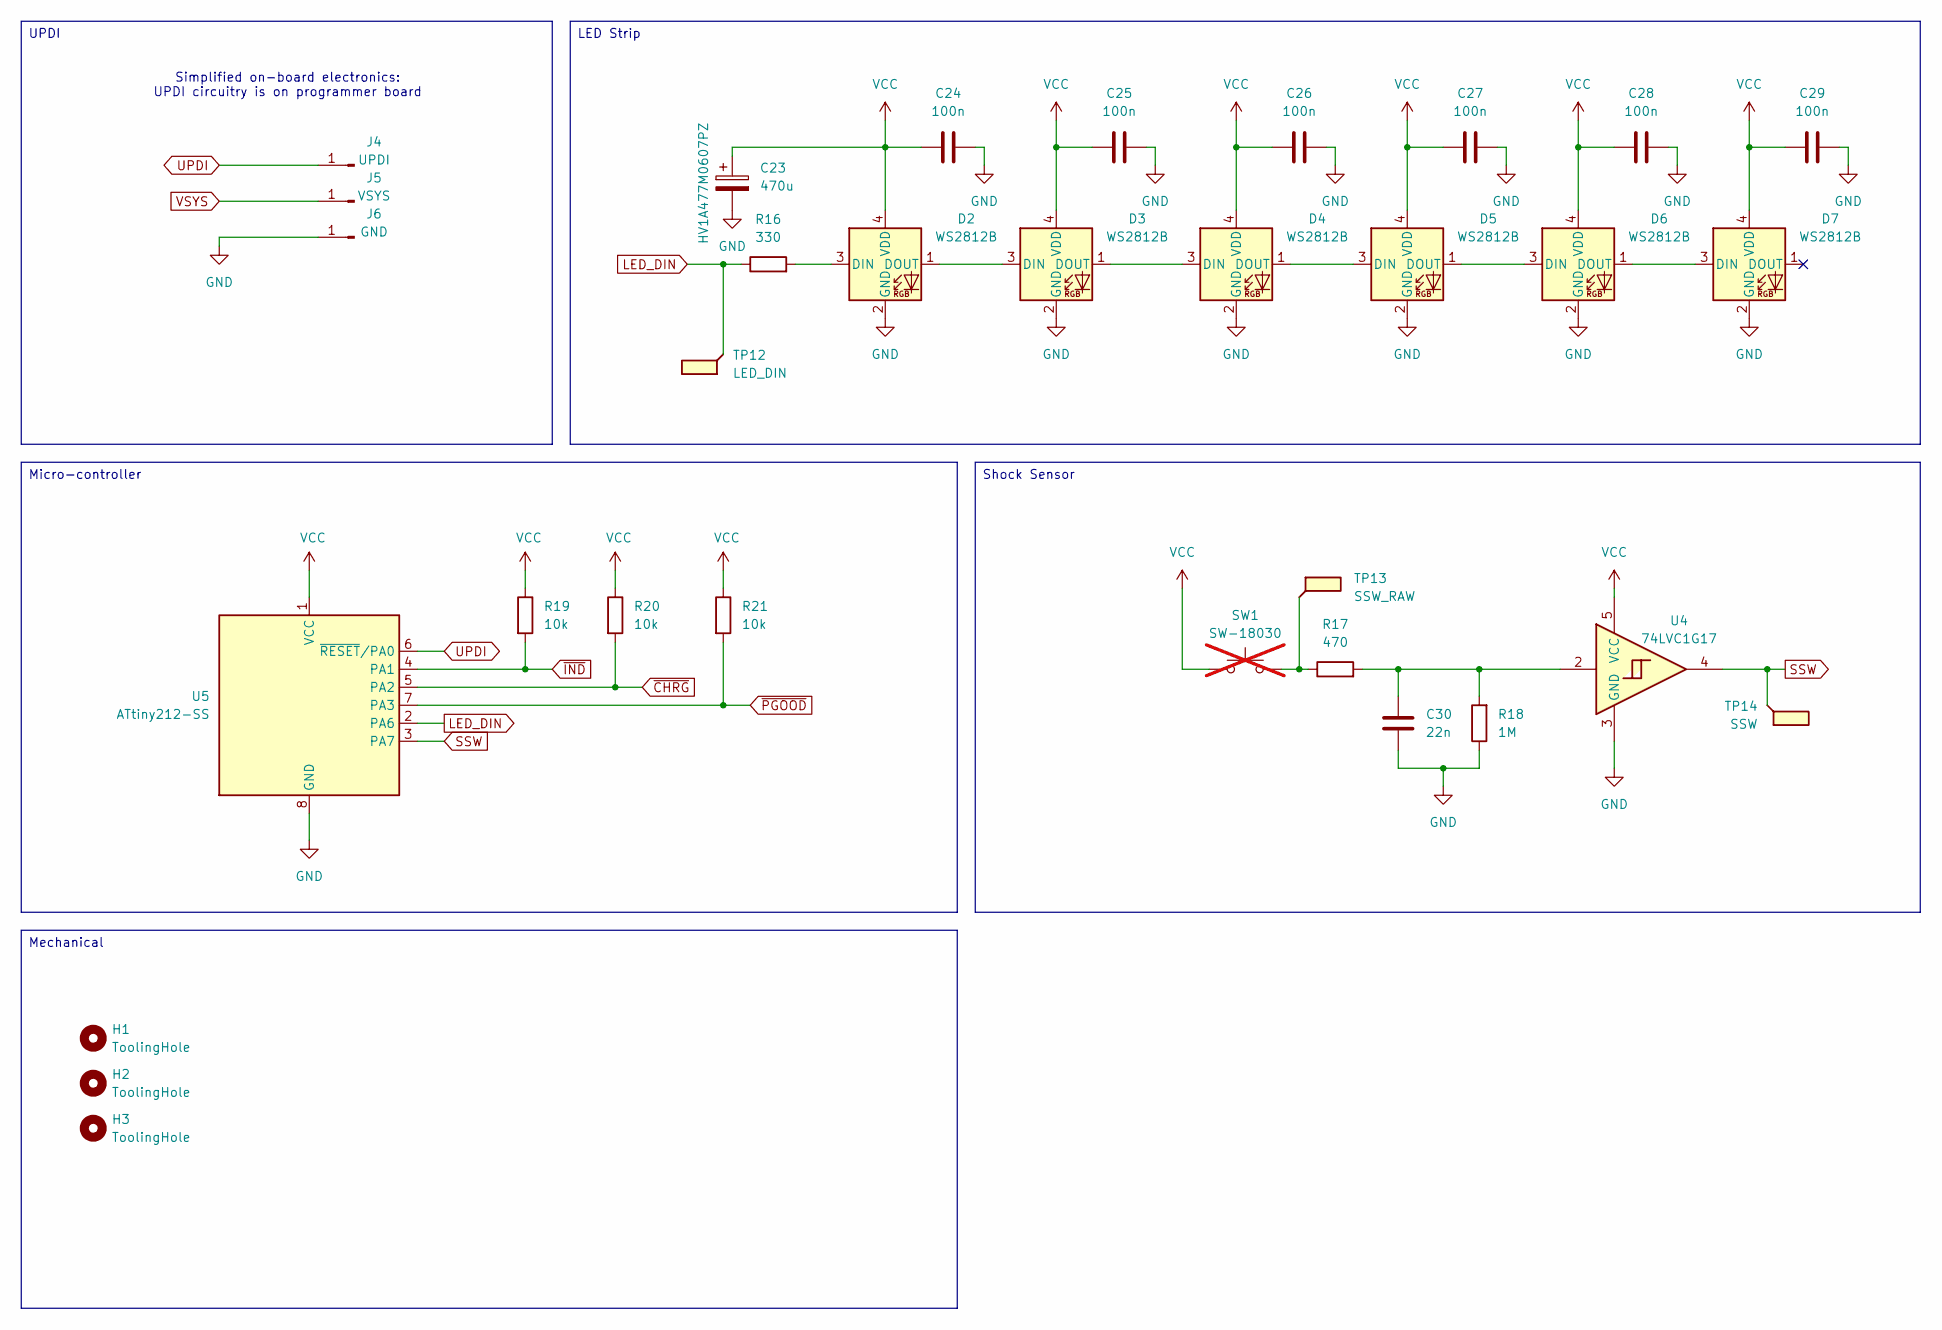
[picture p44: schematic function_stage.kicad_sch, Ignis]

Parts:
C23: 470u; CP_Elec_6.3x7.7; Voltage Rating 10V; LCSC C5246516
C24, C25, C26, C27, C28, C29: 100n; C_0402_1005Metric; LCSC C328914
C30: 22n; C_0402_1005Metric; LCSC C6266887
D2, D3, D4, D5, D6, D7: WS2812B; LED_WS2812B2020; LCSC C965555
H1, H2, H3: ToolingHole; ToolingHole_1.152mm
J4: UPDI; TestPoint_THTPad_D1.5mm_Drill0.7mm
J5: VSYS; TestPoint_THTPad_D1.5mm_Drill0.7mm
J6: GND; TestPoint_THTPad_D1.5mm_Drill0.7mm
R16: 330; R_0402_1005Metric; LCSC C12246
R17: 470; R_0402_1005Metric; LCSC C25167
R18: 1M; R_0402_1005Metric; LCSC C26087
R19, R20, R21: 10k; R_0402_1005Metric; LCSC C25531
SW1: SW-18030; SW-180; not fitted
TP12: LED_DIN; TestPoint_Pad_D1.0mm
TP13: SSW_RAW; TestPoint_Pad_D1.0mm
TP14: SSW; TestPoint_Pad_D1.0mm
U4: 74LVC1G17; IC_74LVC1G17GW_125; LCSC C426705
U5: ATtiny212-SS; SOIC-8_3.9x4.9mm_P1.27mm; LCSC C615533

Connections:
GND: C23.2, C24.2, C25.2, C26.2, C27.2, C28.2, C29.2, C30.2, D2.2 (GND), D3.2 (GND), D4.2 (GND), D5.2 (GND), D6.2 (GND), D7.2 (GND), J6.1, R18.1, U4.3 (GND), U5.8 (GND); also elsewhere on the board
LED_DIN: R16.1, TP12.1, U5.2 (PA6)
unnamed: C30.1, R17.2, R18.2, U4.2
unnamed: D2.3 (DIN), R16.2
unnamed: D2.1 (DOUT), D3.3 (DIN)
unnamed: D3.1 (DOUT), D4.3 (DIN)
unnamed: D4.1 (DOUT), D5.3 (DIN)
unnamed: D5.1 (DOUT), D6.3 (DIN)
unnamed: D6.1 (DOUT), D7.3 (DIN)
unnamed: R17.1, SW1.2, TP13.1
SSW: TP14.1, U4.4, U5.3 (PA7)
UPDI: J4.1, U5.6 (~RESET/PA0)
VCC: C23.1, C24.1, C25.1, C26.1, C27.1, C28.1, C29.1, D2.4 (VDD), D3.4 (VDD), D4.4 (VDD), D5.4 (VDD), D6.4 (VDD), D7.4 (VDD), R19.1, R20.1, R21.1, SW1.1, U4.5 (VCC), U5.1 (VCC); also elsewhere on the board
VSYS: J5.1; also elsewhere on the board
~CHRG: R20.2, U5.5 (PA2); also elsewhere on the board
~IND: R19.2, U5.4 (PA1); also elsewhere on the board
~PGOOD: R21.2, U5.7 (PA3); also elsewhere on the board

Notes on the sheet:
Simplified on-board electronics: UPDI circuitry is on programmer board
Shock Sensor
UPDI
Micro-controller
LED Strip
Mechanical

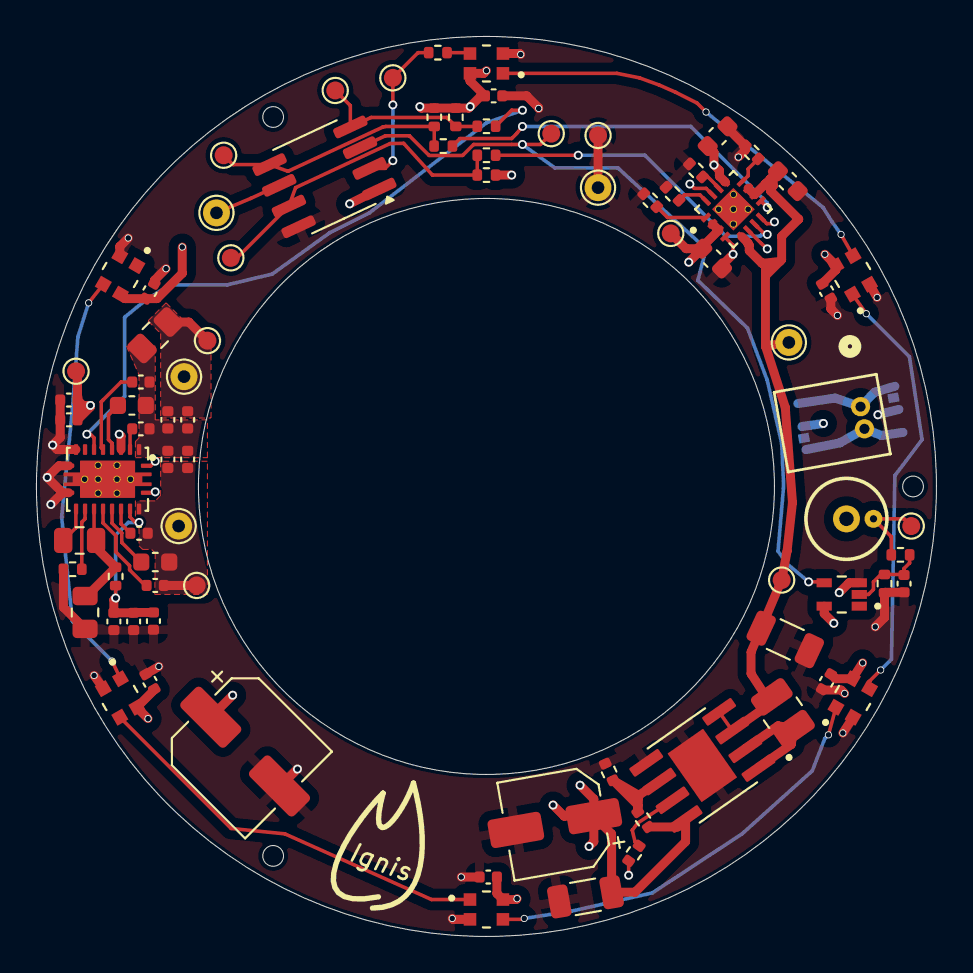
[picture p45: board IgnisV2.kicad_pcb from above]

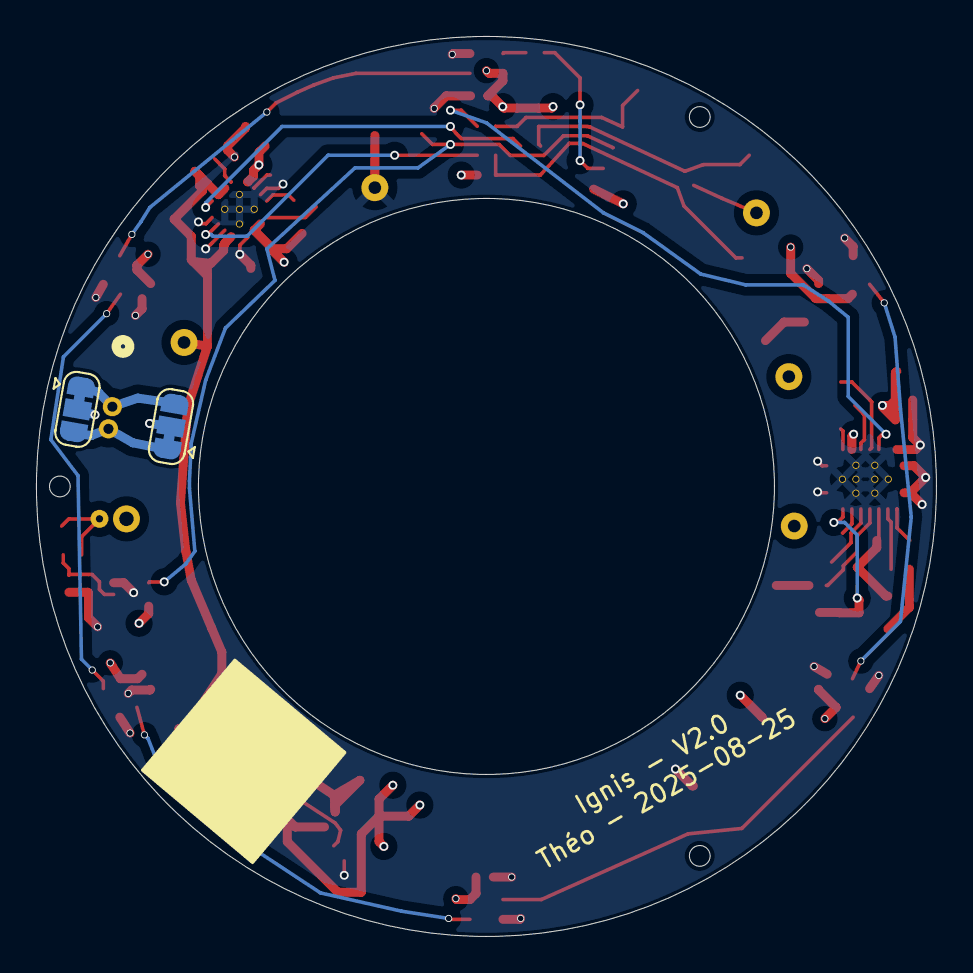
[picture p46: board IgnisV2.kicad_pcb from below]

Board: 4 copper layers, 50.0 x 50.0 mm, 86 parts (2 on the bottom side), 44 nets.

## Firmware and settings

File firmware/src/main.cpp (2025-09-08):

#include "board.h"
#include <avr/interrupt.h>
#include <tinyNeoPixel_Static.h>

byte pixels[NUM_LEDS * 3];

tinyNeoPixel leds = tinyNeoPixel(NUM_LEDS, PIN_LED, NEO_GRB + NEO_KHZ800, pixels);

int current_led = 0;
enum State { RED = 0, GREEN = 1, BLUE = 2, PURPLE = 3, YELLOW = 4, CYAN = 5, WHITE = 6 };
State current_state = RED;

void setup() {
  // pinMode(PIN_SSW, INPUT);
  pinMode(PIN_LED, OUTPUT);

  // Configuration interruption pour ATtiny212
  // Activer interruption sur PORTA pin 2
  // PORTA.PIN2CTRL = PORT_ISC_BOTHEDGES_gc; // Interruption sur les deux fronts

  // sei(); // Activer interruptions globales

  leds.fill(); // Éteindre toutes les LEDs
  leds.show(); // Initialiser les LEDs
}

void loop() {
  current_led++;
  int red, green, blue;
  if (current_led >= NUM_LEDS) {
    current_led = 0;
    delay(500);  // Attendre 500 ms du plus pour laisser le temps de calculer la conso
    leds.fill(); // Éteindre toutes les LEDs
    leds.show(); // Mettre à jour les LEDs
    delay(500);  // Attendre 500 ms avant de rallumer la LED
    current_state = static_cast<State>((current_state + 1) % 7); // Passer à l'état suivant
  }
  switch (current_state) {
  case RED:
    red = 255;
    green = 0;
    blue = 0;
    break;
  case GREEN:
    red = 0;
    green = 255;
    blue = 0;
    break;
  case BLUE:
    red = 0;
    green = 0;
    blue = 255;
    break;
  case PURPLE:
    red = 128;
    green = 0;
    blue = 128;
    break;
  case YELLOW:
    red = 255;
    green = 255;
    blue = 0;
    break;
  case CYAN:
    red = 0;
    green = 255;
    blue = 255;
    break;
  case WHITE:
    red = 255;
    green = 255;
    blue = 255;
    break;
  default:
    red = 0;
    green = 0;
    blue = 0;
    break;
  }
  leds.setPixelColor(current_led, red, green, blue); // Allumer la LED actuelle en rouge
  leds.show();
  delay(500);
}

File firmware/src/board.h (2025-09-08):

/**
 * @file board.h
 * @brief Hardware abstraction layer for Ignis V2.2 PCB
 *
 * Project: Ignis - Autonomous flame-shaped lamp with wireless charging
 * Hardware: IgnisV2 PCB with ATtiny212, BQ24073, BQ51013B, WS2812B-2020
 * Version: V2.2
 *
 * This file contains board-specific definitions including pin assignments,
 * hardware configuration constants, and peripheral mappings for the
 * IgnisV2.2 PCB design.
 *
 * @author TheoToys
 * @date September 2025
 * @license MIT License - See LICENSE file for details
 */

#ifndef BOARD_H
#define BOARD_H

#include <Arduino.h>

// Board identification
#define BOARD_VERSION "IgnisV2.2"
#define BOARD_MCU "ATtiny212"

#define PIN_UPDI PIN_PA0    // UPDI programming pin
#define PIN_IND_B PIN_PA1   // Low when inductor receives power
#define PIN_CHRG_B PIN_PA2  // Low when battery is charging
#define PIN_PGOOD_B PIN_PA3 // Low when charging is complete
#define PIN_LED PIN_PA6     // WS2812B data pin
#define PIN_SSW PIN_PA7     // Shock detection switch pin

#define NUM_LEDS 6

#endif // BOARD_H

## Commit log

2025-08-15 🔥 Initial commit: Ignis flame lamp project setup
    ✅ Project structure & workspace configuration
    - VS Code workspace with PlatformIO integration
    - K&R code formatting configured (.clang-format)
    - Structured folders: firmware/, hardware/, mechanical/, docs/
    ✅ Firmware foundation (ATtiny212/412)
    - Working minimal firmware with button handling
    - Proper AVR interrupts (ISR) for ATtiny212
    - PlatformIO configuration for both ATtiny variants
    - Compiles successfully without errors
    ✅ Complete component datasheets
    - ATtiny212, WS2812B, TP4056, FP6277, DMP1045U, EEMB LP402535
    - Reference schematics for power management circuits
    - Technical documentation and specifications
    ✅ Development envi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
    [main.cpp]
2025-08-15 💡 Bootstrap using tinyNeoPixel for LED strip control
    - Add tinyNeoPixel library to handle LED strip
    - Configure led pins
2025-08-15 😠 Had to add firmware/.vscode/extensions.json because PlatformIO keeps recreating it in the wrong place
    - Check workspace file `Ignis.code-workspace` for real use
2025-08-15 🎨 Add initial and polished flame Blender models
    - Flamme1.blend: first version of simple flame shape
    - Flamme2.blend: refined flame with added eyes
    [Flamme2.blend]
2025-08-16 🧊 Finalize Blender models and exports
    - Restructure art/ directory with individual folders for each flame design
    - Add PNG previews and STL exports for both Flamme1 and Flamme2 models
    - Create dedicated stl/ directory with ready-to-print files filtered by Orca
    - Add comprehensive documentation for 3D models and printing guidelines
    [Flamme1.stl, Flamme2.blend, Flamme2.stl]
2025-08-17 🔺 Add low-poly flame models with PLA gradient materials
    - New low poly model derived from Flamme1.
    - Enhanced Blender workflow with automated screenshot export.
    - Updated material system to simulate PLA filament gradient (brown → yellow) for realistic 3D printing preview.
    [Flamme1_lowpoly.stl, Flamme2.blend]
2025-08-17 🧹 Harmonisation docs : Lampe Ignis, conventions commit
    - Remplacement de "Flamme dans le sable" par "Lampe Ignis" partout
    - Ajout des règles d'emoji et de style pour les messages de commit
    - Clarification du concept du sable dans la documentation
2025-08-17 ✨ Experimental Flamme3 series with 4 variants and documentation
    - Exploring new Blender modeling techniques with advanced modifiers and sculpting.
    - Flamme3_4 stands out as the most refined model, with STL export ready for printing.
    [Flamme3.stl, Flamme3_1.blend, Flamme3_2.blend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]
2025-08-17 📐 Corrected and updated electronic design calculations
    - Passives for TP4056
    - Passives for FP6277 Boost
    - Cleanup
2025-08-22 🔋 Implement BQ51013B inductive charging with TP4056 design
    - Implemented the BQ51013B for inductive recharge.
    - Implemented in the TP4056 design, but this will be abandonned to a BQ24073.
    - Added all needed components to Ignis library of symbols and footprints.
    - See calculations in `docs/calculations/electrical_design.md`
    [IgnisV1-TP4056.kicad_pcb, IgnisV1-TP4056.kicad_sch, power_stage.kicad_sch]
2025-08-23 ⚡ Rework LED strip and add shock switch filtering
    Includes rework of the LED strip
    Includes filter with schmidt trigger buffer to input shock switch SW18030
    [IgnisV1-TP4056.kicad_sch, IgnisV1.kicad_pcb, IgnisV1.kicad_sch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]
2025-08-23 🧩 Finalize IgnisV1-TP4056 schematics & add reference design
    - Finished schematics by adding necessary pull-ups on signal lines.
    - Copied electrical design from an older version for reference and traceability.
    [IgnisV1-TP4056.kicad_sch, power_stage.kicad_sch]
2025-08-23 💼 Add jobset to KiCAD project
    - Added IgnisV1-TP4056.kicad_jobset to the project for improved job management.
2025-08-24 🔧 Add complete SW-18030 component with KiCAD footprint and 3D model
    - Created missing KiCAD footprint for SW-18030 component
    - Designed 3D model in FreeCAD and exported as STEP format
    - Integrated STEP model into KiCAD library for 3D visualization
    - Downloaded component datasheet for reference documentation
    [SW18030.FCStd]
2025-08-24 🧹 Clean up obsolete IgnisV1 PCB and update electrical design
    - Removed obsolete IgnisV1 PCB files (kicad_pcb, kicad_sch, etc.)
    - Replaced MCP73871 with BQ24073 charger IC throughout documentation
    - Updated BQ24073 component calculations (RISET, RTMR, RILIM)
    - Added comprehensive SW18030 shock sensor filter calculations
    - Updated thermal analysis for BQ24073 switching charger
    - Reorganized component sections and obsolete design history
    [IgnisV1.kicad_pcb, IgnisV1.kicad_sch, power_stage.kicad_sch]
2025-08-24 📝 Update commit message guidelines for clarity and consistency
    - Copilot Instructions
2025-08-24 🤩 Complete IgnisV2 PCB redesign with BQ24073 and improved manufacturability
    - Created new IgnisV2 KiCAD project with hierarchical schematic design
    - Migrated from MCP73871 to BQ24073 charger IC with proper footprint
    - Sourced all components from JLCPCB with verified availability and footprints
    - Removed on-board UPDI programming (moved to external programmer board)
    - Added comprehensive test points for debugging and validation
    - Implemented component placeholders for field tweaking without PCB respins
    - Added solder jumpers for critical paths to enable post-manufacture corrections
    - Generated complete BOM (CSV) and schematic documentation (PDF)
    - Updated component libraries with new 3D mo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
    [IgnisV2.csv, IgnisV2.kicad_pcb, IgnisV2.kicad_sch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]
2025-08-25 🎨 Fix SW-18030 3D model colors for proper KiCAD STEP export
    - Updated FreeCAD model colors to export correctly in STEP format
    - Fixed KiCAD transparency issue where #000000 renders as transparent
    - Changed black surfaces to #010101 minimum to ensure visibility
    - Updated both STEP file and KiCAD footprint with corrected model
    Note: KiCAD treats exact #000000 color as transparent in STEP models.
    Use #010101 or darker grays for proper black appearance.
    [SW18030.FCStd]
2025-08-25 🏭 Finalize IgnisV2 PCB design and prepare for JLCPCB production
    - Polished hierarchical schematics with clean signal routing
    - Completed full PCB layout with optimized component placement
    - Refined component selection for optimal JLCPCB compatibility
    - Generated production files (Gerbers, drill, BOM, pick&place) for fabrication
    - Exported 3D model snapshot for documentation and review
    - Added 74LVC1G17 datasheet for package selection reference
    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
    [IgnisV2.kicad_pcb, function_stage.kicad_sch, positions.csv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]
2025-08-26 🚨 Fix critical PCB issues caught during JLCPCB review
    - Fixed undersized vias (<0.3mm) in component footprints to avoid extra costs
    - Corrected WS2812B symbol pinout mismatch between standard and 2020 package
    - Updated WS2812B-2020 wiring to match proper pin assignments
    - Regenerated production files with corrected drill sizes and routing
    **Critical catch: WS2812B standard vs 2020 package have different pinouts!**
    Production halted and corrected before fabrication.
    [IgnisV2.csv, IgnisV2.kicad_pcb, IgnisV2.step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]
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2025-08-30 🎨 Complete logo cleanup and rebranding with new typography
    - Changed official logo font from Museo Rounded to "Dongle" Bold
    - Reorganized logo assets with consistent naming convention
    - Added Makefile for automated PNG export in multiple variants and sizes
    - Updated KiCAD worksheets for both IgnisV1 and IgnisV2 PCBs with new branding
    - Removed obsolete logo files and consolidated SVG sources
    - Exported updated schematic PDFs with refreshed corporate identity
    [IgnisV1-TP4056.kicad_sch, IgnisV2.kicad_pcb, IgnisV2.kicad_sch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]
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2025-08-31 📐 Add mechanical visualization models for component assembly
    - Created BatteryPack.FCStd for visualizing battery placement in lamp assembly
    - Added Coil.FCStd to model power receiving coil positioning
    - Imported IgnisV2PCB.FCStd via KiCAD StepUp for PCB integration visualization
    [BatteryPack.FCStd, Coil.FCStd, IgnisV2PCB.FCStd]
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2025-09-08 🔧 Reorganize CAD models and add IgnisV2.2 test stand
    - Reorganized CAD files into logical subdirectories (SW18030/, Misc/, TestStand/)
    - Added PNG previews for all mechanical components
    - Created custom TestStand for IgnisV2.2 PCB programming and validation
    - Generated STL files for 3D printing (Top, Bottom, Hook parts)
    - Added comprehensive README with component specifications and lessons learned
    - Documented TestStand V1 issues for future improvements
    [BatteryPack.FCStd, Coil.FCStd, IgnisV2PCB.FCStd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]
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2025-09-15 🧪 Add TestStand V2 with improved design and pogo pin support
    - Created TestStandV2 addressing V1 issues (hook attachment, cable management)
    - Added proper pogo pin support for both test pads and drilled holes
    - Designed Guide/Base system with PCB alignment sticks
    - Generated complete STL set and 3MF file for 3D printing
    - Added IgnisV2TP.csv mapping test pads to connector positions and cable colors
    - Included real photos showing TestStand V2 in action with IgnisV2.2 PCB
    - Updated README with comprehensive V2 documentation and features
    [IgnisV2TP.csv, TestStandV2-Base.stl, TestStandV2-Guide.stl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]
2025-09-16 📦 Add UPDI Flasher Box CAD model and documentation
    - Created FreeCAD model for UPDI programmer enclosure
    - Added STL files for 3D printing (Top and Bottom parts)
    - Updated mechanical CAD README with complete section
    - Includes protoboard-based UPDI circuit with power selection
    [UPDIFlasherBox-Bottom.stl, UPDIFlasherBox-Top.stl, UPDIFlasherBox.FCStd]
2025-09-17 ⚙️ Fix UPDI Flasher Box mechanical dimensions
    - Corrected threaded insert holes diameter (were too wide)
    - Fixed switch slot position and alignment
    - Updated FreeCAD model and exported STL files
    [UPDIFlasherBox-Top.stl, UPDIFlasherBox.FCStd]
2025-09-22 🔍 Document inductive charging failure and troubleshooting
    - Added comprehensive analysis of IgnisV2.2 Qi charging issues
2025-10-06 ⚡ Add comprehensive UPDI programmer documentation
    - Created detailed README with circuit schematics and pinouts
    - Added Fritzing breadboard design and assembled photo
    - Documented EPLZON protoboard specifications and assembly
    - Included enclosure reference and usage instructions
    [Flasher.fzz]
2025-11-19 🉑 Translate electrical design to english and doc cosmetics
    [IgnisV2TP.csv]
